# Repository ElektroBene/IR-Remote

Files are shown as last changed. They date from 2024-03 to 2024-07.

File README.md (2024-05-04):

# IR-Remote
## Introduction
This is a project for the course "microelectrical systems and design" in the electrical engineering and computer science studies at the Aschaffenburg University of Applied Sciences. The project will contain schematics and assembly code to build a custom infrared remote with the standard RC5 protocol.

## Schematics
- v1: basic schematic to show inputs and outputs with pic18f452
- v2: proper schematic including reset circuit, quartz oscillator and power supply
- v3: proper layout with remote design
- v4: optimize inductor width, space management and add cooling area for power supply
- v5: reroute with pwm and interrupt pins, add cooling area for battery and gnd area

## Authors
Benedikt Schnörr,
Sebastian Pasinski

### Work Packages
- schematics in v1 and v2: Benedikt
- layout in v2: Sebastian
- schematics in v3: Benedikt, Sebastian
- layout in v3: Benedikt, Sebastian
- layout in v4/5: Benedikt
- code for rc5 protocol: Benedikt

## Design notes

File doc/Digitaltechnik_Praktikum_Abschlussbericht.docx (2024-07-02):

# Digitaltechnik-Praktikum

Sommer-Semester 2024

Projekt: IR-Remote

Team: Sebastian Pasinski, Benedikt Schnörr

Prüfer: Prof. Dr. Francesco Volpe

# Planung

## Aufgabenstellung

Die Aufgabenstellung für das Digitaltechnik-Praktikum ist es, eine Infrarot-Fernbedienung zu bauen. Diese soll einen Receiver ansteuern, welcher das RC5-Protokoll unterstützt. Es sollen die wichtigsten Funktionen eines CD-Players mit der Fernbedienung angesprochen werden können. Dazu gehören:

- Play
- Stop
- Pause
- Forward (vorspulen)
- Backward (zurückspulen)

## Anforderungen

Die Anforderungen für dieses System sind, dass es auf einer eigenen Platine aufgebaut und batteriebetrieben arbeiten soll. Im Verlauf des Projekts wird zunächst ein Schaltplan entworfen, der die elektrischen Bauteile und den Mikrocontroller enthält, sodass daraufhin eine Platine designt und die Bauteile bestellt werden können. Im zweiten Schritt wird dann der Code entwickelt, mit dem die gedrückte Taste auf der Fernbedienung ausgelesen und das passende Signal als RC5-Code gesendet wird.

## Anwendungsfalldiagramm

Die grundlegende Funktionsweise des Systems wird in Abb.1 dargestellt.

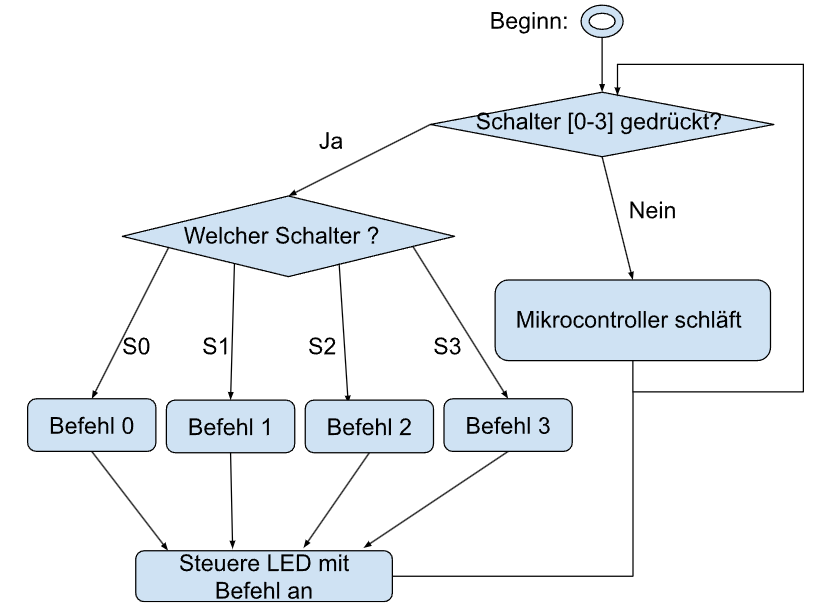
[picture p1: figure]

Abb. 1: Anwendungsfalldiagramm der Funktionsweise im System

## Skizze

In Abb. 2 ist eine grobe Skizze der Fernbedienung zu sehen, um die Funktionen der einzelnen Taster zuzuordnen.

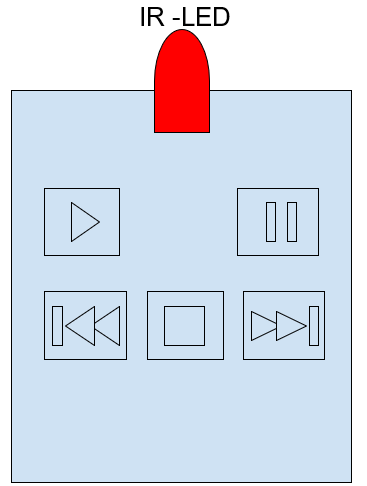
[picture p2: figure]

Abb. 2: Skizze der Fernbedienung

# Schaltplan

## Mikrocontroller

Der in der Schaltung verwendete Mikrocontroller ist ein PIC18F4525, an ihn sind neben Schaltern und Infrarot-LED noch weitere Schaltkreise angeschlossen. In Eagle wird zur Darstellung ein PIC18F4520 verwendet, der aber die gleiche Pin-Belegung und die gleichen Abmessungen wie der PIC18F4525 besitzt und daher als Alternative im Schaltplan benutzt werden kann.

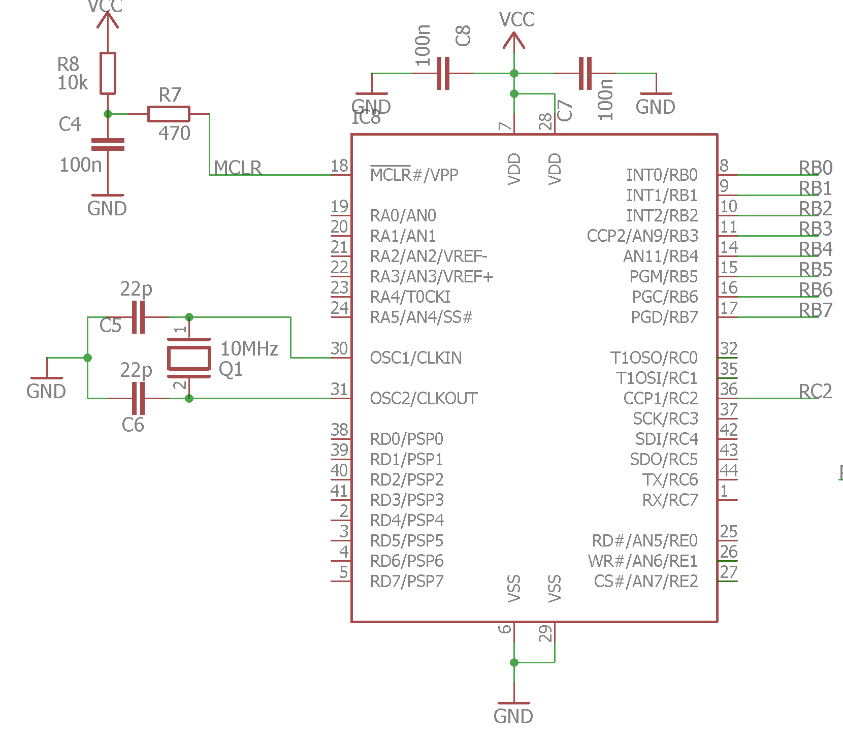
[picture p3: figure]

Abb. 3: Grundschaltung des PIC18F4525 mit Quarz, Reset und I/O

### Taktgebung

Der Quarz dient als externer Oszillator für den Mikrocontroller, der die Taktfrequenz vorgibt. Das Datenblatt des PIC18F4525 empfiehlt für die Oszillator-Konfiguration “High Speed Crystal/Resonators” mit einer Frequenz von 10 MHz die Verwendung von Kondensatoren mit einer Kapazität von 15 pF. In der vorgegebenen Schaltung wurde eine höhere Kapazität verwendet, dies verbessert die Stabilität der Schaltung, kann aber zur Vergrößerung der Startzeit führen [1].

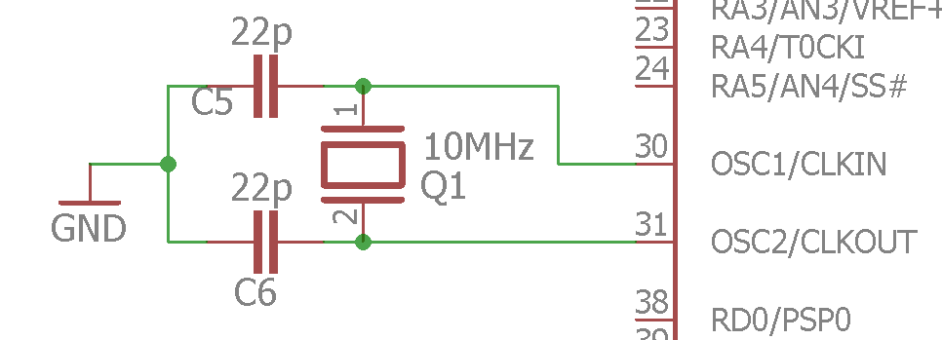
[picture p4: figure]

Abb. 4: Quarzoszillator mit Kapazitäten

## Programmier-/Debugging-Schnittstelle

Die in Abbildung 5 dargestellten Schaltungsblöcke ermöglichen das Programmieren und Debuggen des PIC [1].

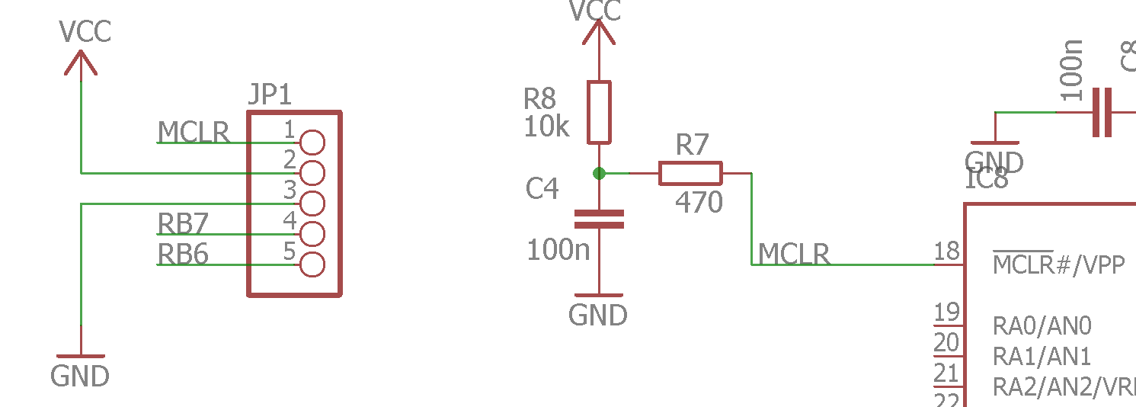
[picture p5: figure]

Abb. 5: Schnittstelle des Mikrocontrollers zum Debuggen/Programmieren

## Spannungsregulierung

Da die Schaltung laut Anforderungen mit einer 9 V-Batterie betrieben wird, muss ein Spannungsregulierer eingesetzt werden, um die Spannung auf die Betriebsspannung des PIC von 5 V zu reduzieren. In der fertigen Schaltung wird dazu der ON Semiconductor NCV1117ST50 genutzt. Im Schaltplan wird allerdings ein AP1117E50G eingesetzt, der die gleiche Pin-Belegung und Funktionsweise besitzt. Die Kapazitäten an Ein- und Ausgang sorgen dafür, dass der Regelkreis im Chip des Spannungsregulierers nicht beginnt zu schwingen. Diese Fähigkeit ist wichtig, um eine stabile Ausgangsspannung bereitzustellen.

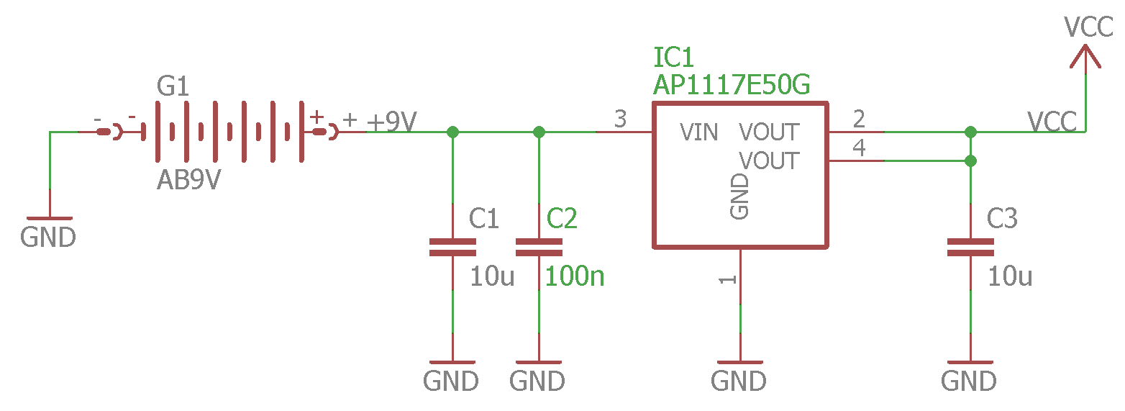
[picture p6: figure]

Abb. 6: Batterie mit Spannungsregulierer und Kapazitäten

## Schalter

Die Schalter, welche an verschiedenen Pins von Port B des Mikrocontrollers angeschlossen sind, sorgen dafür, dass im ausgeschalteten Zustand die Versorgungsspannung von 5 V am jeweiligen Pin anliegt. Im angeschalteten Zustand werden die Pins auf Masse gezogen.

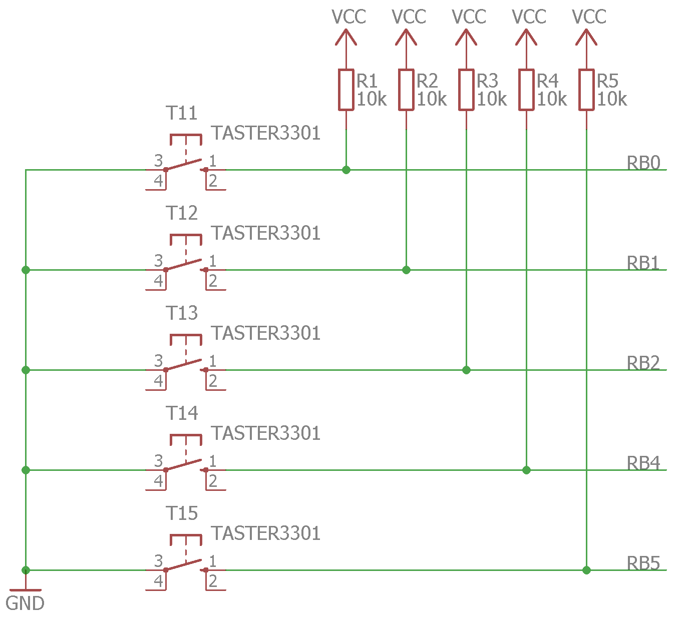
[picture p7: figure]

Abb. 7: Verschaltung der Taster als Active-Low-Elemente

## IR-LED

Für das Aussenden der Lichtsignale wird eine 5 mm Vishay Infrarot-LED verwendet. Der Vorwiderstand berechnet sich mit dem Spannungsabfall an der LED und dem gewünschten Strom im diesem Zweig. Laut Datenblatt liegt die Nennspannung bei 1,35 V, der Nennstrom kann bis zu 100 mA betragen [5]. Mit dem Ohm’schen Gesetz ergibt sich ein Widerstand von 36,5 Ω. Mit dieser Berechnung wird ein Widerstand von 47 Ω gewählt, damit der Strom durch die LED mit Sicherheit nicht zu groß wird.

Die LED wird an Pin RC1 angeschlossen, da an diesem Pin mit wenig Aufwand eine modulierte Rechteckspannung mit dem PWM-Modul des PIC ausgegeben werden kann. Diese wird für das RC5-Protokoll benötigt.

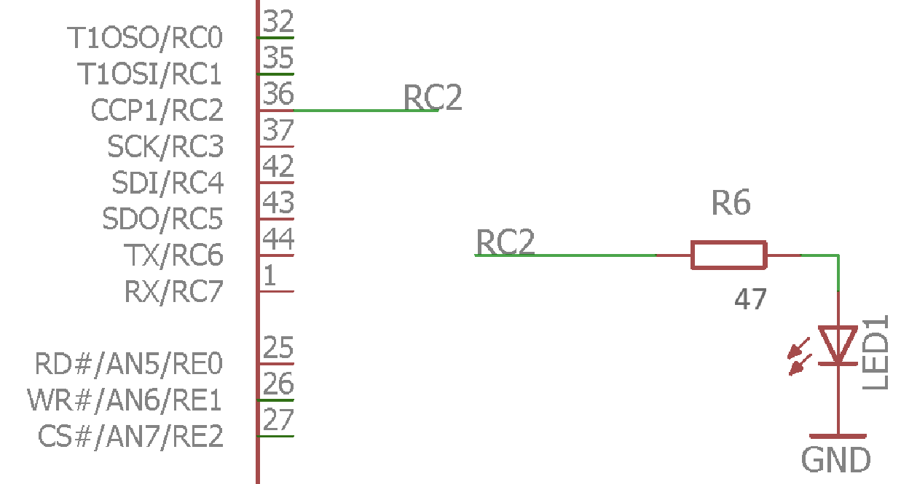
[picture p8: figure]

Abb. 8: Verschaltung der IR-LED mit Vorwiderstand

# Layout

In Abb. 9 ist das finale Layout zu sehen, mit dem auch die reale Platine erstellt wurde.

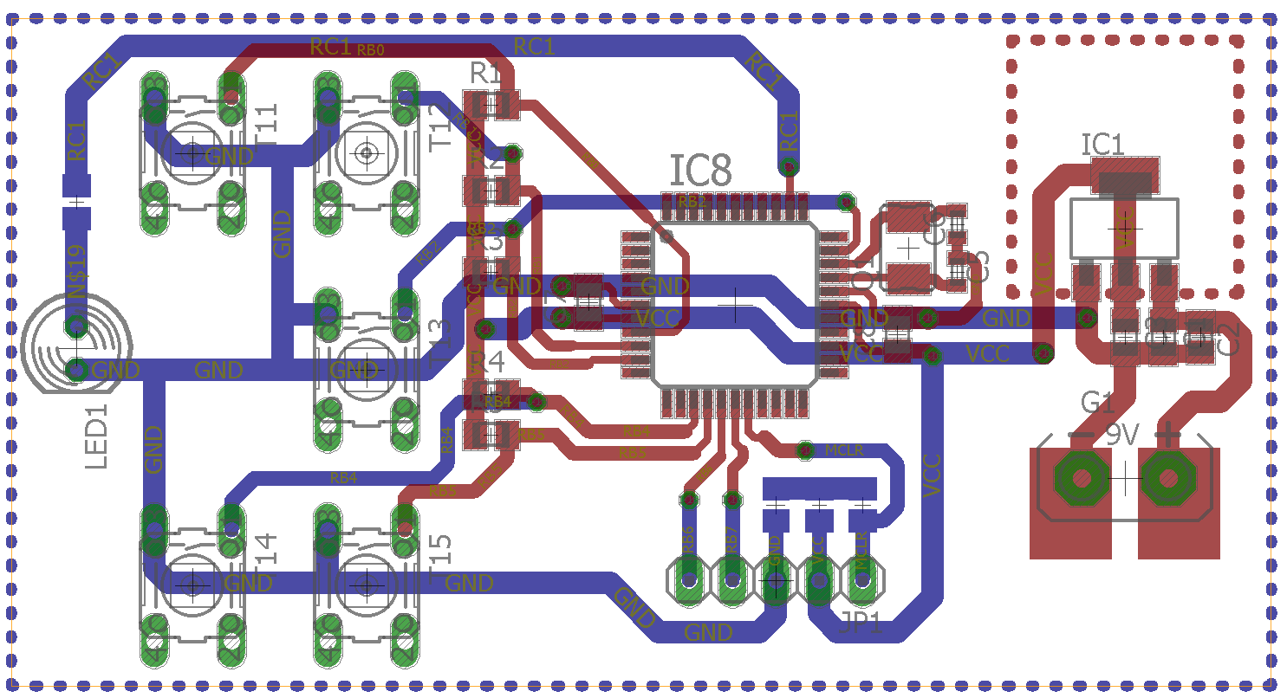
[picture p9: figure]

Abb. 9: PCB-Layout in Eagle mit Platzierung und Routing

## Anordnung der Bauteile

Beim Layout werden zuerst funktionale Gruppen mit Bauteilen, die direkt miteinander verbunden sind, gebildet. Diese werden dann auf der Platine angeordnet. Die funktionale Gruppe um den Quarz sollte möglichst nah an den angeschlossenen Eingängen des Mikrocontrollers liegen, da der Quarz sehr anfällig gegenüber Störsignalen ist.

Die Kondensatoren C7 und C8 liegen ebenfalls möglichst nah an den verbundenen Pins zur Stromversorgung, um Schwankungen in der Versorgungsspannung durch Störungen möglichst schnell auszugleichen.

Zusätzlich ist bei der Spannungsregulierung eine Kühlfläche vorgesehen, um die entstehende Wärme möglichst gut zu verteilen und den Chip dadurch zu kühlen.

Die Taster werden so angeordnet wie das bei handelsüblichen Fernbedienungen der Fall ist und in Abb.2 skizziert wurde. Auch die Anordnung der LED am vorderen und die der Batterie am hinteren Ende der Fernbedienung wird aus bekannten Fernbedienungen übernommen.

## Routing

Beim Routing wird besonders darauf geachtet, genug Abstand zwischen den Leiterbahnen einzuhalten und möglichst breite Leiterbahnen und keine rechten Winkel zu verwenden. Diese Grundsätze helfen, elektromagnetische Störungen zu minimieren.

Die Unterseite der Platine besteht zum größten Teil aus einer Masse-Fläche, so werden Masse-Schleifen vermieden und das Routing der Masse-Leitungen vereinfacht [6].

Die Größe und Form der Durchkontaktierungen, die Breite der Leiterbahnen und die Dimensionen von Tastern und SMD-Bauteilen wurden in Absprache mit dem Labor gewählt.

## Platine

Die fertige Platine ist in den Abbildungen 10 und 11 zu sehen.

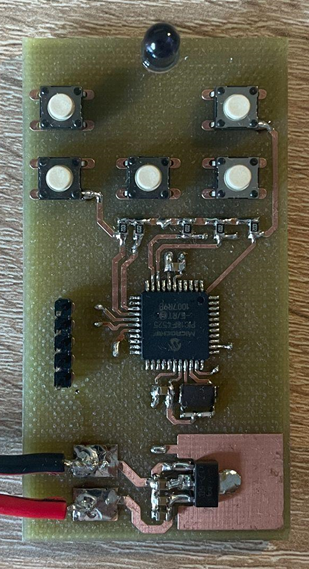
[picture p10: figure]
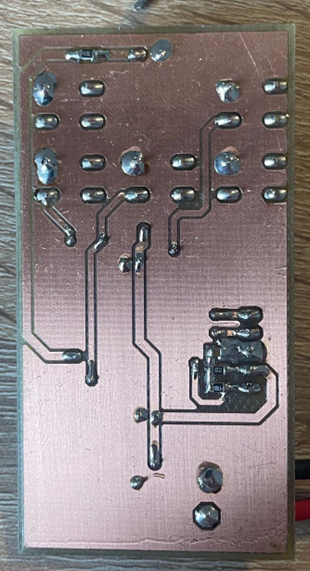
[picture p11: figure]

Abb. 10 (links): Fertige Platine obere Seite, Abb. 11 (rechts): untere Seite

# Software

Nachdem die Hardware fertiggestellt ist, fehlt für eine funktionsfähige Fernbedienung nur noch die Programmierung des Mikrocontrollers. Diese wird zunächst in 2 Teile aufgeteilt. Der erste Teil beschäftigt sich mit dem Auslesen der gedrückten Taster und dem Zuordnen von Taster und Befehl. Im zweiten Teil wird der Befehl dann mit dem RC5-Protokoll gesendet.

## Einsatz von Interrupts

Damit eine dauerhafte Schleife im Hauptprogramm vermieden werden kann, welche die Pegel an den Pins abfragt, kann die Interrupt-Funktion des Mikrocontrollers verwendet werden. So kann der PIC die meiste Zeit in den Sleep-Modus versetzt werden und spart dadurch Energie.

Das Hauptprogramm wird im Sleep-Modus gestoppt. Dann kann jederzeit durch eine Spannungsänderung an einem Interrupt-Pin eine Unterroutine aufgerufen werden, die den gedrückten Taster ausliest und den passenden Befehl sendet.

Der Ablauf dabei ist wie folgt: Bei einem Interrupt vervollständigt der Microcontroller die letzte Anweisung und speichert den Inhalt des Program-Counters und des Status-Registers auf dem Stack. Dann lädt er automatisch die Adresse 0x0008 (spezifisch bei PIC18F4525) in den Program-Counter und springt so an diese Stelle im Programm, um dort eine vom Benutzer geschriebene Routine auszuführen. Vor der letzten Anweisung muss das entsprechende Interrupt Flag, welches gesetzt wurde, um das Auftreten der Unterbrechung zu kennzeichnen, wieder zurückgesetzt werden. Die letzte Anweisung der Routine sorgt für eine sichere Rückkehr des Program-Counters zum aktuellen Befehl in der Hauptroutine, weitere Unterbrechungen werden dann wieder ermöglicht [3].

## Initialisierung der Interrupts im Programm

In der Fernbedienung werden verschiedene Interrupts genutzt. Die Taster an den Pins RB 0, 1 und 2 lösen die flankengesteuerten, externen Interrupts INT0, INT1 und INT2 aus. Die Pins RB 4 und 5 dagegen lösen Port B On Change-Interrupts aus, welche auf Zustandsänderungen der beiden Pins reagieren. Diese Interrupts werden im Folgenden initialisiert.

Dies geschieht durch das Setzen oder Rücksetzen spezieller Bits in den passenden Konfigurations-Registern, um die Einstellungen der Interrupts festzulegen.

Dabei ist es wichtig die Interrupt-Flags zurückzusetzen, damit keine fälschliche Unterbrechung stattfindet, bevor das Hauptprogramm gestartet wird. Außerdem werden die Interrupts durch das Setzen des jeweiligen Interrupt Enable-Bits aktiviert und ihre Priorität festgelegt. Im Fall von INT0/INT1/INT2 wird auch die Flanke angegeben, bei welcher ein Interrupt ausgelöst wird. Am Ende werden die Global Interrupt Enable-Bits gesetzt, um die Interrupts mit hoher und niedriger Priorität im Allgemeinen zu aktivieren.

init_portb:

clrf PORTB ; reset port b and its latch

clrf LATB

bcf ADCON0,ADON

; disable ad converter and reset its configuration bits

movlw 0xFF ; declare all Pins at PORTB as digital

movwf ADCON1 ; pins

movlw 0xFF ; set all port b pins as inputs

movwf TRISB

movlw b'00111011' ; set pins with buttons to '1' to prevent

movwf PORTB

;triggering interrupt because buttons

;create high state as default (active low buttons)

bcf INTCON,INT0IF ; clear interrupt flags for pins rb

bcf INTCON3,INT1IF ; 0/1/2/4/5 to prevent getting multiple

bcf INTCON3,INT2IF ; interrupts with one button press

bcf INTCON,RBIF

bcf INTCON2,RBPU

; activate internal weak pull-ups for all pins on port b

bsf INTCON,INT0IE

bsf INTCON3,INT1IE

bsf INTCON3,INT2IE

bsf INTCON,RBIE

; enable interrupts for interrupt 0/1/2 and on change

; interrupts on port b

bcf INTCON2,INTEDG0

bcf INTCON2,INTEDG1

bcf INTCON2,INTEDG2

; set interrupts 0/1/2 to trigger on falling edge

bsf RCON,IPEN ; enable interrupt priorities

bsf INTCON3,INT1IP

; set interrupt priority for interrupts 1 & 2 , (0 always high)

bsf INTCON3,INT2IP

; and on change interrupt to high priority

bsf INTCON2,RBIP

bsf INTCON,GIEH

; activate all high priority interrupts

bsf INTCON,GIEL

;activate all low priority interrupts

bsf INTCON,GIE

; activate all interrupts

return

## Interrupt-Routine

Um in der Anwendung des Programms nachvollziehen zu können, welcher Schalter gedrückt wurde, wurde innerhalb der High Interrupt Routine ein Algorithmus implementiert, welcher die jeweiligen Interrupt-Flags und die Zustände der Pins abfragt. Wenn der entsprechende Schalter erkannt wurde, wird eine Sendefunktion mit einem bestimmten RC5-Befehl ausgeführt, welche dann den passenden Befehl lädt.

HighInt:

btfsc INTCON,RBIF ; pin 4/5 pressed

call send_rb_on_change

btfsc INTCON,INT0IF ; pin 0 pressed

call send_rb_0

btfsc INTCON3,INT1IF ; pin 1 pressed

call send_rb_1

btfsc INTCON3,INT2IF ; pin 2 pressed

call send_rb_2

retfie FAST

In der Interrupt-Routine wird also zuerst ermittelt, ob sich eine Änderung an den Pins RB4 und RB5 ereignet hat. In der Routine send_rb_on_change wird dann mit den Pin-Zuständen ermittelt, welcher Pin genau für den Interrupt verantwortlich war.

send_rb_on_change:

btfss PORTB,4 ; check if pin 4 was pressed

call send_rb_4

btfss PORTB,5 ; check if pin 5 was pressed

call send_rb_5

bcf INTCON,RBIF ; clear interrupt flag to prevent multiple

; interrupts

return

In den daraufhin aufgerufenen Sende-Routinen wird das Interrupt-Flag zurückgesetzt, um mehrfache Unterbrechungen zu vermeiden und wieder in das Hauptprogramm zu springen. Außerdem wird der Bit-Buffer, welcher die Befehle zum Senden enthält, mit dem passenden Befehl überschrieben. Hier ist beispielhaft eine Sende-Routine dargestellt.

send_rb_0:

bsf skip_release,0 ; set skip_release<0> to prevent

; skipping this command

movlw b'00110101' ; move rc5 code for stop command to

movwf bit_buffer_h ; bit buffer

movlw b'00110110' ; 00 in beginning not significant

movwf bit_buffer_l

bcf INTCON,INT0IF ; clear interrupt flag to prevent

; multiple interrupts

return

Die Schnittstelle wurde am Modell getestet, um das Programmverhalten beim Drücken der Taster zu beobachten.

## Bitübertragung mit dem RC5-Protokoll

Das RC5-Protokoll ist eine von Philips entwickelte Methode zur Kommunikation mit verschiedenen Endgeräten, wie z.B. CD-Spielern und Fernsehern. Eine Fernbedienung für dieses Protokoll sendet mit einer Wellenlänge von 940 bis 950 nm, welche bei der verwendeten Infrarot-LED mit 940 nm gegeben ist. Ein Befehl der Fernbedienung besteht aus insgesamt 14 Bits, die nacheinander gesendet werden. Die Bits sind in Abb. 13 dargestellt und haben die folgende Bedeutung [7]:

- 2 Start-Bits, immer logisch ‚1’
- 1 Toggle-Bit, welches seinen Wert bei jedem neuen Tastendruck ändert
- 5 Adress-Bits, um ein konkretes Gerät anzusprechen, wie bspw. CD-Player, TV, Audio-Vorverstärker
- 6 Befehls-Bits

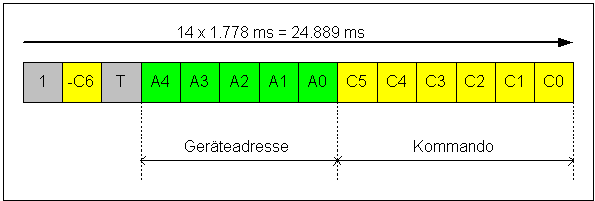
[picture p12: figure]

Abb. 12: Zeitliche Abfolge der Bits im RC5-Befehl

Ein Bit besteht dabei immer aus einer Low-Phase und einer Puls-Phase mit einer Länge von je 888,89 μs. Wie in Abb. 12 zu sehen, verändert die Reihenfolge dieser zwei Phasen den Zustand des Bits zwischen High und Low [7].

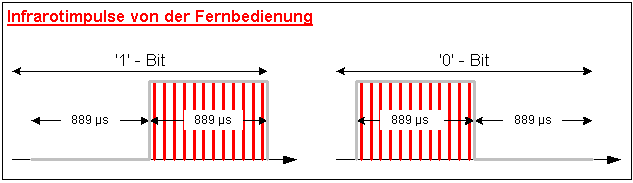
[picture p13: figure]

Abb. 13: Reihenfolge der Puls- und Ruhephasen und deren Bedeutung als Bit

Eine Puls-Phase besteht dabei immer aus 32 einzelnen Pulsen einer Rechteckspannung mit einer Frequenz von 36 kHz. Die Dauer der High-Phasen der einzelnen Pulse ist etwa ⅓ bis ¼ der Periodendauer der Rechteckschwingung. So wird weniger Leistung benötigt, als bei einer High-Phase von 50%.

## Konfiguration des PWM-Moduls

Die Rechtecksignale werden an Pin RC1 mit dem „Capture/Compare/PWM Module (CCP)” im PWM-Modus erzeugt. Alle nachfolgenden Ausführungen beruhen auf Informationen im Kapitel 15.4 des Handbuchs für den PIC18F4525 [1].

Bei der Konfiguration wird zunächst die Periodendauer bzw. Frequenz der benötigten Trägerschwingung definiert. Diese kann über die Gleichungen 1 und 2 berechnet werden.

T_(Period) =[n_(PR2) +1]⋅4⋅T_(OSC) ⋅n_(TMR)

Gleichung 1

n_(PR2) =(f_(OSC))/(4⋅f_(Period) ⋅n_(TMR))-1≈44h

Gleichung 2

Die Frequenz fPeriod ist dabei die Träger-Frequenz von 36 kHz. Die Frequenz des Oszillators fOSC ist durch den 10 MHz-Quarz vorgegeben. Der Prescaler-Value nTMR = 1 wird aus den Beispielen im Handbuch gewählt. Der berechnete Wert nPR2 wird bei der Konfiguration in das PR2-Register eingetragen, um die gewünschte Frequenz der Rechteckspannung zu erreichen. Durch Leitungsverzögerungen und Ungenauigkeiten in der Schaltung muss dieser Wert im realen Programm angepasst werden.

Außerdem muss der Wert für den Duty Cycle berechnet und eingestellt werden. Aus Gleichung 3, die von Microchip vorgegeben wurde [8], ergibt sich ein Wert von 0,250. Da dieser Wert in diesem Zusammenhang nicht als zehnstellige binäre Zahl dienen kann, wird dieser Wert experimentell zu 0x54 bestimmt. Die ersten acht MSBs werden in das CCPR2L-Register und die zwei verbleibenden LSBs in das CCP2CON-Register an Stelle 5 und 4 eingetragen.

Pulse Width=(CCPR2L:CCP2CON<5:4> ⋅1/(f_(OSC))⋅n_(TMR) )

Gleichung 3

init_pwm:

banksel PR2

movlw 0x46 ; configure period time with 0x46 for

movwf PR2 ; 36 kHz frequency

movlw b'00010101' ; configure duty cycle to be between 1/3

movwf CCPR2L ; and 1/4 of the whole signal

movlw b'00001100' ; configure pwm mode and 2 lsbs of

movwf CCP2CON ; duty cycle

bcf PIR1,TMR2IF ; clear interrupt flag to prevent

; multiple interrupts

bcf T2CON,T2CKPS1 ; set timer 2 clock prescaler value

bcf T2CON,T2CKPS0 ; to ‘00’

## Konfiguration von Timer 0

Während die Rechteckspannung von CCP-Modul und Timer 2 erzeugt wird, muss auch die Sendedauer der Rechteckspannung reguliert werden. Wie bereits erwähnt, werden in der Sendephase für jedes Bit 32 Pulse gesendet, dies entspricht einer Dauer von 888,89 μs. Diese Sendedauer wird von Timer 0 beendet, der von einem entsprechend eingestellten Wert bis zum Überlauf hochzählt. Beim Überlauf von 0xFFFF zu 0x0000 wird ein Interrupt erzeugt, über dessen Interrupt Service Routine dann die Sendephase beendet werden kann. Der Startwert des Timers ergibt sich durch die Berechnungen in Gleichung 4 [9].

f_(OSC) =10MHz → f_(Timer) =(f_(OSC))/4=2,5MHz→T_(Timer) =1/(f_(Timer))=0,4μs

n_(Timer) =65536-(T_(Sendedauer))/(T_(Timer))=65536-(888,89μs)/(0,4μs)≈0xF752

Gleichung 4

Im Code wird der Timer dann als 16 Bit-Timer konfiguriert, der mit der Taktfrequenz des PIC vom Startwert 0xF752 hochzählt. Der Prescaler-Wert folgt ebenfalls aus den Berechnungen und kann hier auf “000” gesetzt werden. Außerdem wird für den Overflow von Timer 0 ein Low Priority Interrupt aktiviert, der, wie bereits erwähnt, das Ende der Dauer eines halben gesendeten Bits markiert.

movlw b'00001000' ; configure timer 0 with 16 bit, internal

movwf T0CON ; clock and prescaler value of '000'

movlw 0xF7 ; set start value for timer 0

movwf TMR0H

movlw 0x52

movwf TMR0L

bcf INTCON,TMR0IF ; clear interrupt flag to prevent multiple

; interrupts

bsf INTCON,TMR0IE ; enable timer 0 interrupt

bcf INTCON2,TMR0IP ; set interrupt priority to low

bsf INTCON,GIE ; enable all interrupt

## RC5-Übertragung im Code

Der folgende Code-Ausschnitt zeigt beispielhaft die Übertragung einer logischen ‚0’ in Assembler. Dabei wird aus der Main-Routine die entsprechende Sende-Routine aufgerufen, die dann zuerst 888,89 μs lang die 32 Pulse der Rechteckspannung sendet und dann 888,89 μs lang den Ausgang auf den Low-Zustand legt.

send_0:

call pwm_delay ; send logic '0' by first sending 32 pwm

call tmr_delay ; pulses and then 889 us delay

return

In der pwm_delay-Routine werden Timer 0 und Timer 2 auf ihre Anfangswerte gesetzt und dann gestartet. Beim Ausführen des Codes auf dem realen PIC wurde festgestellt, dass der erste Puls nur aus einer Low-Phase besteht, daher wird der Ausgangspin vor dem Starten des ersten Pulses manuell gesetzt.

pwm_delay:

movlw 0xF7 ; set start value for timer 0 which

movwf TMR0H ; counts to overflow

movlw 0x70

movwf TMR0L

movlw 0x00 ; set start value for timer 2 which

movwf TMR2 ; counts for each pulse

bsf LATC,1 ; set first pulse manually

bsf T0CON,TMR0ON ; start timer 0 for 889 us delay

bsf T2CON,TMR2ON ; and timer 2 for pwm

call delay_loop ; wait for timer 0 low interrupt

return

Die tmr_delay-Routine ist ähnlich aufgebaut. Sie startet allerdings nur Timer 0 und nicht Timer 2, da für die Ruhephase nur Timer 0 gebraucht wird, um die 888,89 μs abzuzählen.

tmr_delay:

;start timer 0 for pausing

movlw 0xF7 ; set start value for timer 0 which counts

movwf TMR0H ; to overflow

movlw 0x70

movwf TMR0L

bsf T0CON,TMR0ON ; start timer 0

call delay_loop ; wait for timer 0 low interrupt

return

Außerdem gibt es noch eine Routine, die durchlaufen wird, bis ein Timer 0 Low Interrupt ausgelöst wird. Diese Schleife wartet darauf, dass das tmr_done-Flag von der Low Interrupt-Routine gesetzt wird.

delay_loop: ;wait for timer 0 interrupt to end half bit

btfss tmr_done,0

bra delay_loop

bcf tmr_done,0

return

In der Low Interrupt-Routine werden dann die Timer gestoppt, die das halbe Bit erzeugen, und das bereits erwähnte tmr_done-Flag gesetzt.

LowInt:

bcf T0CON,TMR0ON ; stop timers 0 and 2 which are used for

bcf T2CON,TMR2ON ; pwm pulses and do not need to be used

; after sending these pulses is finished

bcf INTCON,TMR0IF ; clear interrupt flag of timer 0 which

; triggers the low interrupt, clearing

; prevents multiple interrupts for one

; overflow event

bsf tmr_done,0

retfie FAST

## Main-Routine

In der Main-Routine, die zuerst ausgeführt wird, werden zunächst alle Routinen zur Initialisierung aufgerufen. So werden die Kontrollbits für die Ein- und Ausgangsports und das PWM-Modul, wie in den vorherigen Abschnitten angesprochen, passend gesetzt.

Main:

call init_portc ; configure ports and pwm module

call init_portb

call init_ports

call init_pwm

Dann wird der Mikrocontroller direkt in den Sleep-Modus versetzt, um dort auf den nächsten Tastendruck und den dadurch ausgelösten Interrupt zu warten. Dazu wird das IDLEN-Bit zurückgesetzt, womit der Modus des Mikrocontrollers ausgewählt werden kann.

wait_cmd_loop

bcf OSCCON,IDLEN ; go to sleep until next button is pressed

sleep

nop

nop

nop

Nachdem der PIC dann durch einen Tastendruck in den normalen Run-Modus versetzt und der gewünschte Befehl in der Interrupt-Routine in den Bit-Buffer kopiert wurde, wird das Toggle-Bit des Befehls angepasst. Wie im Abschnitt zur Theorie hinter dem RC5-Code erwähnt, toggelt dieses Bit bei jedem neu gesendeten Befehl. Das Toggeln und Setzen im Bit-Buffer ist im folgenden Code-Abschnitt dargestellt.

btg bit_buffer_toggle,0 ; set toggle bit in bit_buffer

btfsc bit_buffer_toggle,0

bsf bit_buffer_h,3

btfss bit_buffer_toggle,0

bcf bit_buffer_h,3

Dann werden die Sende-Routinen gestartet. Dazu werden die Bits des Bit-Buffers nach und nach in das Carry-Bit übernommen und dann die passende Sende-Routine für eine logische ‚0’ oder ‚1’ gestartet. Damit der Bit-Buffer seinen Wert behält und beim Senden nicht verloren geht, werden die Schiebe-Operation mit einem temporären Bit-Buffer durchgeführt, dessen Wert vor dem Senden aus dem Bit-Buffer kopiert wird.

Die ersten zwei Bits werden beim Senden übersprungen, da ein Befehl beim RC5-Code immer nur 14 Bits enthält. Der Bit-Counter zählt diese 14 Bits ab und beendet die Sende-Schleife, wenn alle Bits gesendet wurden.

send_cmd_loop

movlw d'14' ; send 14 bits

movwf bit_ctr

clrf tmr_done ; reset flag that stops delay loop

; during sending

movf bit_buffer_h,W ; send bit buffer from temporary

; constants to keep value

movwf bit_buffer_h_tmp

movf bit_buffer_l,W

movwf bit_buffer_l_tmp

rlcf bit_buffer_l_tmp ; skip first 2 bits because only 14

rlcf bit_buffer_h_tmp ; bits hold information

rlcf bit_buffer_l_tmp

rlcf bit_buffer_h_tmp

send_bit_loop

rlcf bit_buffer_l_tmp ; transfer the next bit that should

rlcf bit_buffer_h_tmp ; be sent in carry bit

btfss STATUS,C ; test carry bit to see if '0' or

call send_0 ; '1' should be sent

btfsc STATUS,C

call send_1

decfsz bit_ctr ; send next bit if not all bits are

bra send_bit_loop ; sent already

Dieser Sende-Vorgang wird für den zu sendenden Befehl mehrmals wiederholt. Dies beruht auf der Beobachtung, dass der Empfänger bei einzeln gesendeten Befehlen nicht zuverlässig reagiert. Das mehrmalige Senden simuliert einen längeren Tastendruck, da ein richtiger Algorithmus für längere Tastendrücke aus Zeitgründen nicht realisiert werden konnte. Hierfür wird der Command-Counter zuerst mit der Anzahl der für einen Tastendruck gesendeten Befehle initialisiert.

movlw d'3' ; send every command 3 times

movwf cmd_ctr

Dieser Counter wird nach dem Senden des Befehls dekrementiert, um die Sende-Routine so oft durchzuführen, wie bei der Initialisierung gewünscht.

decfsz cmd_ctr ; send command again if it was not sent 3

bra send_cmd_loop ; times already

Zwischen den gesendeten Befehlen wird mit dem folgenden Code-Abschnitt eine Pause eingebaut. So kann der Empfänger besser zwischen den Befehlen unterscheiden. Dieses Prinzip wurde der tatsächlichen Fernbedienung des CD-Spielers entnommen. Der Code besteht aus zwei verschachtelten Schleifen, deren Zähler nacheinander herunterzählen. Die Verzögerung, die durch diesen Code entsteht, liegt bei ca. 9 ms.

movlw 0xFF ; load inner and outer delay counter to

movwf rand_delay_ctr ; create delay between sending the

movlw 0x40 ; command multiple times

movwf rand_delay_ctr_outer

wait_rand_delay_outer ; create delay of around 9 ms

wait_rand_delay

nop

nop

decfsz rand_delay_ctr

bra wait_rand_delay

decfsz rand_delay_ctr_outer

bra wait_rand_delay_outer

Wenn der Befehl mehrmals gesendet wurde, wird der PIC wieder in den Sleep-Modus versetzt, um auf den nächsten Befehl zu warten.

bra wait_cmd_loop ; go to sleep after sending 3 commands

Eine weitere Beobachtung war, dass der Befehl beim Drücken der Taster an den Pins RB4 und RB5 zweimal gesendet wurde. Die On Change-Interrupts dieser Pins sind nämlich sowohl auf die steigende, wie auch auf die fallende Flanke sensitiv. Als Lösung wird das skip_release-Flag eingeführt. Dieses wird bei jedem der zwei ausgelösten Interrupts getoggelt, sodass es für die zwei Flanken unterschiedliche Werte hat. Das Senden des Befehls wird dann ausgesetzt, wenn das Flag den Wert ‚1’ hat, also der Interrupt beim Drücken der Taste und nicht beim Loslassen erzeugt wurde. So wird für einen Tastendruck auch nur einmal die Sende-Routine durchlaufen. Beim Interrupt durch RB0, RB1 und RB2 wird das Bit manuell in der Interrupt-Routine gesetzt, um diesen Befehl auf jeden Fall zu senden. Der folgende Code-Abschnitt zeigt den Einstiegspunkt beim Überspringen des Befehls und die Abfrage des Flags.

skip_cmd

movlw 0x00 ; initialize skip_release flag

movwf skip_release

wait_cmd_loop

bcf OSCCON,IDLEN ; go to sleep until next button is

sleep ; pressed

btfss skip_release,0 ; skip second command when button is

bra skip_cmd ; released at rb4 and rb5 because

; interrupt is triggered on change, not

; only on falling edge

# Vollständiger Code

LIST P=18F4525 ; directive to define processor

#include "P18F4525.INC" ; processor specific variable definitions

;******************************************************************************

;Configuration bits

; Oscillator Selection:

CONFIG OSC = HS ; set oscillator mode to high-speed crystal with

; external 10 MHz quartz

CONFIG WDT = OFF ; disable watchdog timer

CONFIG LVP = OFF ; disable low voltage programming, because MPLAB

; ICD 3 can do high voltage programming

;******************************************************************************

;Variable definitions

bit_buffer_h equ 0x00 ; hold bits 13-8 of command

bit_buffer_l equ 0x01 ; hold bits 7-0 of command

bit_ctr equ 0x02 ; count 14 bits while sending

tmr_done equ 0x03 ; signal that half bit is finished

cmd_ctr equ 0x04 ; count times of sending command

skip_release equ 0x05 ; decide between falling and rising edge at rb 4/5

bit_buffer_toggle equ 0x06 ; toggle 3rd sent bit

bit_buffer_h_tmp equ 0x07 ; hold bits 13-8 of command while sending

bit_buffer_l_tmp equ 0x08 ; hold bits 7-0 of command while sending

rand_delay_ctr equ 0x09 ; count during inner delay loop between commands

rand_delay_ctr_outer equ 0x0A ; count during outer delay loop between commands

;******************************************************************************

;EEPROM data

ORG 0xf00000

DE "Test Data",0,1,2,3,4,5

;******************************************************************************

;Reset vector

ORG 0x0000

goto Main ; go to start of main code

;******************************************************************************

;High priority interrupt vector

ORG 0x0008

bra HighInt ; go to high priority interrupt routine

;******************************************************************************

;High priority interrupt routine

HighInt:

call interrupt_routine ; read pressed button and put the right

; command in bit buffer to send it

bcf INTCON,INT0IF ; clear interrupt flags for pins rb

bcf INTCON3,INT1IF ; 0/1/2/4/5 to prevent getting multiple

bcf INTCON3,INT2IF ; interrupts with one button press

bcf INTCON,RBIF

retfie FAST ; pops the contents of the program counter

; previously pushed before going to the

; service routine, enables all interrupts,

; and returns control to the appropriate

; place in the main program.

;******************************************************************************

;Low priority interrupt vector

ORG 0x0018

bra LowInt ; go to high priority interrupt routine

;******************************************************************************

;Low priority interrupt routine

LowInt:

bcf T0CON,TMR0ON ; stop timers 0 and 2 which are used for pwm pulses

bcf T2CON,TMR2ON ; and do not need to be used after sending these

; pulses is finished

bcf INTCON,TMR0IF ; clear interrupt flag of timer 0 which triggers

; the low interrupt, clearing prevents multiple

; interrupts for one overflow event

bsf tmr_done,0

retfie FAST

;******************************************************************************

interrupt_routine:

; test interrupt flags to identify pressed button

btfsc INTCON,RBIF ; pin 4/5 pressed

call send_rb_on_change

btfsc INTCON,INT0IF ; pin 0 pressed

call send_rb_0

btfsc INTCON3,INT1IF ; pin 1 pressed

call send_rb_1

btfsc INTCON3,INT2IF ; pin 2 pressed

call send_rb_2

return

; handle pressing pin 4 or 5, because both pins trigger on change interrupt

send_rb_on_change:

btg skip_release,0 ; toggle skip_release flag to prevent sending

; commands twice (by pressing and releasing

; button), command is skipped when skip_release<0>

; is '0'

btfss PORTB,4 ; check if pin 4 was pressed

call send_rb_4

btfss PORTB,5 ; check if pin 5 was pressed

call send_rb_5

bcf INTCON,RBIF ; clear interrupt flag to prevent multiple

; interrupts

return

; send stop command with pin RB0

send_rb_0:

bsf skip_release,0 ; set skip_release<0> to prevent skipping this

; command

movlw b'00110101' ; move rc5 code for stop command to bit buffer

movwf bit_buffer_h

movlw b'00110110'

movwf bit_buffer_l

bcf INTCON,INT0IF ; clear interrupt flag to prevent multiple

; interrupts

return

; send forward command with pin RB1

send_rb_1:

bsf skip_release,0 ; set skip_release<0> to prevent skipping this

; command

movlw b'00110101' ; move rc5 code for forward command to bit buffer

movwf bit_buffer_h

movlw b'00110100'

movwf bit_buffer_l

bcf INTCON,INT1IF ; clear interrupt flag to prevent multiple

; interrupts

return

; send play/pause command with pin RB2

send_rb_2:

bsf skip_release,0 ; set skip_release<0> to prevent skipping this

; command

movlw b'00110101' ; move rc5 code for pause command to bit buffer

movwf bit_buffer_h

movlw b'00110000'

movwf bit_buffer_l

bcf INTCON,INT2IF ; clear interrupt flag to prevent multiple

; interrupts

return

; send mute command with pin RB4

send_rb_4:

movlw b'00110101' ; move rc5 code for play command to bit buffer

movwf bit_buffer_h

movlw b'00001100'

movwf bit_buffer_l

return

; send backward command

send_rb_5:

movlw b'00110101' ; move rc5 code for backward command to bit buffer

movwf bit_buffer_h

movlw b'00110010'

movwf bit_buffer_l

return

;******************************************************************************

;Initialization routines

; configure port c

init_portc:

clrf PORTC ; reset port c and its latch

clrf LATC

movlw b'11111101' ; set pin RC1 to be output, all other RC pins to be

movwf TRISC ; inputs

return

; configure port b as input with interrupts

init_portb:

clrf PORTB ; reset port b and its latch

clrf LATB

bcf ADCON0,ADON ; disable ad converter and reset its configuration

movlw 0xFF ; bits

movwf ADCON1

movlw 0xFF ; set all port b pins as inputs

movwf TRISB

movlw b'00111011' ; set pins with buttons to '1' to prevent

movwf PORTB ; triggering interrupt because buttons create

; high state as default (active low buttons)

bcf INTCON,INT0IF ; clear interrupt flags for pins rb

bcf INTCON3,INT1IF ; 0/1/2/4/5 to prevent getting multiple

bcf INTCON3,INT2IF ; interrupts with one button press

bcf INTCON,RBIF

bcf INTCON2,RBPU ; activate internal weak pull-ups for all pins

; on port b

bsf INTCON,INT0IE ; enable interrupts for interrupt 0/1/2 and

bsf INTCON3,INT1IE ; on change interrupts on port b

bsf INTCON3,INT2IE

bsf INTCON,RBIE

bcf INTCON2,INTEDG0 ; set interrupts 0/1/2 to trigger on falling

bcf INTCON2,INTEDG1 ; edge

bcf INTCON2,INTEDG2

bsf INTCON,GIEH ; activate all high priority interrupts

bsf INTCON,GIEL ; activate all low priority interrupts

bsf INTCON,GIE ; activate all interrupts

bsf RCON,IPEN ; enable interrupt priorities

bsf INTCON3,INT1IP ; set interrupt priority for interrupts 1/2

bsf INTCON3,INT2IP ; and on change interrupt to high priority

bsf INTCON2,RBIP

return

; configure ports a and d as inputs, routines are taken from pic18f4525 manual

init_ports

clrf PORTA ; initialize port a by clearing output data latches

clrf LATA

movlw 0x07 ; configure A/D for digital inputs

movwf ADCON1

movlw 0x07 ; configure comparators for digital input

movwf CMCON

movlw 0xFF ; initialize data direction for all pins as output

movwf TRISA

clrf PORTD ; initialize port d by clearing output data latches

clrf LATD

movlw 0FFh ; initialize data direction for all pins as output

movwf TRISD

return

; configure pwm module

init_pwm:

banksel PR2

movlw 0x46 ; configure period time with 0x46 for 36 kHz frequency

movwf PR2

movlw b'00010101' ; configure duty cycle to be between 1/3 and 1/4 of

movwf CCPR2L ; the whole signal

movlw b'00001100' ; configure pwm mode and 2 lsbs of duty cycle

movwf CCP2CON

bcf PIR1,TMR2IF ; clear interrupt flag to prevent multiple

; interrupts

bcf T2CON,T2CKPS1 ; set timer 2 clock prescaler value to '00'

bcf T2CON,T2CKPS0

movlw b'00001000' ; configure timer 0 with 16 bit, internal clock

movwf T0CON ; and prescaler value of '000'

movlw 0xF7 ; set start value for timer 0

movwf TMR0H

movlw 0x52

movwf TMR0L

bcf INTCON,TMR0IF ; clear interrupt flag to prevent multiple

; interrupts

bsf INTCON,TMR0IE ; enable timer 0 interrupt

bcf INTCON2,TMR0IP ; set interrupt priority to high

bsf INTCON,GIE ; enable all interrupts

return

;******************************************************************************

;Sending routines

; start half bit with low state by waiting for 889 us

tmr_delay:

;start timer 0 for pausing

movlw 0xF7 ; set start value for timer 0 which counts to overflow

movwf TMR0H

movlw 0x70

movwf TMR0L

bsf T0CON,TMR0ON ; start timer 0

call delay_loop ; wait for timer 0 low interrupt

return

; start half bit with rectangle signal by running pwm for 889 us

pwm_delay:

movlw 0xF7 ; set start value for timer 0 which counts to overflow

movwf TMR0H

movlw 0x70

movwf TMR0L

movlw 0x00 ; set start value for timer 2 which counts for each pulse

movwf TMR2

bsf LATC,1 ; set first pulse manually

bsf T0CON,TMR0ON ; start timer 0 for 889 us delay and timer 2 for pwm

bsf T2CON,TMR2ON

call delay_loop ; wait for timer 0 low interrupt

return

;wait for timer 0 interrupt to end half bit

delay_loop:

btfss tmr_done,0

bra delay_loop

bcf tmr_done,0

return

; send logic '1' by first sending 889 us delay and then 32 pwm pulses

send_1:

call tmr_delay

call pwm_delay

return

; send logic '0' by first sending 32 pwm pulses and then 889 us delay

send_0:

call pwm_delay

call tmr_delay

return

;******************************************************************************

;Start of main program

Main:

call init_portc ; configure ports and pwm module

call init_portb

call init_ports

call init_pwm

clrf bit_buffer_toggle

skip_cmd

; send when rb4 or rb5 pressed, skip when released

movlw 0x00

movwf skip_release

wait_cmd_loop

bcf OSCCON,IDLEN ; go to sleep until next button is pressed

sleep

nop

nop

nop

movlw d'3' ; send every command 3 times

movwf cmd_ctr

btfss skip_release,0 ; skip second command when button is released

bra skip_cmd ; at rb4 and rb5 because interrupt is triggered

; on change, not only on falling edge

btg bit_buffer_toggle,0 ; set toggle bit in bit_buffer

btfsc bit_buffer_toggle,0

bsf bit_buffer_h,3

btfss bit_buffer_toggle,0

bcf bit_buffer_h,3

send_cmd_loop

movlw d'14' ; send 14 bits

movwf bit_ctr

clrf tmr_done ; reset flag that stops delay loop during sending

movf bit_buffer_h,W ; send bit buffer from temporary constants to keep value

movwf bit_buffer_h_tmp

movf bit_buffer_l,W

movwf bit_buffer_l_tmp

rlcf bit_buffer_l_tmp ; skip first 2 bits because only 14 bits hold information

rlcf bit_buffer_h_tmp

rlcf bit_buffer_l_tmp

rlcf bit_buffer_h_tmp

send_bit_loop

rlcf bit_buffer_l_tmp ; transfer the next bit that should be sent in carry bit

rlcf bit_buffer_h_tmp

btfss STATUS,C ; test carry bit to see if '0' or '1' should be sent

call send_0

btfsc STATUS,C

call send_1

decfsz bit_ctr ; send next bit if not all bits are sent already

bra send_bit_loop

movlw 0xFF ; load inner and outer delay counter to create delay

movwf rand_delay_ctr ; between sending the command multiple times

movlw 0x40

movwf rand_delay_ctr_outer

wait_rand_delay_outer ; create delay of around 9 ms

wait_rand_delay

nop

nop

decfsz rand_delay_ctr

bra wait_rand_delay

decfsz rand_delay_ctr_outer

bra wait_rand_delay_outer

decfsz cmd_ctr ; send command again if it was not sent 3 times already

bra send_cmd_loop

bra wait_cmd_loop ; go to sleep after sending 3 commands

;******************************************************************************

;End of program

goto $

END

# Quellen

Auf alle Quellen wurde am 01.07.24 zuletzt zugegriffen.

- [1] https://ww1.microchip.com/downloads/en/devicedoc/39626e.pdf
- [2] https://www.datasheets.com/part-details/ncv1117st50-onsemi-34665214
- [3] Microcontroller Theory and Applications by Rafiquzzaman
- [4] https://www.ged-pcb-mcm.de/2018/05/13/gutes-pcb-layout-am-beispiel-des-quarzoszillators/
- [5] https://docs.rs-online.com/175a/0900766b80de9fc1.pdf
- [6] https://www.allaboutcircuits.com/technical-articles/pcb-layout-tips-and-tricks-use-a-ground-plane-whenever-possible/
- [7] https://www.opendcc.de/info/rc5/rc5.html
- [8] https://developerhelp.microchip.com/xwiki/bin/view/products/mcu-mpu/8bit-pic/peripherals/ccp/pwm/10-bit/
- [9] https://www.electronicwings.com/pic/pic18f4550-timer

# Abbildungsquellen

- Abb. 12 und 13: https://www.opendcc.de/info/rc5/rc5.html, letzter Zugriff am 01.07.24

Praktikum Digitaltechnik, Benedikt Schnörr, Sebastian Pasinski01.07.24

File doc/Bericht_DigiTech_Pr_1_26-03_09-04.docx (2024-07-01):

# Praktikum Digitaltechnik

IR - Remote

Benedikt Schnörr, Sebastian Pasinski

# Gliederung

Aufgabenstellung 3

Systemarchitektur 3

Schaltplanskizze 3

Aktivitätsdiagramm 4

Schaltplan 5

Mikrocontroller 6

Taktgebung 6

Programmier-/Debugging-Schnittstelle 6

Spannungsregulierung 7

Schalter 7

IR-LED 8

Platinendesign 8

Quellen 10

# Aufgabenstellung

Die Aufgabenstellung für das Digitaltechnik-Praktikum ist es, eine Infrarot-Fernbedienung zu bauen. Diese soll einen Receiver ansteuern, welcher das RC5-Protokoll unterstützt. Es sollen die wichtigsten Funktionen eines CD-Players mit der Fernbedienung angesprochen werden können. Dazu gehören:

- Play
- Stop
- Pause
- Previous, vorheriger Titel
- Next, nächster Titel

Die Anforderungen für dieses System sind, dass es auf einer eigenen Platine aufgebaut und batteriebetrieben arbeiten soll.

Bei unserem Vorgehen werden wir zunächst einen Schaltplan entwerfen, der die elektrischen Bauteile und den Mikrocontroller enthält, sodass daraufhin eine Platine designt und die Bauteile bestellt werden können. Im zweiten Schritt werden wir dann den Code entwickeln, mit dem die gedrückte Taste auf der Fernbedienung ausgelesen wird und das passende Signal als RC5-Code gesendet wird.

# Systemarchitektur

## Schaltplanskizze

Wir haben zunächst ein Blockschaltbild erstellt, das die wichtigsten Komponenten unserer Schaltung darstellt. Dazu gehören die Schalter mit ihren einzelnen Funktionen, der Mikrocontroller, der die IR-LED ansteuert, und der Receiver, der die gesendeten Befehle empfängt.

Mikrocontroller

Mikrocontroller

Schalter[0-4]

Infrarot-Led

RC-5

Receiver

Abb. 1: Blockschaltbild der Fernbedienung

## Aktivitätsdiagramm

Der Ablauf der Benutzung der fertigen Fernbedienung wird in einer Tabelle dargestellt.

Tabelle 1: Ablauf bei Interaktion des Benutzers

Aktoren | Aktivität
Benutzer | drückt einen Schalter in der Schaltung
Schalter [0-4] | sendet beim Drücken elektrische Signale an einen Mikrocontroller-Eingang
Microcontroller | empfängt Spannung am Eingang und sendet elektrische Signale an den Ausgang mit IR-LED
IR Led | Wandelt elektrische Spannung in Lichtsignale um
Receiver | empfängt die Lichtsignale und führt z.B “Play”-Befehl aus
Benutzer | Kann entsprechenden Befehl am Receiver erkennen

Das Aktivitätsdiagramm stellt den Ablauf noch einmal bildlich dar. Interessant dabei ist, dass sich der Mikrocontroller immer im Sleep-Modus befindet und von einem Schalter aufgeweckt wird, um Energie zu sparen, wenn keine Taste gedrückt wird.

Schalter [0-3] gedrückt?

Ja

Nein

Mikrocontroller schläft

Welcher Schalter ?

S0 S1 S2 S3

Befehl 1

Steuere LED mit Befehl an

Beginn:

Befehl 2

Befehl 3

Befehl 0

Abb. 2: Aktivitätsdiagramm für den Ablauf der Benutzereingabe

# Schaltplan

Um die Funktionsweise des Systems auch in Hardware umzusetzen, wird eine Schaltung entwickelt und daraus eine Platine gestaltet.

Abb. 3: Schaltplan in Eagle

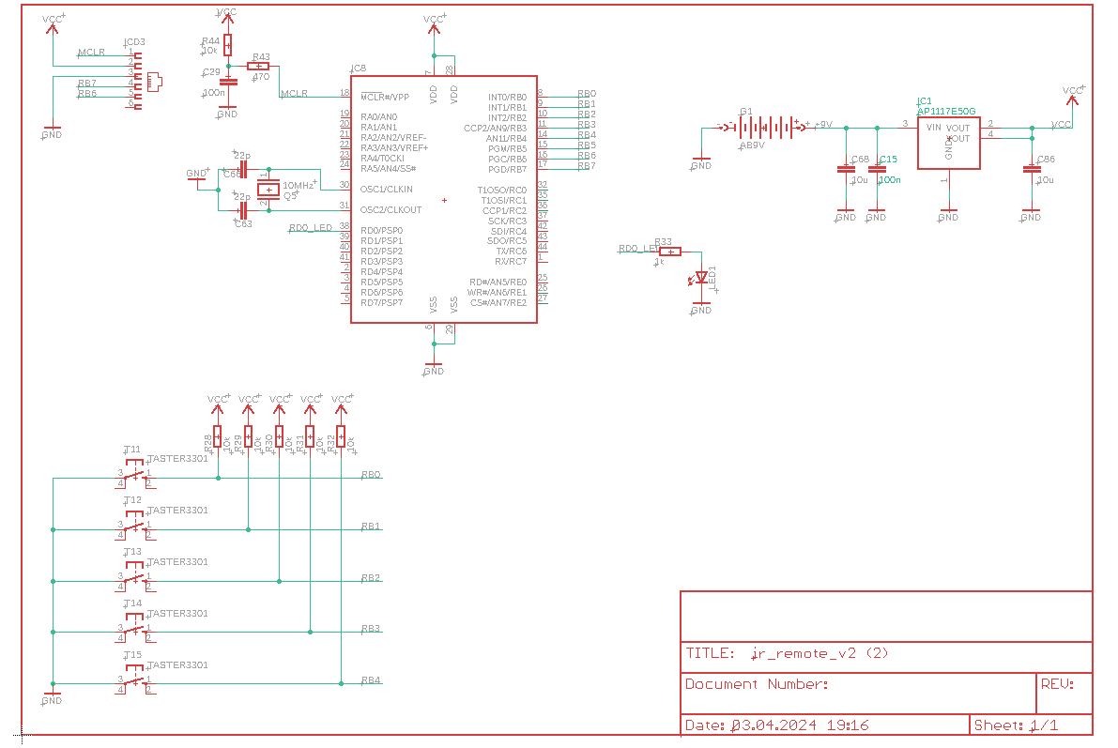
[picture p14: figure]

## Mikrocontroller

Der in der Schaltung verwendete Mikrocontroller ist ein PIC18F4525, an ihn sind neben Schaltern und Infrarot-LED noch weitere Schaltkreise angeschlossen. In Eagle wird zur Darstellung ein PIC18F4520 verwendet, der aber die gleiche Pin-Belegung und die gleichen Abmessungen wie der PIC18F4525 besitzt und daher als Alternative im Schaltplan benutzt werden kann.

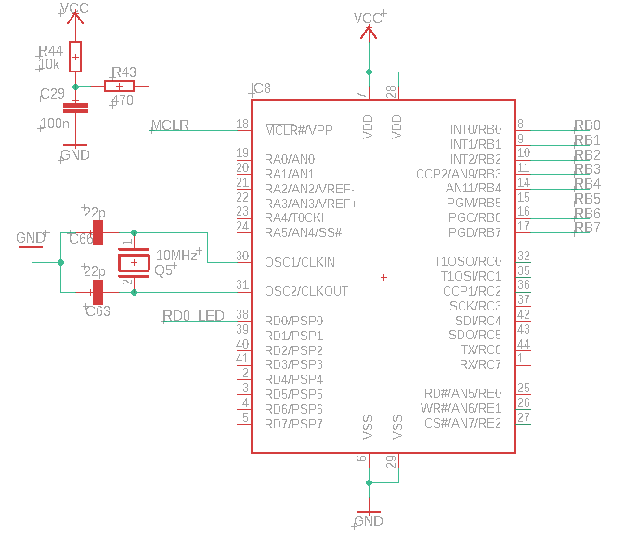
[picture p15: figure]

Abb. 4: Beschalteter PIC18F2545

### Taktgebung

Der Quarz dient dazu, dem Mikrocontroller eine Taktfrequenz bereitzustellen, nach der sich dieser richten kann. Das Datenblatt des PIC18F4525 empfiehlt für die Oszillator-Konfiguration “High Speed Crystal/Resonators” mit einer Frequenz von 10 MHz Kondensatoren eine Kapazität von 15 pF. In der vorgegebenen Schaltung wurde eine höhere Kapazität verwendet, dies verbessert die Stabilität des Schwingkreises, kann aber zur Vergrößerung der Startzeit führen [1].

### Programmier-/Debugging-Schnittstelle

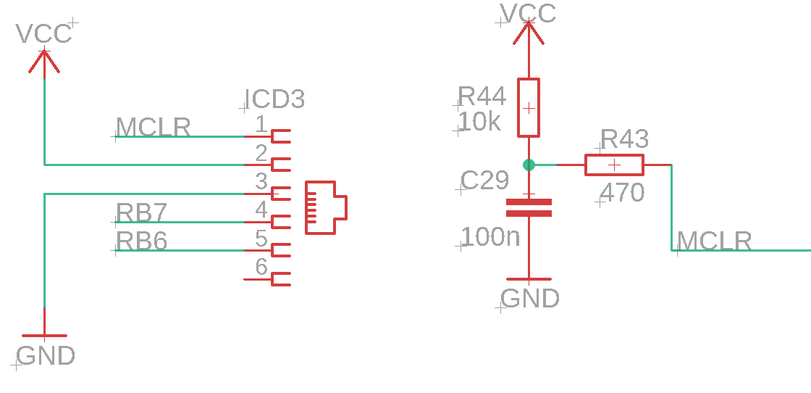
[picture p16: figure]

Abb. 6: Schnittstellen des Mikrocontrollers zum Debuggen/Programmieren

Mit diesem Schaltungsblock wird eine Schnittstelle zwischen der Software zum Programmieren und den Pins RB6 und RB7 des Mikrocontrollers hergestellt. Das Debugging des PIC kann dadurch gesteuert werden, während dieser in der Schaltung eingebaut ist [1].

### Spannungsregulierung

Der AP1117E50G wird eingesetzt, um die Spannung von einer 9 V-Versorgung auf 5 V als Betriebsspannung des PIC zu senken. Die 10 μF Kondensatoren gleichen dabei mögliche Schwingungen in der erzeugten 5 V-Spannung aus. Der 100 nF Kondensator soll mit seiner größeren Kapazität die Eingangsspannung halten, wenn die Versorgungsspannung zu stark abfällt. Der Spannungsregulierer kann nämlich nur bei einer Eingangsspannung von 1,3V über der Ausgangsspannung korrekt arbeiten [2].

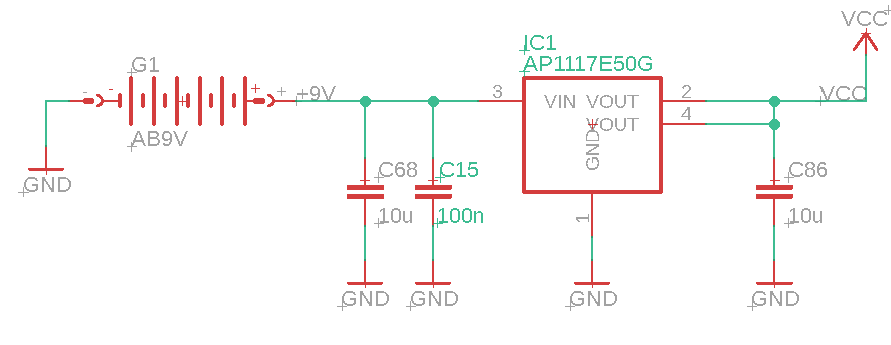
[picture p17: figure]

Abb. 7: Spannungsversorgung

## Schalter

Die Schalter, welche an verschiedenen Pins an Port B des Mikrocontrollers angeschlossen sind, sorgen dafür, dass im ausgeschalteten Zustand die Versorgungsspannung von 5 V am jeweiligen Pin anliegt. Im angeschalteten Zustand werden die Pins auf Masse gezogen.

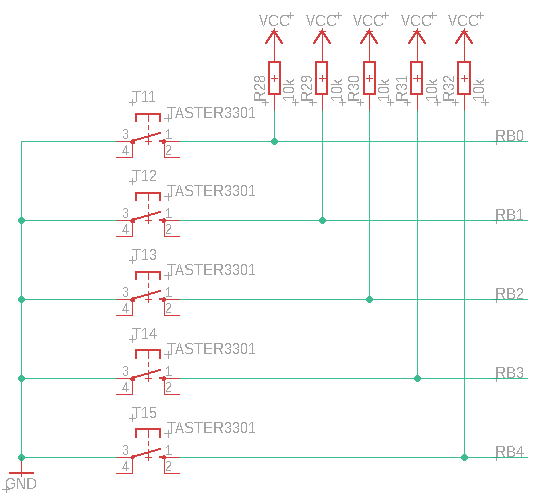
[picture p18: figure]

Abb. 8: Verschaltung der Taster

## IR-LED

Für das Aussenden der Lichtsignale wird eine 5mm Vischay IR-LED verwendet. Der Vorwiderstand berechnet sich mit dem Spannungsabfall von 1 V an der LED und dem Betriebsstrom von 50 mA zu 80 Ω. Als erhältlicher Widerstand können dann z.B. 82 Ω oder 100 Ω gewählt werden [3].

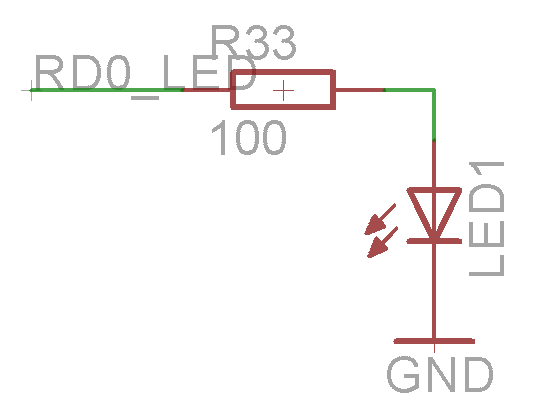
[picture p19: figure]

Abb. 9: Verschaltung der IR-LED

# Platinendesign

Das Platinen-Design wurde genau wie die Erstellung des Schaltplans in Eagle gemacht. Die Vorgaben des Labors bezüglich der Designregeln waren an die Standardeinstellungen des Editors zu befolgen.

Anforderungen an den Platinenaufbau sollten allerdings sein, dass die Schalter möglichst aufgereiht beieinander sein sollten und der Quarz-Schwingkreis möglichst nah am Mikrocontroller sein sollte. Zudem sollte die IR-Led möglichst weit am Rande einer Plattenkante befinden.

Die erste Platzierung der Bauelemente auf einer Leiterplatte ist in Abb. 10 zu sehen:

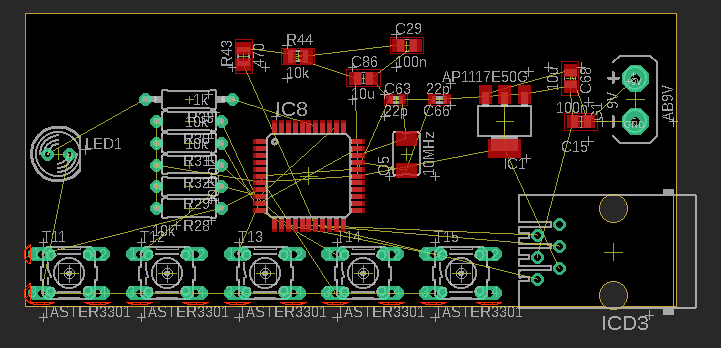
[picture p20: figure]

Abb. 10: Erste Platzierung der Bauteile in Eagle

Ein endgültiges Layout sollte allerdings erst nach Rücksprache mit dem Labor und dem Dozenten angefertigt werden.

# Quellen

[1] Datenblatt PIC: https://ww1.microchip.com/downloads/en/devicedoc/39626e.pdf

[2] Datenblatt AP1117: https://www.diodes.com/assets/Datasheets/AP1117.pdf

[3] Datenblatt LED: https://docs.rs-online.com/175a/0900766b80de9fc1.pdf

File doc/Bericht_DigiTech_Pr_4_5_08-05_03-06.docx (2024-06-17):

# Praktikum Digitaltechnik

IR - Remote

Benedikt Schnörr, Sebastian Pasinski

# Gliederung

Gliederung 2

Bit-Übertragung in der Theorie 3

Bit-Übertragung im Code 4

Interrupt Service Routine 7

Finales PCB-Layout 9

Bildquellen 10

Quellen 10

# Bit-Übertragung in der Theorie

Die im letzten Bericht erwähnten Pulse mit einer Pulsdauer von 888,89 μs, die eine Rechteckspannung mit einer Frequenz von 36 kHz beinhalten, werden nun für die Bit-Übertragung genutzt. Ein Bit besteht dabei immer aus einer Low-Phase und einer Puls-Phase. Wie in Abb. 1 zu sehen, verändert die Reihenfolge dieser zwei Phasen den Zustand des Bits zwischen High und Low. [1]


Abb. 1: Reihenfolge der Puls- und Ruhephasen und deren Bedeutung als Bit

Ein Befehl der Fernbedienung besteht aus insgesamt 14 Bits, die nacheinander gesendet werden. Die Bits sind in Abb. 2 dargestellt und haben die folgende Bedeutung: [2]

- 2 Start-Bits
- 1 Toggle-Bit, wodurch zwischen langem Tastendruck und erneutem Drücken unterschieden werden kann
- 5 Adress-Bits, um ein konkretes Gerät anzusprechen wie bspw. CD-Player, TV, Audio-Vorverstärker
- 6 Befehls-Bits


Abb. 2: Zeitliche Abfolge der Bits im RC5-Befehl

Der Code, um die Bits mit Ruhe- und Puls-Phase zu senden, ist im Folgenden dargestellt. Die Initialisierung von Ports und Timern ist zur Vereinfachung nicht berücksichtigt.

# Bit-Übertragung im Code

Der send_bit-Loop iteriert durch alle zu sendenden Bits und ruft die passende Sender-Funktion auf, abhängig davon, ob das betrachtete Bild eine logische 0 oder 1 ist.

###### send_bit:

###### rlcf bit_buffer_l ;get next bit from bit buffers

###### rlcf bit_buffer_h ;which contain command bits

###### btfss STATUS,C

###### call send_0

###### call send_1

###### decfsz bit_ctr

###### bra send_bit

Die entsprechenden send-Funktionen rufen dann die Ruhe- und Puls-Phase in der richtigen Reihenfolge auf.

###### send_0:

###### call tmr_delay

###### call pwm_delay

###### return

###### send_1:

###### call pwm_delay

###### call tmr_delay

###### return

Beim RC5-Code kann die PWM-Funktion des PIC18F4525 genutzt werden, um auf einfachem Weg ein Rechtecksignal zu erzeugen. Dazu wird das CCP-Modul genutzt, welches das Signal an Pin RC1 ausgibt. In der Konfiguration wird dazu die Frequenz des Signals im PR2-Register, sowie die Länge des Pulses (Duty Cycle) in den CCPR2L- und CCP2CON-Registern festgelegt. Die entsprechenden Berechnungen wurden bereits im letzten Bericht erläutert. Der folgende Code-Abschnitt zeigt die eingestellten Register.

###### ; configure pwm module

###### movlw 0x44 ; configure period time with 0x44

###### movwf PR2

###### movlw b'00000010' ; configure duty cycle with 0x11

###### movwf CCPR2L

###### movlw b'00111100' ; configure pwm mode and

###### movwf CCP2CON ; 2 lsbs of duty cycle

###### movlw b'00000000' ; configure postscale and prescale

###### movwf T2CON ; value and turn timer 2 off

###### movlw 0x00 ; reset timer 2 counter

###### movwf TMR2

Während die Rechteckspannung vom CCP2CON-Modul und Timer 2 erzeugt wird, muss auch die Sendedauer des Pulssignals reguliert werden. Wie bereits erwähnt, werden in der Sendephase jedes Bits 32 Pulse gesendet, dies entspricht einer Dauer von 888,89μs. Diese Sendedauer wird von Timer 0 beendet, der von einem entsprechend eingestellten Wert hochzählt. Beim Überlauf von 0xFFFF zu 0x0000 wird ein Interrupt erzeugt, über dessen Interrupt Service Routine dann die Sendephase beendet werden kann. Der Startwert des Timers ergibt sich durch die folgenden Berechnungen. [3]

f_(OSC) =10MHz → f_(Timer) =(f_(OSC))/4=2,5MHz→T_(Timer) =1/(f_(Timer))=0,4μs

n_(Timer) =(T_(Sendedauer))/(T_(Timer))=(888,89μs)/(0x4μs)≈2222

Da der Timer diese Differenz zählen muss, bis er überläuft wird nTimer von der maximale Zahl beim Überlauf der 16 Bit des Timer 0 abgezogen.

n_(Timer) =65536-2222=63314=0xF752

Die pwm_delay-Routine konfiguriert Timer 2 für die Rechteckspannung und startet Timer 0 und Timer 2.

###### pwm_delay:

###### movlw 0xF7 ;load timer 0 for half bit

###### movwf TMR0H

###### movlw 0x52

###### movwf TMR0L

###### movlw 0x00 ;load timer 2 for pwm

###### movwf TMR2

###### bsf LATC,1 ;set first pulse manually

###### bsf T0CON,TMR0ON ;start timers

###### bsf T2CON,TMR2ON

###### call delay_loop

###### return

In der folgenden Routine wird die Ruhe-Phase mit Timer 0 gestartet.

###### tmr_delay:

###### movlw 0xF7 ;load timer 0 for half bit

###### movwf TMR0H

###### movlw 0x52

###### movwf TMR0L

###### bsf T0CON,TMR0ON ;start timer 0 for pausing

###### call delay_loop

###### return

Die folgende Delay-Routine wird ausgeführt, bis beim Überlauf von Timer 0 das nullte Bit von tmr_done gesetzt wird. In diesem Moment wird die Routine und somit auch die Ruhe- oder Puls-Phase beendet.

###### delay_loop: ;wait for interrupt to end half bit

###### btfss tmr_done,0

###### bra delay_loop

###### bcf tmr_done,0

###### return

Die High-Interrupt-Routine wird beim Überlauf von Timer 0 ausgelöst und setzt wie bereits erwähnt das tmr_done-Flag. Die Interrupt-Priorität ist in der Testphase auf einen High-Interrupt eingestellt, kann aber später auch auf einen Low-Interrupt umgestellt werden, damit der High-Interrupt für den Tastendruck verwendet werden kann.

###### HighInt:

###### bcf T0CON,TMR0ON ;stop timers

###### bcf T2CON,TMR2ON

###### bcf INTCON,TMR0IF ;reset interrupt flag

###### bsf tmr_done,0

###### retfie FAST

Dieser Code kann also alle 14 Bits für einen Befehl senden. Der Befehl wird von einem anderen Teil des Programms festgelegt, in dem der gedrückte Taster ausgelesen wird. Der bereits beschriebene Programmteil wird dann nach dem Tastendruck ausgeführt.

# Interrupt Service Routine

Um die Funktionsweise der Schalter im Sleep-Mode zu gewährleisten und Software-Polling zu vermeiden,werden die Interrupts des PIC18F4525 verwendet. Die Pins 0-2 und 4-7 am Port B sind dazu in der Lage. Zunächst soll der Pin an RB0 ein Interrupt Request auslösen, wenn ein Schalter an diesem Eingang gedrückt wurde. Die ISR wurde unabhängig von der Initialisierung der PWM auf dem “picdem 2 plus demo board 2002” getestet.

Das Programm beginnt mit der High Priority Interrupt Routine, da INT0 immer von hoher Priorität ist. In der Routine soll nur das Flag zurückgesetzt werden und das Programm an die Stelle in der Hauptschleife springen, an der unterbrochen wurde. Wenn eine High Priority Interrupt ausgelöst wird, geht das Programm an die Stelle 0x0008 im Speicher und wird zur Routine geschickt.

###### ORG 0x0008

###### bra HighInt ; go to routine

###### ORG 0x0018

###### bra LowInt

###### HighInt:

###### bcf INTCON, INT0IF ;clear flag to avoid double interrupt

###### nop

###### nop

###### nop

###### nop

###### nop

###### retfie ; return to address saved on stackpointer

Im Hauptprogramm soll zunächst der Pin RB0 als digitaler Eingang festgelegt und dessen Interrupt-Einstellungen gesetzt werden. Diese sind als erstes das Flag zu clearen, dann Pullup-Widerstände zu setzen, den Interrupt zu befähigen und ihn bei einer fallenden Flanke zu setzen.

###### Main:

###### clrf PORTB

###### bcf ADCON0,ADON ; AD Converter disabled

###### movlw 0xFF

###### movwf TRISB

###### movlw 0xFF

###### movwf ADCON1 ; set PortB0 as digital Input

###### bcf INTCON, INT0IF ; clear Interrupt flag

###### bcf INTCON2, RBPU ; set Pull Ups on Portb

###### bsf INTCON, INT0IE ; Enable interrupt

###### bcf INTCON2, INTEDG0; Interrupt on falling edge

###### bsf INTCON, GIE ; Enable interrupts

In der Hauptschleife soll der Mikrocontroller dann auf ein Auslösen des Interrupts warten, bzw. setzen des Flags.

###### MLOOP

###### nop

###### nop

###### nop

###### nop

###### GOTO MLOOP

###### End

Im Programm wurde dann ein Breakpoint in der High Interrupt Service Routine gesetzt, um ein Auslösen zu identifizieren.

# Finales PCB-Layout

Es wurde ein endgültiges Layout in Rücksprache mit dem Labor angelegt. Im Vergleich zur letzten Version wurde kleine Fehler an den Verbindungen ausgebessert.

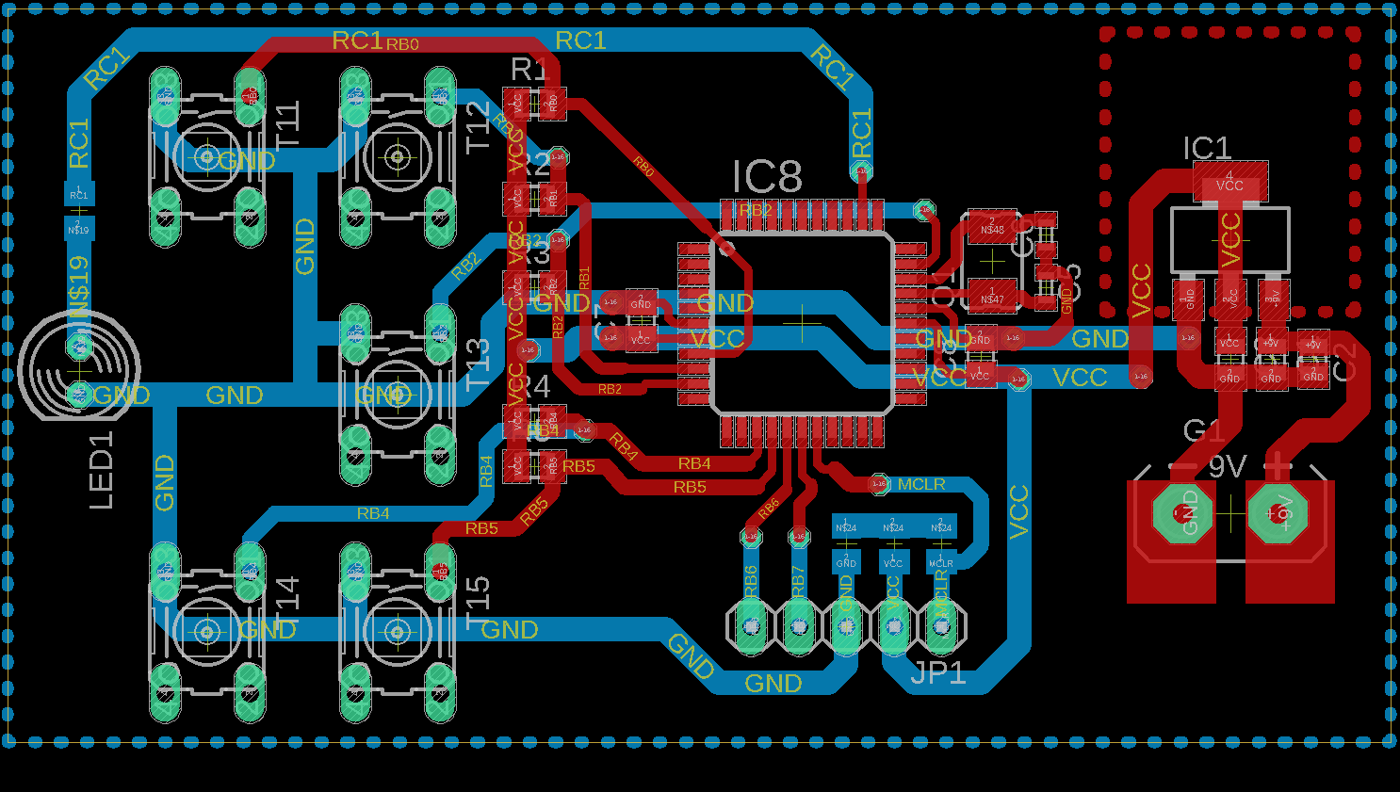
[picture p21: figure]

Abb. 3: PCB-Layout - Farbig

# Bildquellen

Abb. 1 und 2: https://www.opendcc.de/info/rc5/rc5.html, zuletzt aufgerufen am 02.06.24

# Quellen

[1] https://www.opendcc.de/info/rc5/rc5.html, zuletzt aufgerufen am 02.06.24

[2] http://www.stefan-buchgeher.info/elektronik/rc5/rc5.html, zuletzt aufgerufen am 02.06.24

[3] https://www.electronicwings.com/pic/pic18f4550-timer, aufgerufen am 23.05.24

# Anhang 1

PCB - Layout in Eagle Dark Mode.

Bericht Praktikum Digitaltechnik 03.06.2024

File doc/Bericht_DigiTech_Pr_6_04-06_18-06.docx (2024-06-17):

# Praktikum Digitaltechnik

IR - Remote

Benedikt Schnörr, Sebastian Pasinski

# Gliederung

Gliederung 2

Interrupts für Schalter 3

Schnittstelle zwischen Interrupts und RC5-Code 5

Sleep-Befehl 5

Hardware 5

Quellen 6

# Interrupts für Schalter

Es befinden sich an den Pins RB0, RB1, RB2, RB4 und RB5 Schalter. Um das Drücken der Schalter an der Fernbedienung zu erkennen, musste das Programm mit den Interrupts um weitere Unterbrechungen erweitert werden. Es galt, zusätzlich zum Interrupt 0 die Interrupts 1,2 und die Pins RB4 und RB5 als Interrupts festzulegen.

clrf PORTB

bcf ADCON0,ADON ; AD Converter disabled

movlw 0xFF

movwf TRISB

movlw 0xFF

movwf ADCON1

; Clear Interrupt flags

bcf INTCON, INT0IF

bcf INTCON3, INT1IF

bcf INTCON3, INT2IF

bcf INTCON, RBIF

; enable pullups

bcf INTCON2, RBPU

; Enable Interrupts

bsf INTCON, INT0IE

bsf INTCON3, INT1IE

bsf INTCON3, INT2IE

bsf INTCON, RBIE

; triggers interrupts when falling edge occurs on RB0-2

bcf INTCON2, INTEDG0

bcf INTCON2, INTEDG1

bcf INTCON2, INTEDG2

; Interrupt priority of int1 / 2 needs to be configured

bsf INTCON, GIEH ; Enables high and low Priorities

bsf INTCON, GIEL

bsf RCON, IPEN ; Enables Priorities

; Setting Priority high for INT1, INT2 and RB On Change

bsf INTCON3, INT2IP

bsf INTCON3, INT1IP

bsf INTCON2, RBIP

Um in der Anwendung des Programms nachvollziehen zu können, welcher Schalter gedrückt wurde, wurde ein Algorithmus innerhalb der High Interrupt Routine implementiert, welcher die jeweiligen Interrupt-Flags abfragt oder entsprechend die Zustände an den Pins. Wenn der entsprechende Schalter erkannt wurde, wird eine Sendefunktion mit einem bestimmten RC-5 Befehl ausgeführt.

HighInt:

btfsc INTCON, RBIF ; was pin 4/5 pressed?

bra RBonChange

;Routine to find out on what Pin the high signal was

In der Routine wurde dabei zuerst ermittelt, ob sich eine Änderung an den Pins RB4 und RB5 ereignet hat, um diese anhand der Pin Zustände in der Routine RBonChange abzufragen.

btfsc INTCON, INT0IF ; was Pin 0 pressed?

bra SendRB0 ; Yes Pin 0 was pressed, send command

btfsc INTCON3, INT1IF ; was Pin 1 pressed?

bra SendRB1

btfsc INTCON3, INT2IF ; was Pin 2 pressed

bra SendRB2

retfie

RBonChange:

btfsc PORTB, 4 ;High Signal on RB4?

bra SendRB4; in routine sende befehl und return

btfsc PORTB, 5 ;Test Port RB5

bra SendRB5;

bcf INTCON, RBIF ; else none of the relevant pins

retfie;

In den jeweils aufgerufenen Senderoutinen wird das Interruptflag zurückgesetzt, um mehrfache Unterbrechungen zu vermeiden und wieder in das Hauptprogramm zu springen. Im Folgenden ist eine beispielhafte Routine dargestellt.

SendRB0:

; Sending Routine for Command 1

nop

bcf INTCON, INT0IF ; clearing Flag to avoid Double interrupt

retfie

Die Schnittstelle wurde am Modell getestet, um das Programmverhalten beim Drücken der Taster zu beobachten.

# Schnittstelle zwischen Interrupts und RC5-Code

Die Schnittstelle zwischen den beiden weitestgehend unabhängig entwickelten Programmteilen zu den Interrupts und der RC5-Übertragung besteht aus zwei Bit-Buffern. Diese werden in den Sende-Routinen bei einem High Interrupt auf den passenden Befehl gesetzt. [2] Die 14 Bits im Bit-Buffer, die den Befehl enthalten, werden daraufhin als RC5-Code mit dem bereits im letzten Bericht erläuterten Programm gesendet. Beispielhaft ist hier die Sende-Funktion für die Stop-Taste dargestellt.

send_rb_0: ; send stop command

movlw b'00110101'

movwf bit_buffer_h

btfsc bit_buffer_toggle ; set toggle bit in bit buffer

bsf bit_buffer_h,3

movlw b'00110110'

movwf bit_buffer_l

bcf INTCON,INT0IF

return

In diesem Code-Abschnitt wird auch das Toggle-Bit behandelt. Dabei handelt es sich um ein Bit im Code, das bei jedem neuen Tastendruck getoggelt wird. Dadurch kann der Empfänger einen langen Tastendruck, bei dem der Befehl durchgängig gesendet wird und das Toggle-Bit den Wert beibehält, von einem erneuten Tastendruck unterscheiden.

# Sleep-Befehl

Damit im Batteriebetrieb Strom gespart wird, soll der PIC bei Inaktivität in den Sleep-Modus gesetzt werden. Um einen Sleep- Befehl ausführen zu können, wird im OSCCON-Register das IDLE-Bit zurückgesetzt. Dann kann der Mikrocontroller in den Sleep-Modus versetzt werden. [1]

bcf OSCCON, IDLEN

sleep

# Hardware

Anhand der finalen Layouts aus dem vorherigen Bericht wurde seitens des Labors eine Platine erstellt und mit Bauteilen bestückt. Diese ist in Abb. 1 zu sehen.

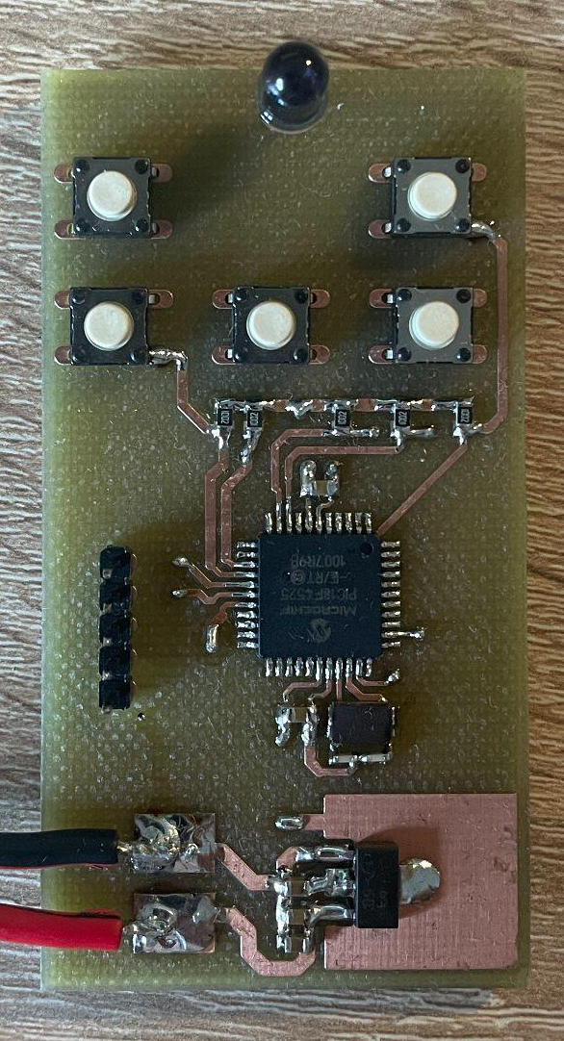
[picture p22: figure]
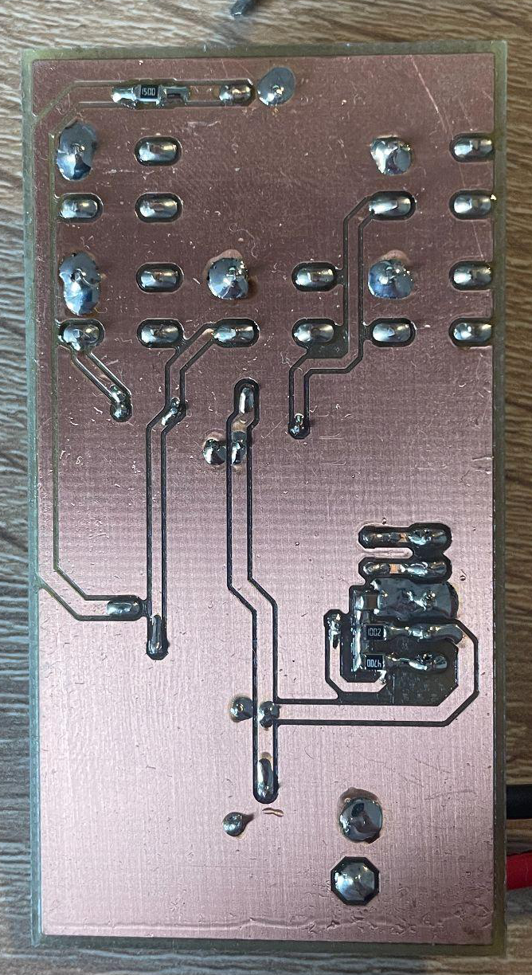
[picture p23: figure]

Abb. 1: Vom Labor bestückte Platine

# Quellen

[1] https://ww1.microchip.com/downloads/en/devicedoc/39626e.pdf S.37

[2] https://www.opendcc.de/info/rc5/rc5.html

Bericht Praktikum Digitaltechnik17.06.2024

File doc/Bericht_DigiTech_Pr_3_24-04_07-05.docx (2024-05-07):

# Praktikum Digitaltechnik

IR - Remote

Benedikt Schnörr, Sebastian Pasinski

# Gliederung

Schaltplan 3

Layout 4

Gehäuse 4

Programm 5

Konfiguration Interrupt-Register 5

Konfiguration PWM-Modul 6

# Schaltplan

Im Schaltplan des Projekts wurden einige Änderungen vorgenommen. Es wurden zunächst die Anschlüsse des Mikrocontrollers geändert. Die Schalter liegen nun an den folgenden Pins des Pic18F4525 und nutzen deren Interrupt-Funktionen:

- S1 - RB0 → Interrupt bei Flanke
- S2 - RB1 → Interrupt bei Flanke
- S3 - RB2 → Interrupt bei Flanke
- S4 - RB4 → Interrupt bei Zustandsänderung
- S5 - RB5 → Interrupt bei Zustandsänderung

Auch der Pin, an den zuvor die IR-LED angeschlossen war, wurde auf den PWM-fähigen Anschluss RC2 geändert, der bei der Übertragung mit dem RC5-Protocoll eine Rechteckspannung bereitstellen soll.

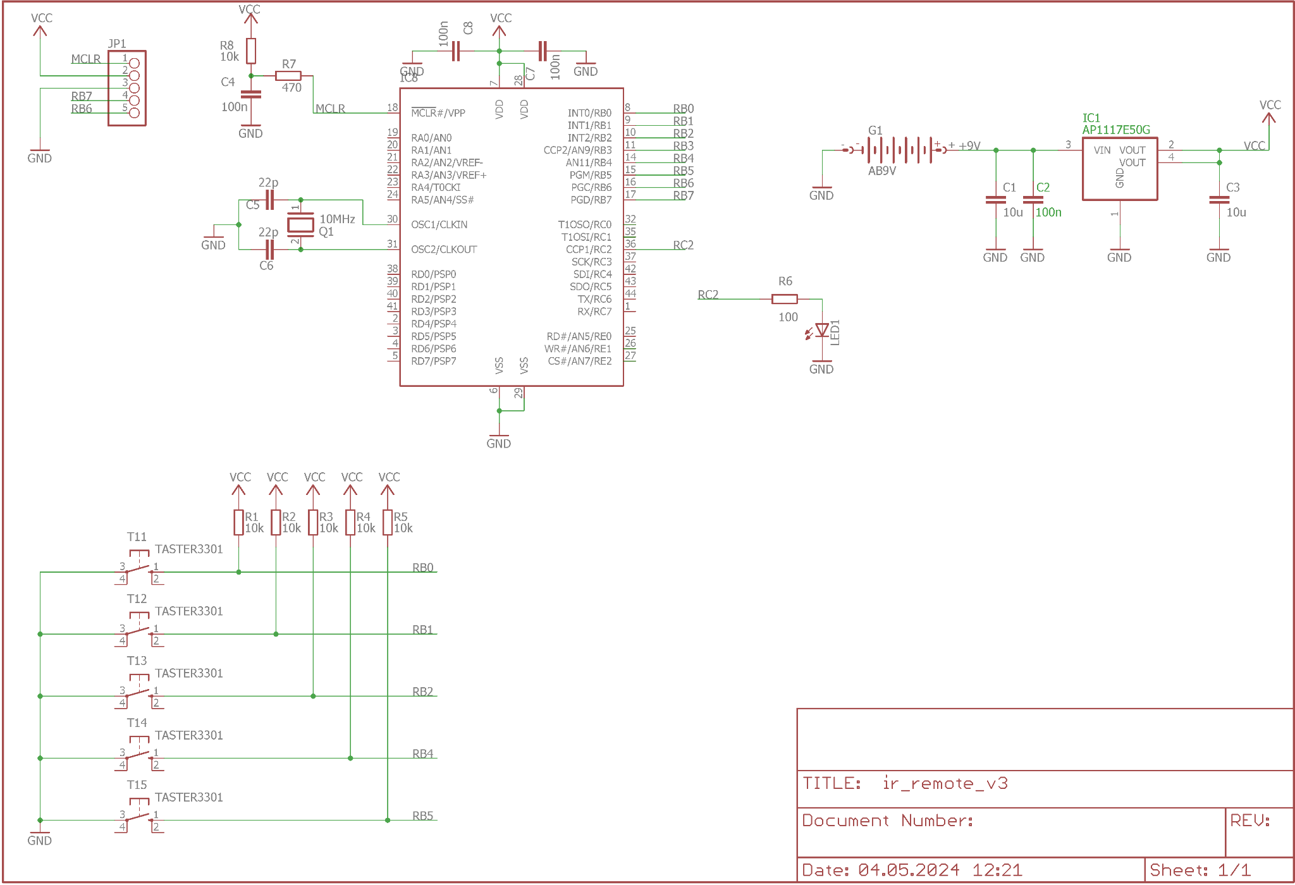
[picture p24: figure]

Abb. 1: Schaltplan nach Veränderung der Pin-Belegung von Tastern und LED

# Layout

Das Layout wurde nach Rücksprache mit dem Labor weiter bearbeitet. Dazu gehören die Anordnung der Kapazitäten um den Spannungsregulierer, die Anordnung der Bauteile um den Anschluss des Debuggers JP1, sowie die Anordnung der Kapazitäten an den Pins des Mikrocontrollers für die Spannungsversorgung. Die Grundlage waren dabei möglichst kurze Leitungswege mit möglichst großer Leitungsbreite. Zudem wurden an der Batterie größere Lötflächen hinzugefügt und auf der Unterseite der Leiterplatte eine Ground-Fläche erstellt.


Abb. 2: Layout der IR-Fernbedienung mit veränderter Anordnung der Bauteile um IC1, JP1 und PIC18

# Gehäuse

Im Zuge der Studienarbeit des Mechatronik-Studenten Marcel Halef soll in Zukunft ein Gehäuse für die Fernbedienung entworfen und gefertigt werden. Nach einem ersten Austausch gilt es nun, die genauen Maße der Platine zu bestimmen, die Anordnung der Schalter und deren genaue Funktion zu definieren, um eine klare Kommunikation zwischen den Parteien zu etablieren.

# Programm

Das Programm, mit dem der Mikrocontroller betrieben wird, soll in MPLab mit Assembler umgesetzt werden und folgende Aufgaben erfüllen:

1. Register für Interrupts und PWM konfigurieren
2. Zuordnung von Interrupt-Pins und dem zu sendenden Befehl schaffen
3. Interrupt-Routinen definieren, die den passenden Befehl auswählen
4. RC5-Übertragung des gewählten Befehls mit PWM-Pin umsetzen

## Konfiguration Interrupt-Register

Die Konfiguration der Interrupt-Register sieht wie folgt aus:

LIST P=18F4525 ;directive to define processor

#include "P18F4525.INC" ;processor specific variable definitions

;*****************************************************************************

CONFIG OSC = XT

CONFIG WDT = OFF

CONFIG LVP = OFF

;******************************************************************************

Main:

SETF TRISB

CLRF TRISC

BSF INTCON, INT0IE

BSF INTCON, RBIE

BCF INTCON, INT0IF

BCF INTCON, RBIF

BSF INTCON3, INT2IE

BSF INTCON3, INT1IE

BCF INTCON3, INT2IF

BCF INTCON3, INT1IF

BSF INTCON2, ITEDG0 ; sensitive on rising edge

BSF INTCON2, INTEDG1

BSF INTCON2, INTEDG2

BSF INTCON, GIE

;PWM Pin einstellen

; ISR Folgt…

ORG 0x00008

endlos goto endlos

;******************************************************************************

;End of program

## Konfiguration PWM-Modul

Für die PWM-Übertragung an Pin RC2 wird das “Enhanced Capture/Compare/PWM Module (ECCP)” im “Standard PWM Mode” genutzt. Alle nachfolgenden Ausführungen beruhen auf Informationen im Kapitel 15.4 des Handbuchs für den PIC18F4525.

Bei der Konfiguration muss zunächst die Periodendauer bzw. Frequenz der benötigten Trägerschwingung definiert werden. Diese kann über die folgende Formel berechnet werden:

T_(Period) =[n_(PR2) +1]⋅4⋅T_(OSC) ⋅n_(TMR)

n_(PR2) =(f_(OSC))/(4⋅f_(Period) ⋅n_(TMR))-1≈44h

Die Frequenz fPeriod ist dabei die Träger-Frequenz von 36 kHz beim RC5-Protokoll. Die Frequenz des Oszillators fOSC ist die angenommene Taktfrequenz des Mikrocontrollers von 10 MHz. Der Prescale Value nTMR = 1 wird aus den Beispielen im Handbuch gewählt. Der berechnete Wert nPR2 wird bei der Konfiguration in das PR2-Register eingetragen, um die gewünschte Frequenz der Rechteckspannung zu erreichen.

Auch die Dauer der High-Phase der Rechteckspannung muss in der Konfiguration beachtet werden. Bei einem Duty Cycle von 25% ergibt sich für die passende Einstellung ein Wert von n_(CCP) =11h . Dieser Wert wird als 10-stellige binäre Zahl konfiguriert. Die ersten acht MSBs werden in das CCPR2L-Register und die zwei verbleibenden LSBs in das CCP2CON-Register an Stelle 5 und 4 eingetragen.

Bericht Praktikum Digitaltechnik 06.05.2024

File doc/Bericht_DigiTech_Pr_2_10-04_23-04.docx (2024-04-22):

# Praktikum Digitaltechnik

IR - Remote

Benedikt Schnörr, Sebastian Pasinski

# Gliederung

Gliederung 2

Anforderungen an das Layout 3

Layout 4

# Anforderungen an das Layout

Nach dem Entwurf des Schaltplans werden nun die Spezifikationen für das Layout der Platine formuliert.

Als erstes sollen die Knöpfe und IR-LED sinnvoll angeordnet werden, wie das bei dem Design von handelsüblichen Fernbedienungen der Fall ist. Die Taster werden nach ihren Funktionen auf der vorderen Hälfte der Platine angeordnet, um das Design der Fernbedienung benutzerfreundlich zu gestalten. Die LED wird mittig am vorderen Ende platziert, da dieses Ende normalerweise auf das gesteuerte Gerät gerichtet wird.

Außerdem soll der Anschluss für die 9V-Batterie am hinteren Ende liegen und wie der Anschluss für den In-Circuit-Debugger möglichst am Rand angeordnet sein.

Die Bauteile werden im Allgemeinen nach Funktion gruppiert, damit zusammengehörige Bauteile mit möglichst kurzen Leitungen verbunden werden können und das Layout übersichtlich bleibt. Diese Gruppen werden dann auf der Platine angeordnet. Die wichtigsten Gruppen sind dabei die Stromversorgung mit Batterie und Spannungsregulierer, der Mikrocontroller mit Quarz und die Bauteile für Benutzereingaben, also die Taster mit ihren Widerständen und auch die IR-LED.

Der Quarz-Oszillator und seine Baugruppe sowie die Kondensatoren C4 und C7 werden möglichst nah am Mikrocontroller platziert. Diese Anordnung soll die Reflexion zwischen PIC und Quarz verhindern und die Eingänge des Mikrocontrollers schützen.

Außerdem wird für den Spannungsregler IC3 am oberen Ende des VCC-Pins eine Kühlfläche vorgesehen, die die Wärme, die durch den Leistungsverbrauch entsteht, abführt.

Beim Verbinden der Bauteile wird die Leiterdicke möglichst groß gewählt, um den Widerstand der Leitungen zu verringern. Besonders die Leitungen für Masse und Versorgungsspannung sind dabei wichtig. Andererseits muss auch beachtet werden, dass die Leitungen an den Pads des Mikrocontrollers höchstens die Dicke der Anschlüsse haben, damit sie nicht andere Anschlüsse überlappen. Die Leitungen sollten außerdem immer im 45°-Winkel verlaufen. Dies verhindert elektromagnetische Störungen, Reflexionen und Probleme bei der Impedanzanpassung, die an 90°-Winkeln auftreten können.

# Layout

Unter Berücksichtigung dieser Grundlagen wurden dann erste Layout-Ansätze erstellt.


Abb. 1: Grundlegende Anordnung und Routing der Bauelemente

Abb. 1 zeigt die bereits erwähnte Anordnung nach den bereits definierten Anforderungen und ein grundlegendes Routing. Probleme sind dabei eine fehlende Kühlfläche am Spannungsregulierer IC1 sowie Leiterdicke und Abstand zwischen den Leiterbahnen.

Die Optimierungen rund um den Regulierer IC1 sind in Abb. 2 zu sehen.


Abb. 2: Power-Supply mit Kühlfläche am Spannungsregulierer

Außerdem wurden die Kondensatoren C4 und C7 auf die Unterseite der Platine in die Nähe der VCC- und GND-Pins des Mikrocontrollers verschoben.


Abb. 3: PIC mit Kondensatoren an VCC- und GND-Pins

Der nächste Schritt ist nun, weitere Verbesserungsvorschläge einzubauen und das Layout zu vervollständigen, um mit der Programmierung des Mikrocontrollers zu starten und dann die ersten Tests der Funktionalität durchzuführen.

Bericht Praktikum Digitaltechnik 22.04.2024

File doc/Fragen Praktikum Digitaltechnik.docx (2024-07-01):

# Fragen Praktikum Digitaltechnik

- Warum haben wir 10 MHz Quarz? Kein spezieller Grund
- Warum muss man die Pull-Ups an Port B aktivieren? → nochmal recherchieren, für active-low benötigt?
- Warum adcon? → Multiplexer mit anderen Funktionen, für digitale Signale adcon1 setzen

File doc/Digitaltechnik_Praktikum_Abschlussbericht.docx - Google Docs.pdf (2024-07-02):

# Digitaltechnik-Praktikum

## Sommer-Semester 2024

## Projekt: IR-Remote

Team: Sebastian Pasinski, Benedikt Schnörr

Prüfer: Prof. Dr. Francesco Volpe

Praktikum Digitaltechnik, Benedikt Schnörr, Sebastian Pasinski01.07.24

## Inhalt

Planung | 3
Aufgabenstellung | 3
Anforderungen | 3
Anwendungsfalldiagramm | 3
Skizze | 4
Schaltplan | 5
Mikrocontroller | 5
Taktgebung | 5
Programmier-/Debugging-Schnittstelle | 6
Spannungsregulierung | 6
Schalter | 7
IR-LED | 7
Layout | 8
Anordnung der Bauteile | 8
Routing | 8
Platine | 9
Software | 10
Einsatz von Interrupts | 10
Initialisierung der Interrupts im Programm | 10
Interrupt-Routine | 12
Bitübertragung mit dem RC5-Protokoll | 14
Konfiguration des PWM-Moduls | 15
Konfiguration von Timer 0 | 16
RC5-Übertragung im Code | 16
Main-Routine | 18
Vollständiger Code | 22
Quellen | 32
Abbildungsquellen | 32

# Planung

## Aufgabenstellung

Die Aufgabenstellung für das Digitaltechnik-Praktikum ist es, eine Infrarot-Fernbedienung zu bauen. Diese soll einen Receiver ansteuern, welcher das RC5-Protokoll unterstützt. Es sollen die wichtigsten Funktionen eines CD-Players mit der Fernbedienung angesprochen werden können. Dazu gehören:
- Play
- Stop
- Pause
- Forward (vorspulen)
- Backward (zurückspulen)

## Anforderungen

Die Anforderungen für dieses System sind, dass es auf einer eigenen Platine aufgebaut und batteriebetrieben arbeiten soll. Im Verlauf des Projekts wird zunächst ein Schaltplan entworfen, der die elektrischen Bauteile und den Mikrocontroller enthält, sodass daraufhin eine Platine designt und die Bauteile bestellt werden können. Im zweiten Schritt wird dann der Code entwickelt, mit dem die gedrückte Taste auf der Fernbedienung ausgelesen und das passende Signal als RC5-Code gesendet wird.

## Anwendungsfalldiagramm

Die grundlegende Funktionsweise des Systems wird in Abb.1 dargestellt.


Abb. 1: Anwendungsfalldiagramm der Funktionsweise im System

## Skizze

In Abb. 2 ist eine grobe Skizze der Fernbedienung zu sehen, um die Funktionen der einzelnen Taster zuzuordnen.


Abb. 2: Skizze der Fernbedienung

# Schaltplan

## Mikrocontroller

Der in der Schaltung verwendete Mikrocontroller ist ein PIC18F4525, an ihn sind neben Schaltern und Infrarot-LED noch weitere Schaltkreise angeschlossen. In Eagle wird zur Darstellung ein PIC18F4520 verwendet, der aber die gleiche Pin-Belegung und die gleichen Abmessungen wie der PIC18F4525 besitzt und daher als Alternative im Schaltplan benutzt werden kann.


Abb. 3: Grundschaltung des PIC18F4525 mit Quarz, Reset und I/O

### Taktgebung

Der Quarz dient als externer Oszillator für den Mikrocontroller, der die Taktfrequenz vorgibt. Das Datenblatt des PIC18F4525 empfiehlt für die Oszillator-Konfiguration “High Speed Crystal/Resonators” mit einer Frequenz von 10 MHz die Verwendung von Kondensatoren mit einer Kapazität von 15 pF. In der vorgegebenen Schaltung wurde eine höhere Kapazität verwendet, dies verbessert die Stabilität der Schaltung, kann aber zur Vergrößerung der Startzeit führen [1].


Abb. 4: Quarzoszillator mit Kapazitäten

## Programmier-/Debugging-Schnittstelle

Die in Abbildung 5 dargestellten Schaltungsblöcke ermöglichen das Programmieren und Debuggen des PIC [1].


Abb. 5: Schnittstelle des Mikrocontrollers zum Debuggen/Programmieren

## Spannungsregulierung

Da die Schaltung laut Anforderungen mit einer 9 V-Batterie betrieben wird, muss ein Spannungsregulierer eingesetzt werden, um die Spannung auf die Betriebsspannung des PIC von 5 V zu reduzieren. In der fertigen Schaltung wird dazu der ON Semiconductor NCV1117ST50 genutzt. Im Schaltplan wird allerdings ein AP1117E50G eingesetzt, der die gleiche Pin-Belegung und Funktionsweise besitzt. Die Kapazitäten an Ein- und Ausgang sorgen dafür, dass der Regelkreis im Chip des Spannungsregulierers nicht beginnt zu schwingen. Diese Fähigkeit ist wichtig, um eine stabile Ausgangsspannung bereitzustellen.


Abb. 6: Batterie mit Spannungsregulierer und Kapazitäten

## Schalter

Die Schalter, welche an verschiedenen Pins von Port B des Mikrocontrollers angeschlossen sind, sorgen dafür, dass im ausgeschalteten Zustand die Versorgungsspannung von 5 V am jeweiligen Pin anliegt. Im angeschalteten Zustand werden die Pins auf Masse gezogen.


Abb. 7: Verschaltung der Taster als Active-Low-Elemente

## IR-LED

Für das Aussenden der Lichtsignale wird eine 5 mm Vishay Infrarot-LED verwendet. Der Vorwiderstand berechnet sich mit dem Spannungsabfall an der LED und dem gewünschten Strom im diesem Zweig. Laut Datenblatt liegt die Nennspannung bei 1,35 V, der Nennstrom kann bis zu 100 mA betragen [5]. Mit dem Ohm’schen Gesetz ergibt sich ein Widerstand von 36,5 Ω. Mit dieser Berechnung wird ein Widerstand von 47 Ω gewählt, damit der Strom durch die LED mit Sicherheit nicht zu groß wird.
Die LED wird an Pin RC1 angeschlossen, da an diesem Pin mit wenig Aufwand eine modulierte Rechteckspannung mit dem PWM-Modul des PIC ausgegeben werden kann. Diese wird für das RC5-Protokoll benötigt.


Abb. 8: Verschaltung der IR-LED mit Vorwiderstand

# Layout

In Abb. 9 ist das finale Layout zu sehen, mit dem auch die reale Platine erstellt wurde.


Abb. 9: PCB-Layout in Eagle mit Platzierung und Routing

## Anordnung der Bauteile

Beim Layout werden zuerst funktionale Gruppen mit Bauteilen, die direkt miteinander verbunden sind, gebildet. Diese werden dann auf der Platine angeordnet. Die funktionale Gruppe um den Quarz sollte möglichst nah an den angeschlossenen Eingängen des Mikrocontrollers liegen, da der Quarz sehr anfällig gegenüber Störsignalen ist.
Die Kondensatoren C7 und C8 liegen ebenfalls möglichst nah an den verbundenen Pins zur Stromversorgung, um Schwankungen in der Versorgungsspannung durch Störungen möglichst schnell auszugleichen.
Zusätzlich ist bei der Spannungsregulierung eine Kühlfläche vorgesehen, um die entstehende Wärme möglichst gut zu verteilen und den Chip dadurch zu kühlen.
Die Taster werden so angeordnet wie das bei handelsüblichen Fernbedienungen der Fall ist und in Abb.2 skizziert wurde. Auch die Anordnung der LED am vorderen und die der Batterie am hinteren Ende der Fernbedienung wird aus bekannten Fernbedienungen übernommen.

## Routing

Beim Routing wird besonders darauf geachtet, genug Abstand zwischen den Leiterbahnen einzuhalten und möglichst breite Leiterbahnen und keine rechten Winkel zu verwenden. Diese Grundsätze helfen, elektromagnetische Störungen zu minimieren.
Die Unterseite der Platine besteht zum größten Teil aus einer Masse-Fläche, so werden Masse-Schleifen vermieden und das Routing der Masse-Leitungen vereinfacht [6].
Die Größe und Form der Durchkontaktierungen, die Breite der Leiterbahnen und die Dimensionen von Tastern und SMD-Bauteilen wurden in Absprache mit dem Labor gewählt.

## Platine

Die fertige Platine ist in den Abbildungen 10 und 11 zu sehen.


Abb. 10 (links): Fertige Platine obere Seite, Abb. 11 (rechts): untere Seite

# Software

Nachdem die Hardware fertiggestellt ist, fehlt für eine funktionsfähige Fernbedienung nur noch die Programmierung des Mikrocontrollers. Diese wird zunächst in 2 Teile aufgeteilt. Der erste Teil beschäftigt sich mit dem Auslesen der gedrückten Taster und dem Zuordnen von Taster und Befehl. Im zweiten Teil wird der Befehl dann mit dem RC5-Protokoll gesendet.

## Einsatz von Interrupts

Damit eine dauerhafte Schleife im Hauptprogramm vermieden werden kann, welche die Pegel an den Pins abfragt, kann die Interrupt-Funktion des Mikrocontrollers verwendet werden. So kann der PIC die meiste Zeit in den Sleep-Modus versetzt werden und spart dadurch Energie.
Das Hauptprogramm wird im Sleep-Modus gestoppt. Dann kann jederzeit durch eine Spannungsänderung an einem Interrupt-Pin eine Unterroutine aufgerufen werden, die den gedrückten Taster ausliest und den passenden Befehl sendet.
Der Ablauf dabei ist wie folgt: Bei einem Interrupt vervollständigt der Microcontroller die letzte Anweisung und speichert den Inhalt des Program-Counters und des Status-Registers auf dem Stack. Dann lädt er automatisch die Adresse 0x0008 (spezifisch bei PIC18F4525) in den Program-Counter und springt so an diese Stelle im Programm, um dort eine vom Benutzer geschriebene Routine auszuführen. Vor der letzten Anweisung muss das entsprechende Interrupt Flag, welches gesetzt wurde, um das Auftreten der Unterbrechung zu kennzeichnen, wieder zurückgesetzt werden. Die letzte Anweisung der Routine sorgt für eine sichere Rückkehr des Program-Counters zum aktuellen Befehl in der Hauptroutine, weitere Unterbrechungen werden dann wieder ermöglicht [3].

## Initialisierung der Interrupts im Programm

In der Fernbedienung werden verschiedene Interrupts genutzt. Die Taster an den Pins RB 0, 1 und 2 lösen die flankengesteuerten, externen Interrupts INT0, INT1 und INT2 aus. Die Pins RB 4 und 5 dagegen lösen Port B On Change-Interrupts aus, welche auf Zustandsänderungen der beiden Pins reagieren. Diese Interrupts werden im Folgenden initialisiert.
Dies geschieht durch das Setzen oder Rücksetzen spezieller Bits in den passenden Konfigurations-Registern, um die Einstellungen der Interrupts festzulegen.
Dabei ist es wichtig die Interrupt-Flags zurückzusetzen, damit keine fälschliche Unterbrechung stattfindet, bevor das Hauptprogramm gestartet wird. Außerdem werden die Interrupts durch das Setzen des jeweiligen Interrupt Enable-Bits aktiviert und ihre Priorität festgelegt. Im Fall von INT0/INT1/INT2 wird auch die Flanke angegeben, bei welcher ein Interrupt ausgelöst wird. Am Ende werden die Global Interrupt Enable-Bits gesetzt, um die Interrupts mit hoher und niedriger Priorität im Allgemeinen zu aktivieren.

init_portb:
clrf PORTB | ; reset port b and its latch
clrf LATB

bcf ADCON0,ADON
; disable ad converter and reset its configuration bits
movlw 0xFF | ; declare all Pins at PORTB as digital
movwf ADCON1 | ; pins
movlw 0xFF | ; set all port b pins as inputs
movwf TRISB

movlw b'00111011' ; set pins with buttons to '1' to prevent movwf PORTB
;triggering interrupt because buttons
;create high state as default (active low buttons)
bcf INTCON,INT0IF | ; clear interrupt flags for pins rb
bcf INTCON3,INT1IF | ; 0/1/2/4/5 to prevent getting multiple
bcf INTCON3,INT2IF | ; interrupts with one button press
bcf INTCON,RBIF

bcf INTCON2,RBPU
; activate internal weak pull-ups for all pins on port b

bsf INTCON,INT0IE
bsf INTCON3,INT1IE
bsf INTCON3,INT2IE
bsf INTCON,RBIE
; enable interrupts for interrupt 0/1/2 and on change ; interrupts on port b

bcf INTCON2,INTEDG0
bcf INTCON2,INTEDG1
bcf INTCON2,INTEDG2

; set interrupts 0/1/2 to trigger on falling edge

bsf RCON,IPEN | ; enable interrupt priorities

bsf INTCON3,INT1IP
; set interrupt priority for interrupts 1 & 2 , (0 always high)

bsf INTCON3,INT2IP
; and on change interrupt to high priority

bsf INTCON2,RBIP

bsf INTCON,GIEH
; activate all high priority interrupts

bsf INTCON,GIEL
;activate all low priority interrupts bsf INTCON,GIE
; activate all interrupts

return

## Interrupt-Routine

Um in der Anwendung des Programms nachvollziehen zu können, welcher Schalter gedrückt wurde, wurde innerhalb der High Interrupt Routine ein Algorithmus implementiert, welcher die jeweiligen Interrupt-Flags und die Zustände der Pins abfragt. Wenn der entsprechende Schalter erkannt wurde, wird eine Sendefunktion mit einem bestimmten RC5-Befehl ausgeführt, welche dann den passenden Befehl lädt.

HighInt:
btfsc INTCON,RBIF ; pin 4/5 pressed
call send_rb_on_change
btfsc INTCON,INT0IF ; pin 0 pressed call send_rb_0
btfsc INTCON3,INT1IF ; pin 1 pressed call send_rb_1
btfsc INTCON3,INT2IF ; pin 2 pressed
call send_rb_2
retfie FAST

In der Interrupt-Routine wird also zuerst ermittelt, ob sich eine Änderung an den Pins RB4 und RB5 ereignet hat. In der Routine send_rb_on_change wird dann mit den Pin-Zuständen ermittelt, welcher Pin genau für den Interrupt verantwortlich war.

send_rb_on_change:

btfss PORTB,4 ; check if pin 4 was pressed call send_rb_4
btfss PORTB,5 ; check if pin 5 was pressed
call send_rb_5
bcf INTCON,RBIF ; clear interrupt flag to prevent multiple ; interrupts
return

In den daraufhin aufgerufenen Sende-Routinen wird das Interrupt-Flag zurückgesetzt, um mehrfache Unterbrechungen zu vermeiden und wieder in das Hauptprogramm zu springen. Außerdem wird der Bit-Buffer, welcher die Befehle zum Senden enthält, mit dem passenden Befehl überschrieben. Hier ist beispielhaft eine Sende-Routine dargestellt.

send_rb_0:
bsf skip_release,0 | ; set skip_release<0> to prevent
| ; skipping this command
movlw b'00110101' | ; move rc5 code for stop command to
movwf bit_buffer_h | ; bit buffer
movlw b'00110110' | ; 00 in beginning not significant
movwf bit_buffer_l
bcf INTCON,INT0IF | ; clear interrupt flag to prevent
| ; multiple interrupts
return

Die Schnittstelle wurde am Modell getestet, um das Programmverhalten beim Drücken der Taster zu beobachten.

## Bitübertragung mit dem RC5-Protokoll

Das RC5-Protokoll ist eine von Philips entwickelte Methode zur Kommunikation mit verschiedenen Endgeräten, wie z.B. CD-Spielern und Fernsehern. Eine Fernbedienung für dieses Protokoll sendet mit einer Wellenlänge von 940 bis 950 nm, welche bei der verwendeten Infrarot-LED mit 940 nm gegeben ist. Ein Befehl der Fernbedienung besteht aus insgesamt 14 Bits, die nacheinander gesendet werden. Die Bits sind in Abb. 13 dargestellt und haben die folgende Bedeutung [7]:
- 2 Start-Bits, immer logisch ‚1’
- 1 Toggle-Bit, welches seinen Wert bei jedem neuen Tastendruck ändert
- 5 Adress-Bits, um ein konkretes Gerät anzusprechen, wie bspw. CD-Player, TV, Audio-Vorverstärker
- 6 Befehls-Bits


Abb. 12: Zeitliche Abfolge der Bits im RC5-Befehl

Ein Bit besteht dabei immer aus einer Low-Phase und einer Puls-Phase mit einer Länge von je 888,89 μs. Wie in Abb. 12 zu sehen, verändert die Reihenfolge dieser zwei Phasen den Zustand des Bits zwischen High und Low [7].


Abb. 13: Reihenfolge der Puls- und Ruhephasen und deren Bedeutung als Bit

Eine Puls-Phase besteht dabei immer aus 32 einzelnen Pulsen einer Rechteckspannung mit einer Frequenz von 36 kHz. Die Dauer der High-Phasen der einzelnen Pulse ist etwa ⅓ bis ¼ der Periodendauer der Rechteckschwingung. So wird weniger Leistung benötigt, als bei einer High-Phase von 50%.

## Konfiguration des PWM-Moduls

Die Rechtecksignale werden an Pin RC1 mit dem „Capture/Compare/PWM Module (CCP)” im PWM-Modus erzeugt. Alle nachfolgenden Ausführungen beruhen auf Informationen im Kapitel 15.4 des Handbuchs für den PIC18F4525 [1].
Bei der Konfiguration wird zunächst die Periodendauer bzw. Frequenz der benötigten Trägerschwingung definiert. Diese kann über die Gleichungen 1 und 2 berechnet werden.

T

Period = [n

PR2 + 1]⋅4⋅T
OSC
- n
TMR
Gleichung 1

n

PR2 =

f
OSC
4⋅f

Period·n
TMR

− 1≈44ℎ
Gleichung 2
Die Frequenz fPeriod

ist dabei die Träger-Frequenz von 36 kHz. Die Frequenz des Oszillators fOSC ist durch den 10 MHz-Quarz vorgegeben. Der Prescaler-Value nTMR = 1 wird aus den Beispielen im Handbuch gewählt. Der berechnete Wert nPR2 wird bei der Konfiguration in das PR2-Register eingetragen, um die gewünschte Frequenz der Rechteckspannung zu erreichen. Durch Leitungsverzögerungen und Ungenauigkeiten in der Schaltung muss dieser Wert im realen Programm angepasst werden.
Außerdem muss der Wert für den Duty Cycle berechnet und eingestellt werden. Aus Gleichung 3, die von Microchip vorgegeben wurde [8], ergibt sich ein Wert von 0,250. Da dieser Wert in diesem Zusammenhang nicht als zehnstellige binäre Zahl dienen kann, wird dieser Wert experimentell zu 0x54 bestimmt. Die ersten acht MSBs werden in das CCPR2L-Register und die zwei verbleibenden LSBs in das CCP2CON-Register an Stelle 5 und 4 eingetragen.
Pulse Widtℎ = (CCPR2L: CCP2CON < 5: 4 > ⋅

1
f
OSC
- n
TMR

)

Gleichung 3

init_pwm:
banksel PR2
movlw 0x46 | ; configure period time with 0x46 for
movwf PR2 | ; 36 kHz frequency
movlw b'00010101' | ; configure duty cycle to be between 1/3
movwf CCPR2L | ; and 1/4 of the whole signal
movlw b'00001100' | ; configure pwm mode and 2 lsbs of
movwf CCP2CON | ; duty cycle
bcf PIR1,TMR2IF | ; clear interrupt flag to prevent
| ; multiple interrupts
bcf T2CON,T2CKPS1 | ; set timer 2 clock prescaler value
bcf T2CON,T2CKPS0 | ; to ‘00’

## Konfiguration von Timer 0

Während die Rechteckspannung von CCP-Modul und Timer 2 erzeugt wird, muss auch die Sendedauer der Rechteckspannung reguliert werden. Wie bereits erwähnt, werden in der Sendephase für jedes Bit 32 Pulse gesendet, dies entspricht einer Dauer von 888,89 μs. Diese Sendedauer wird von Timer 0 beendet, der von einem entsprechend eingestellten Wert bis zum Überlauf hochzählt. Beim Überlauf von 0xFFFF zu 0x0000 wird ein Interrupt erzeugt, über dessen Interrupt Service Routine dann die Sendephase beendet werden kann. Der Startwert des Timers ergibt sich durch die Berechnungen in Gleichung 4 [9].

f

OSC = 10MHz → f

Timer =

f
OSC
4 = 2, 5MHz→T

Timer =

1
f
Timer

= 0, 4μs

n

Timer = 65536 −

T
Sendedauer
T
Timer

= 65536 −

888,89μs
0,4μs ≈0xF752

Gleichung 4

Im Code wird der Timer dann als 16 Bit-Timer konfiguriert, der mit der Taktfrequenz des PIC vom Startwert 0xF752 hochzählt. Der Prescaler-Wert folgt ebenfalls aus den Berechnungen und kann hier auf “000” gesetzt werden. Außerdem wird für den Overflow von Timer 0 ein Low Priority Interrupt aktiviert, der, wie bereits erwähnt, das Ende der Dauer eines halben gesendeten Bits markiert.

movlw b'00001000' | ; configure timer 0 with 16 bit, internal
movwf T0CON | ; clock and prescaler value of '000'
movlw 0xF7 | ; set start value for timer 0
movwf TMR0H
movlw 0x52
movwf TMR0L
bcf INTCON,TMR0IF ; clear interrupt flag to prevent multiple ; interrupts
bsf INTCON,TMR0IE | ; enable timer 0 interrupt
bcf INTCON2,TMR0IP | ; set interrupt priority to low
bsf INTCON,GIE | ; enable all interrupt

## RC5-Übertragung im Code

Der folgende Code-Ausschnitt zeigt beispielhaft die Übertragung einer logischen ‚0’ in Assembler. Dabei wird aus der Main-Routine die entsprechende Sende-Routine aufgerufen, die dann zuerst 888,89 μs lang die 32 Pulse der Rechteckspannung sendet und dann 888,89 μs lang den Ausgang auf den Low-Zustand legt.

send_0:
call pwm_delay | ; send logic '0' by first sending 32 pwm
call tmr_delay | ; pulses and then 889 us delay
return

In der pwm_delay-Routine werden Timer 0 und Timer 2 auf ihre Anfangswerte gesetzt und dann gestartet. Beim Ausführen des Codes auf dem realen PIC wurde festgestellt, dass der erste Puls nur aus einer Low-Phase besteht, daher wird der Ausgangspin vor dem Starten des ersten Pulses manuell gesetzt.

pwm_delay:
movlw 0xF7 | ; set start value for timer 0 which
movwf TMR0H | ; counts to overflow
movlw 0x70
movwf TMR0L
movlw 0x00 | ; set start value for timer 2 which
movwf TMR2 | ; counts for each pulse
bsf LATC,1 | ; set first pulse manually
bsf T0CON,TMR0ON | ; start timer 0 for 889 us delay
bsf T2CON,TMR2ON | ; and timer 2 for pwm
call delay_loop | ; wait for timer 0 low interrupt

return

Die tmr_delay-Routine ist ähnlich aufgebaut. Sie startet allerdings nur Timer 0 und nicht Timer 2, da für die Ruhephase nur Timer 0 gebraucht wird, um die 888,89 μs abzuzählen.

tmr_delay:
;start timer 0 for pausing
movlw 0xF7 | ; set start value for timer 0 which counts
movwf TMR0H | ; to overflow
movlw 0x70
movwf TMR0L
bsf T0CON,TMR0ON | ; start timer 0
call delay_loop | ; wait for timer 0 low interrupt
return

Außerdem gibt es noch eine Routine, die durchlaufen wird, bis ein Timer 0 Low Interrupt ausgelöst wird. Diese Schleife wartet darauf, dass das tmr_done-Flag von der Low Interrupt-Routine gesetzt wird.

delay_loop: | ;wait for timer 0 interrupt to end half bit
btfss tmr_done,0
bra delay_loop
bcf tmr_done,0
return

In der Low Interrupt-Routine werden dann die Timer gestoppt, die das halbe Bit erzeugen, und das bereits erwähnte tmr_done-Flag gesetzt.

LowInt:
bcf T0CON,TMR0ON | ; stop timers 0 and 2 which are used for
bcf T2CON,TMR2ON | ; pwm pulses and do not need to be used
; after sending these pulses is finished

bcf INTCON,TMR0IF ; clear interrupt flag of timer 0 which ; triggers the low interrupt, clearing ; prevents multiple interrupts for one ; overflow event
bsf tmr_done,0
retfie FAST

## Main-Routine

In der Main-Routine, die zuerst ausgeführt wird, werden zunächst alle Routinen zur Initialisierung aufgerufen. So werden die Kontrollbits für die Ein- und Ausgangsports und das PWM-Modul, wie in den vorherigen Abschnitten angesprochen, passend gesetzt.

Main:
call init_portc | ; configure ports and pwm module
call init_portb
call init_ports
call init_pwm

Dann wird der Mikrocontroller direkt in den Sleep-Modus versetzt, um dort auf den nächsten Tastendruck und den dadurch ausgelösten Interrupt zu warten. Dazu wird das IDLEN-Bit zurückgesetzt, womit der Modus des Mikrocontrollers ausgewählt werden kann.

wait_cmd_loop
bcf OSCCON,IDLEN ; go to sleep until next button is pressed sleep
nop
nop
nop

Nachdem der PIC dann durch einen Tastendruck in den normalen Run-Modus versetzt und der gewünschte Befehl in der Interrupt-Routine in den Bit-Buffer kopiert wurde, wird das Toggle-Bit des Befehls angepasst. Wie im Abschnitt zur Theorie hinter dem RC5-Code erwähnt, toggelt dieses Bit bei jedem neu gesendeten Befehl. Das Toggeln und Setzen im Bit-Buffer ist im folgenden Code-Abschnitt dargestellt.

btg bit_buffer_toggle,0 ; set toggle bit in bit_buffer btfsc bit_buffer_toggle,0
bsf bit_buffer_h,3
btfss bit_buffer_toggle,0
bcf bit_buffer_h,3

Dann werden die Sende-Routinen gestartet. Dazu werden die Bits des Bit-Buffers nach und nach in das Carry-Bit übernommen und dann die passende Sende-Routine für eine logische ‚0’ oder ‚1’ gestartet. Damit der Bit-Buffer seinen Wert behält und beim Senden nicht verloren geht, werden die Schiebe-Operation mit einem temporären Bit-Buffer durchgeführt, dessen Wert vor dem Senden aus dem Bit-Buffer kopiert wird.
Die ersten zwei Bits werden beim Senden übersprungen, da ein Befehl beim RC5-Code immer nur 14 Bits enthält. Der Bit-Counter zählt diese 14 Bits ab und beendet die Sende-Schleife, wenn alle Bits gesendet wurden.

send_cmd_loop
movlw d'14' | ; send 14 bits
movwf bit_ctr
clrf tmr_done | ; reset flag that stops delay loop
| ; during sending
movf bit_buffer_h,W | ; send bit buffer from temporary
| ; constants to keep value
movwf bit_buffer_h_tmp
movf bit_buffer_l,W
movwf bit_buffer_l_tmp
rlcf bit_buffer_l_tmp | ; skip first 2 bits because only 14
rlcf bit_buffer_h_tmp | ; bits hold information
rlcf bit_buffer_l_tmp
rlcf bit_buffer_h_tmp

send_bit_loop
rlcf bit_buffer_l_tmp | ; transfer the next bit that should
rlcf bit_buffer_h_tmp | ; be sent in carry bit
btfss STATUS,C | ; test carry bit to see if '0' or
call send_0 | ; '1' should be sent
btfsc STATUS,C
call send_1
decfsz bit_ctr | ; send next bit if not all bits are
bra send_bit_loop | ; sent already

Dieser Sende-Vorgang wird für den zu sendenden Befehl mehrmals wiederholt. Dies beruht auf der Beobachtung, dass der Empfänger bei einzeln gesendeten Befehlen nicht zuverlässig reagiert. Das mehrmalige Senden simuliert einen längeren Tastendruck, da ein richtiger Algorithmus für längere Tastendrücke aus Zeitgründen nicht realisiert werden konnte. Hierfür wird der Command-Counter zuerst mit der Anzahl der für einen Tastendruck gesendeten Befehle initialisiert.

movlw d'3' | ; send every command 3 times
movwf cmd_ctr

Dieser Counter wird nach dem Senden des Befehls dekrementiert, um die Sende-Routine so oft durchzuführen, wie bei der Initialisierung gewünscht.

decfsz cmd_ctr | ; send command again if it was not sent 3
bra send_cmd_loop | ; times already

Zwischen den gesendeten Befehlen wird mit dem folgenden Code-Abschnitt eine Pause eingebaut. So kann der Empfänger besser zwischen den Befehlen unterscheiden. Dieses Prinzip wurde der tatsächlichen Fernbedienung des CD-Spielers entnommen. Der Code besteht aus zwei verschachtelten Schleifen, deren Zähler nacheinander herunterzählen. Die Verzögerung, die durch diesen Code entsteht, liegt bei ca. 9 ms.

movlw 0xFF | ; load inner and outer delay counter to
movwf rand_delay_ctr ; create delay between sending the
movlw 0x40 | ; command multiple times
movwf rand_delay_ctr_outer
wait_rand_delay_outer | ; create delay of around 9 ms
wait_rand_delay
nop
nop
decfsz rand_delay_ctr
bra wait_rand_delay
decfsz rand_delay_ctr_outer
bra wait_rand_delay_outer

Wenn der Befehl mehrmals gesendet wurde, wird der PIC wieder in den Sleep-Modus versetzt, um auf den nächsten Befehl zu warten.

bra wait_cmd_loop ; go to sleep after sending 3 commands

Eine weitere Beobachtung war, dass der Befehl beim Drücken der Taster an den Pins RB4 und RB5 zweimal gesendet wurde. Die On Change-Interrupts dieser Pins sind nämlich sowohl auf die steigende, wie auch auf die fallende Flanke sensitiv. Als Lösung wird das skip_release-Flag eingeführt. Dieses wird bei jedem der zwei ausgelösten Interrupts getoggelt, sodass es für die zwei Flanken unterschiedliche Werte hat. Das Senden des Befehls wird dann ausgesetzt, wenn das Flag den Wert ‚1’ hat, also der Interrupt beim Drücken der Taste und nicht beim Loslassen erzeugt wurde. So wird für einen Tastendruck auch nur einmal die Sende-Routine durchlaufen. Beim Interrupt durch RB0, RB1 und RB2 wird das Bit manuell in der Interrupt-Routine gesetzt, um diesen Befehl auf jeden Fall zu senden. Der folgende Code-Abschnitt zeigt den Einstiegspunkt beim Überspringen des Befehls und die Abfrage des Flags.

skip_cmd
movlw 0x00 | ; initialize skip_release flag
movwf skip_release

wait_cmd_loop
bcf OSCCON,IDLEN | ; go to sleep until next button is
sleep | ; pressed

btfss skip_release,0 ; skip second command when button is
bra skip_cmd | ; released at rb4 and rb5 because
| ; interrupt is triggered on change, not
| ; only on falling edge
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

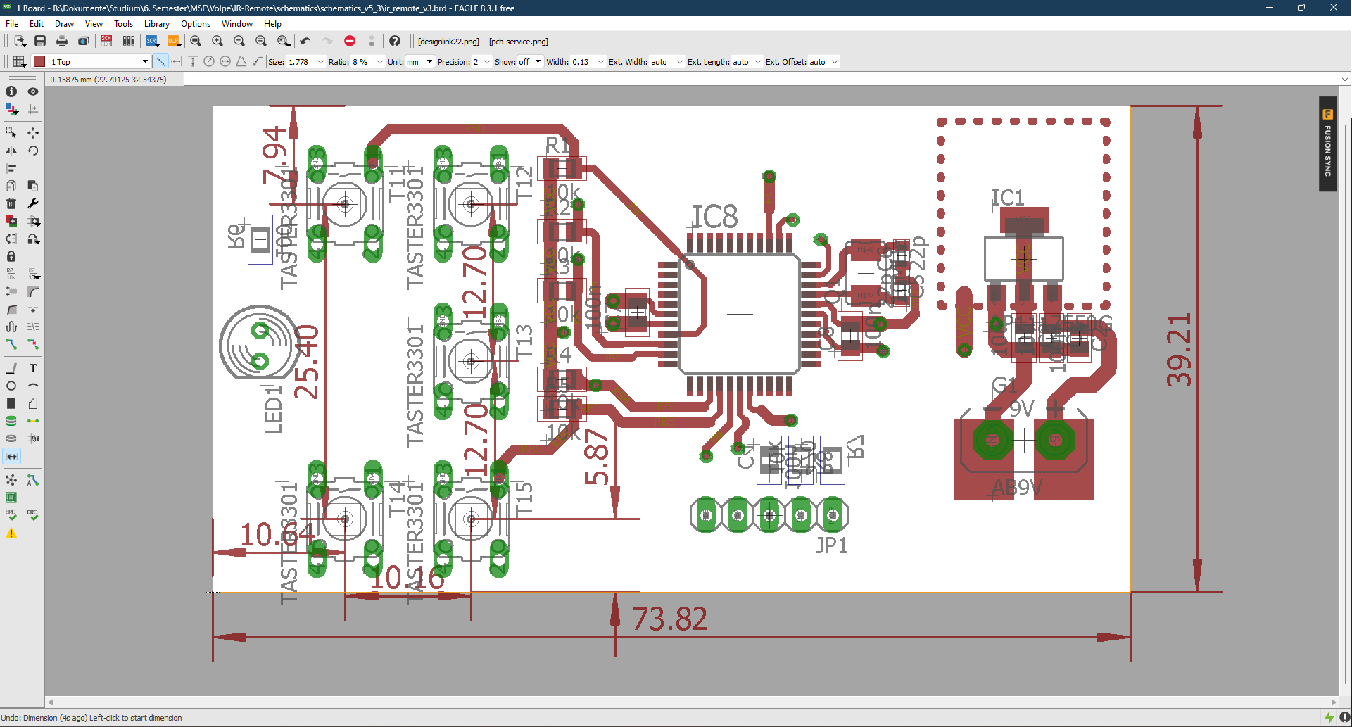
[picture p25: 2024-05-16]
schematics/schematics_v5_3/layout_dimensions.png

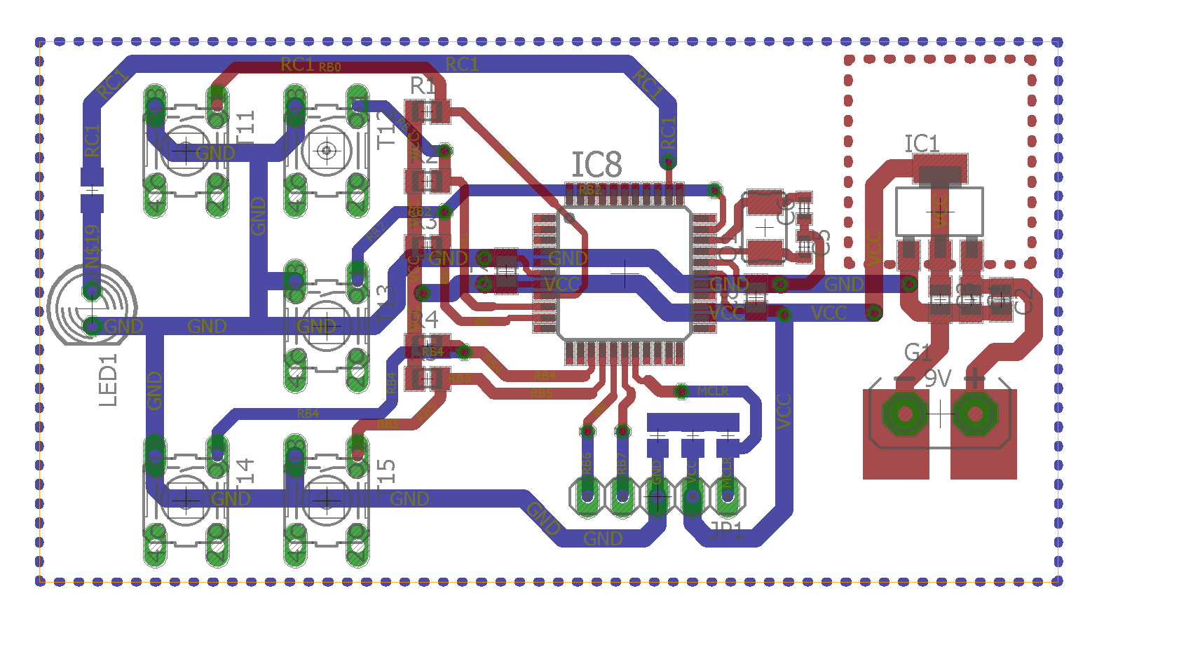
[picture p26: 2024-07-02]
schematics/schematics_v7_final_final/layout.png

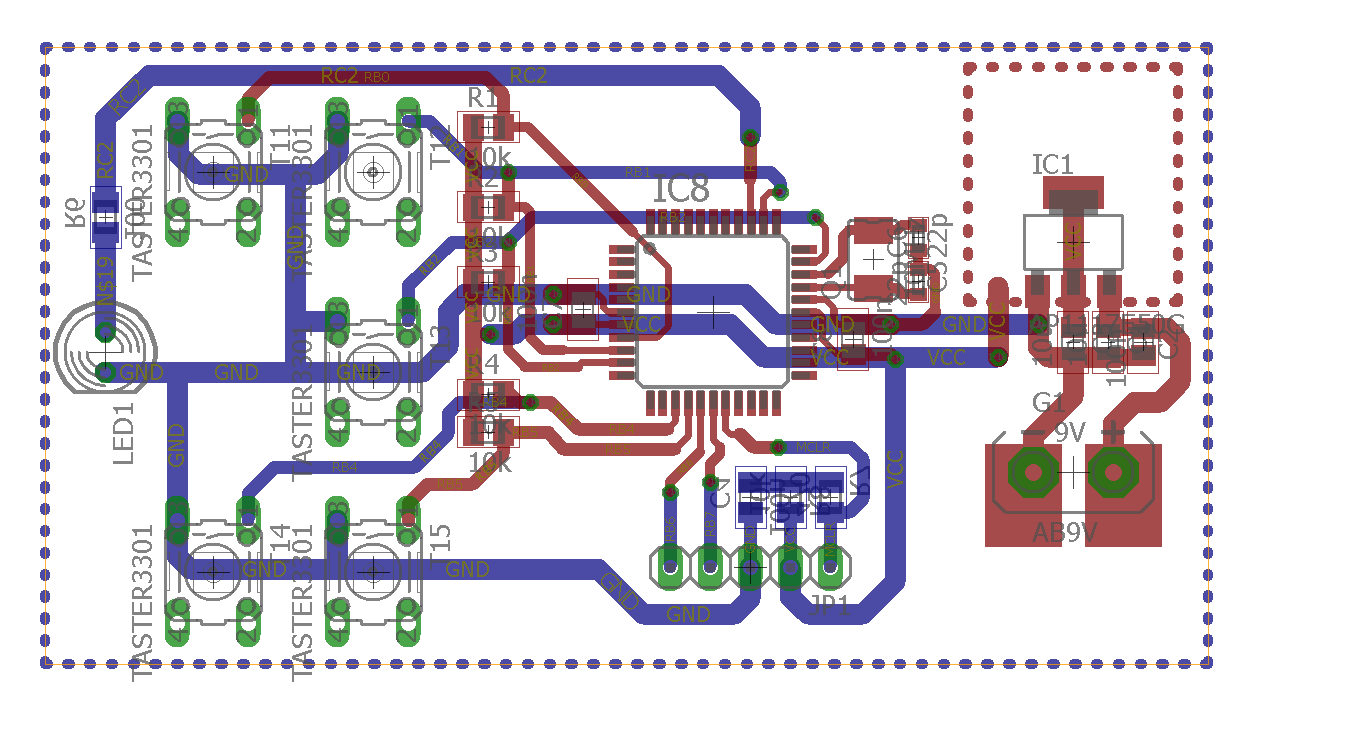
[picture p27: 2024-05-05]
schematics/schematics_v6_final/layout.png

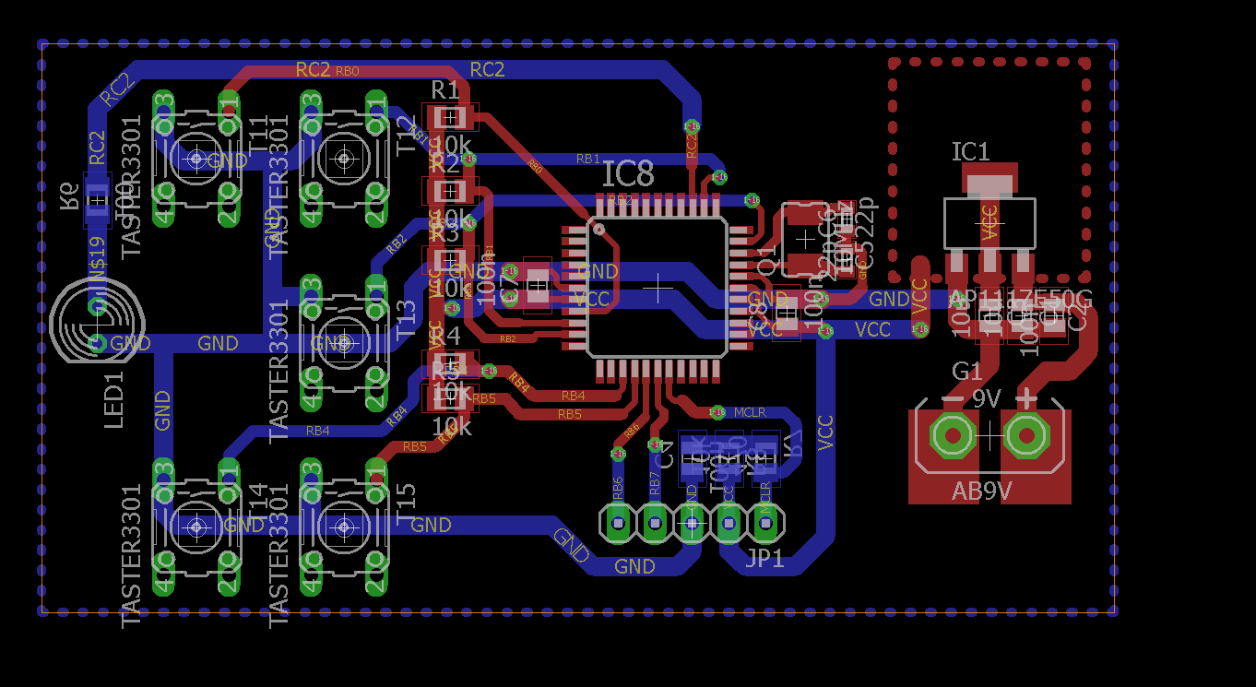
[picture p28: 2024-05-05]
schematics/schematics_v6_final/layout_dark.png

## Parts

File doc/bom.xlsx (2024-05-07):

Qty | Value | Device | Package | Parts | Description | POPULARITY
1 |  | LED5MM | LED5MM | LED1 | LED
1 |  | PIC18F4520 | TQFP44 | IC8
1 |  | PINHD-1X5 | 1X05 | JP1 | PIN HEADER | 69
1 |  | R-EU_M0805 | M0805 | R6 | RESISTOR, European symbol
4 |  | C-EUC0805 | C0805 | C2, C4, C7, C8 | CAPACITOR, European symbol
1 |  | XTAL_HC5032 | QUARZ_HC5032/2 | Q1 | 9HT10-32.768KDZF-T
6 |  | R-EU_M0805 | M0805 | R1, R2, R3, R4, R5, R8 | RESISTOR, European symbol
2 |  | C-EUC0805 | C0805 | C1, C3 | CAPACITOR, European symbol
2 |  | C-EUC0603_WE | C0603_WE | C5, C6 | CAPACITOR, European symbol
1 |  | R-EU_M0805 | M0805 | R7 | RESISTOR, European symbol
1 |  | AB9V | AB9V | G1 | 9-V BATTERY CLIP
1 |  | REG1117-2OUT | SOT223 | IC1 | 800mA and 1A Low Dropout (LDO) Positive Regulator
5 |  | TASTER3301 | TASTER3301 | T11, T12, T13, T14, T15

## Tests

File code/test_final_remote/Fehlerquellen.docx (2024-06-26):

# Fehlerquellen

- Port C resetten → Pin RC0 als Eingang beschaltet!
- Port B als Eingang
- Andere Ports als Eingänge + Interrupts konfigurieren
- PWM-Modul konfigurieren
- Schlafen
- Interrupt weckt auf
  - Wenn Interrupt Flag von Pin gesetzt → btfss? Toggle-Bit nicht vorhanden?
- Nächstes Bit wird aus bit_buffer rotiert
- 0 oder 1 senden, dann in delay loop warten
- Low Interrupt beendet Delay über tmr_done Flag
- Nächstes Bit senden, bis alle Bits gesendet

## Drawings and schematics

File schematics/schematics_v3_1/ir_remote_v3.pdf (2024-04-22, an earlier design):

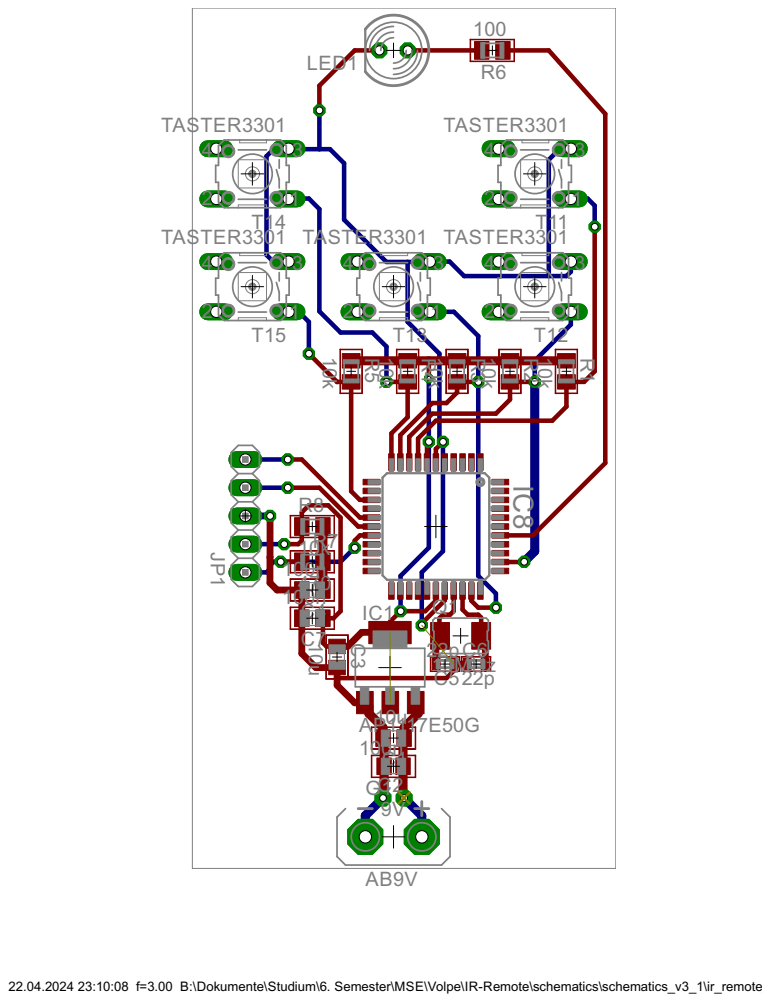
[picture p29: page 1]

22.04.2024 23:10:08 f=3.00 B:\Dokumente\Studium\6. Semester\MSE\Volpe\IR-Remote\schematics\schematics_v3_1\ir_remote_v3.brd

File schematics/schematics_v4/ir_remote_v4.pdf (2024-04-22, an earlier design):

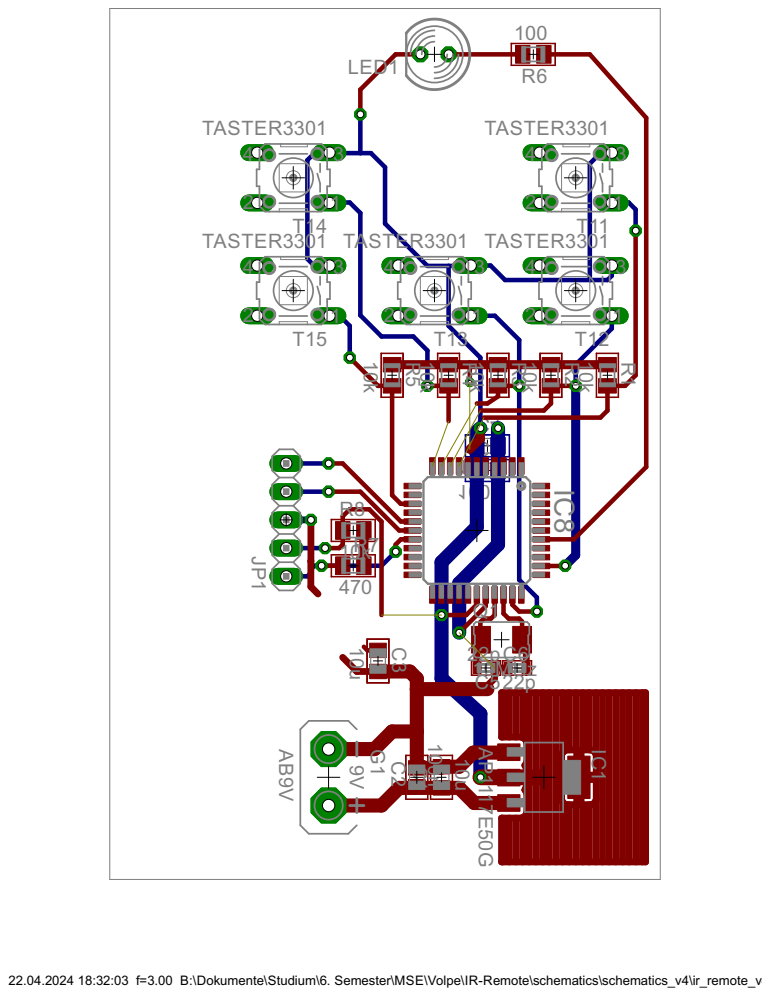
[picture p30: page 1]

22.04.2024 18:32:03 f=3.00 B:\Dokumente\Studium\6. Semester\MSE\Volpe\IR-Remote\schematics\schematics_v4\ir_remote_v4.brd

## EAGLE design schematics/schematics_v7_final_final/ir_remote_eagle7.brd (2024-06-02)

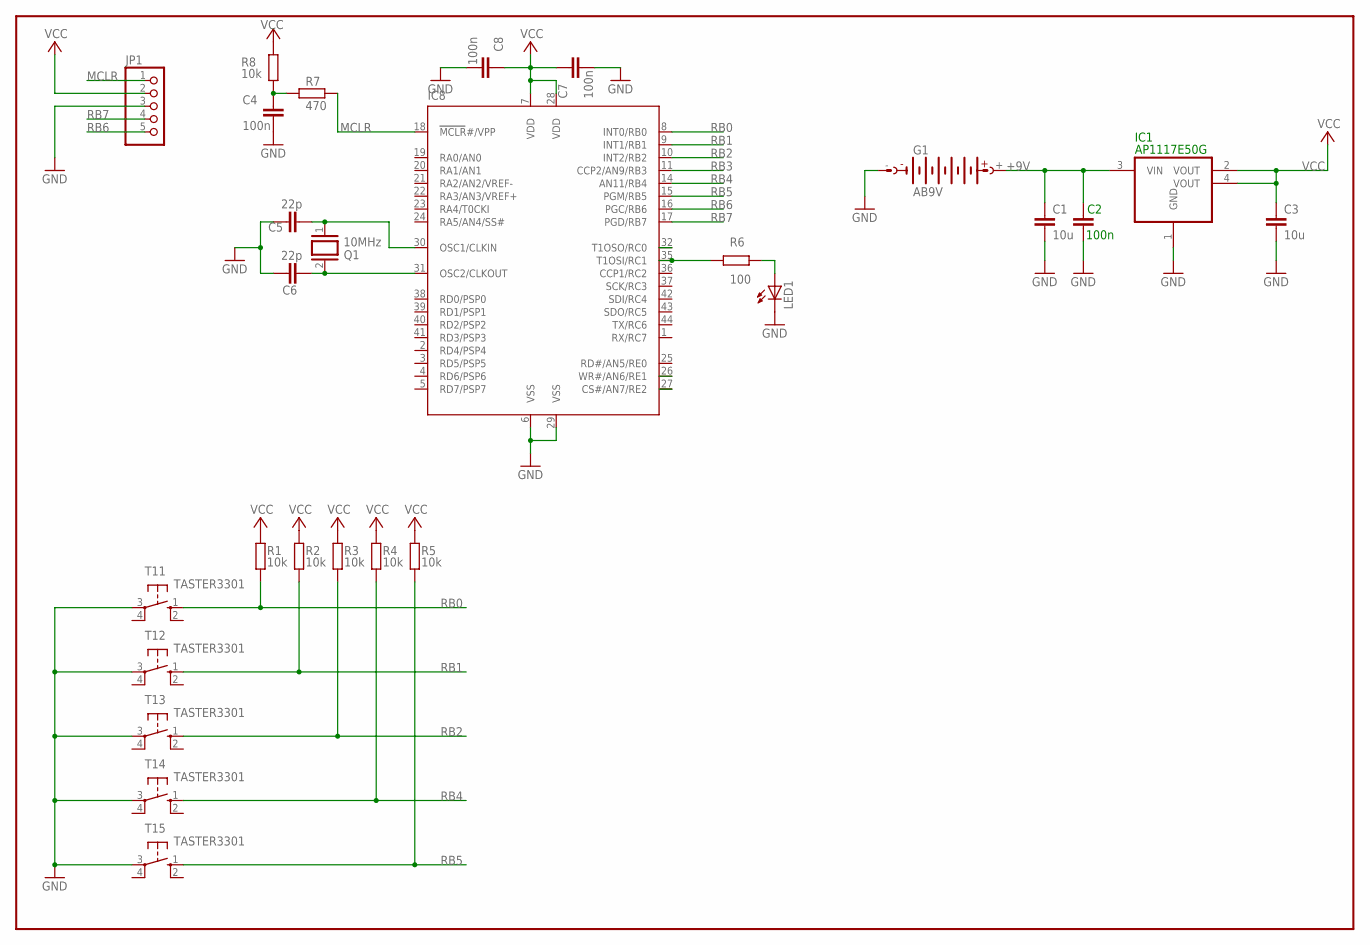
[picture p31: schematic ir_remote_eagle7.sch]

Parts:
C1, C3: 10u; C0805
C2, C4, C7, C8: 100n; C0805
C5, C6: 22p; C0603_WE
G1: AB9V
IC1: AP1117E50G; SOT223
IC8: PIC18F4520; TQFP44
JP1: PINHD-1X5; 1X05
LED1: LED5MM
Q1: 10MHz; QUARZ_HC5032/2
R1, R2, R3, R4, R5, R8: 10k; M0805
R6: 100; M0805
R7: 470; M0805
T11, T12, T13, T14, T15: TASTER3301

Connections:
+9V: C1.1, C2.1, G1.+, IC1.3 (VIN)
D0_LCD: IC8.27 (CS#/AN7/RE2)
D1_LCD: IC8.26 (WR#/AN6/RE1)
GND: C1.2, C2.2, C3.2, C4.2, C5.1, C6.1, C7.2, C8.2, G1.-, IC1.1 (GND), IC8.6 (VSS), IC8.29 (VSS), JP1.3, LED1.K (C), T11.3, T12.3, T13.3, T14.3, T15.3
MCLR: IC8.18 (MCLR#/VPP), JP1.1, R7.1
unnamed: LED1.A, R6.2
unnamed: C4.1, R7.2, R8.2
unnamed: C5.2, IC8.30 (OSC1/CLKIN), Q1.1
unnamed: C6.2, IC8.31 (OSC2/CLKOUT), Q1.2
RB0: IC8.8 (INT0/RB0), R1.2, T11.1 (S)
RB1: IC8.9 (INT1/RB1), R2.2, T12.1 (S)
RB2: IC8.10 (INT2/RB2), IC8.32 (T1OSO/RC0), R3.2, T13.1 (S)
RB3: IC8.11 (CCP2/AN9/RB3)
RB4: IC8.14 (AN11/RB4), R4.2, T14.1 (S)
RB5: IC8.15 (PGM/RB5), R5.2, T15.1 (S)
RB6: IC8.16 (PGC/RB6), JP1.5
RB7: IC8.17 (PGD/RB7), JP1.4
RC1: IC8.35 (T1OSI/RC1), R6.1
VCC: C3.1, C7.1, C8.1, IC1.2 (VOUT), IC1.4 (VOUT), IC8.7 (VDD), IC8.28 (VDD), JP1.2, R1.1, R2.1, R3.1, R4.1, R5.1, R8.1

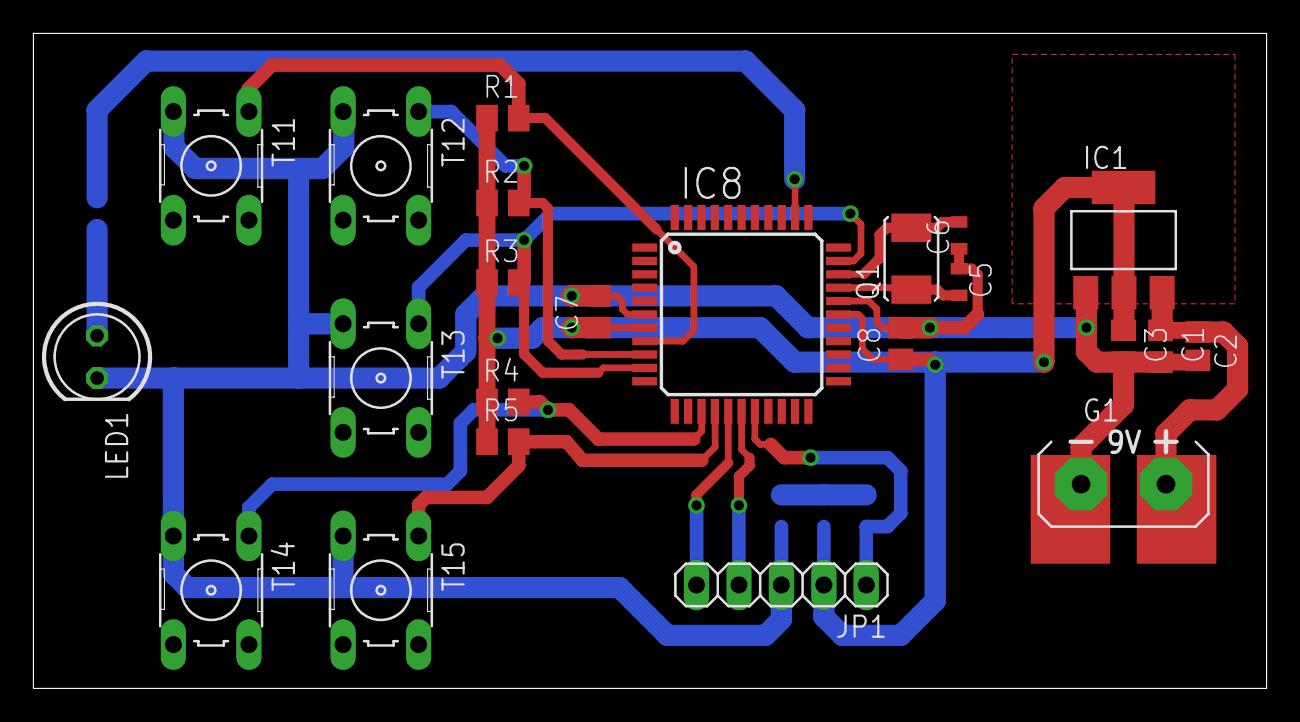
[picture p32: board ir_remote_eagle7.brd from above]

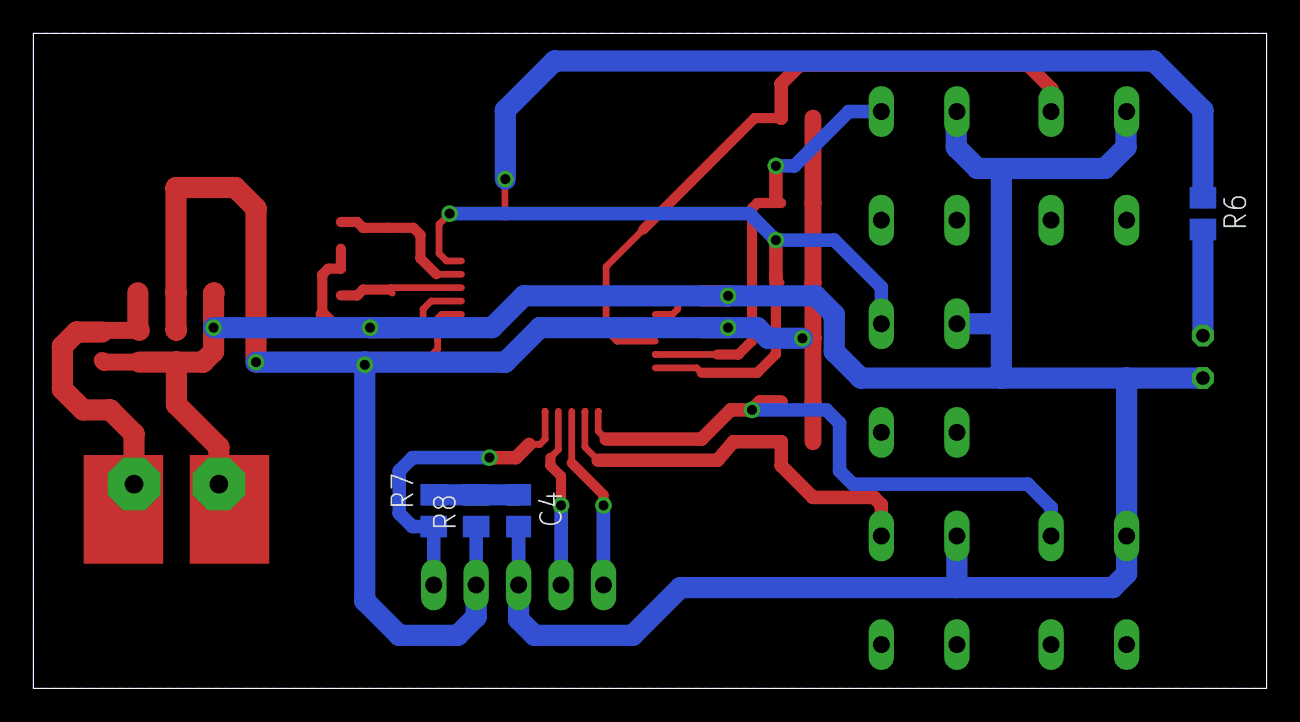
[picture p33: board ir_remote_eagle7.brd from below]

Board: 2 copper layers, 73.8 x 39.2 mm, 27 parts (4 on the bottom side), 16 nets.

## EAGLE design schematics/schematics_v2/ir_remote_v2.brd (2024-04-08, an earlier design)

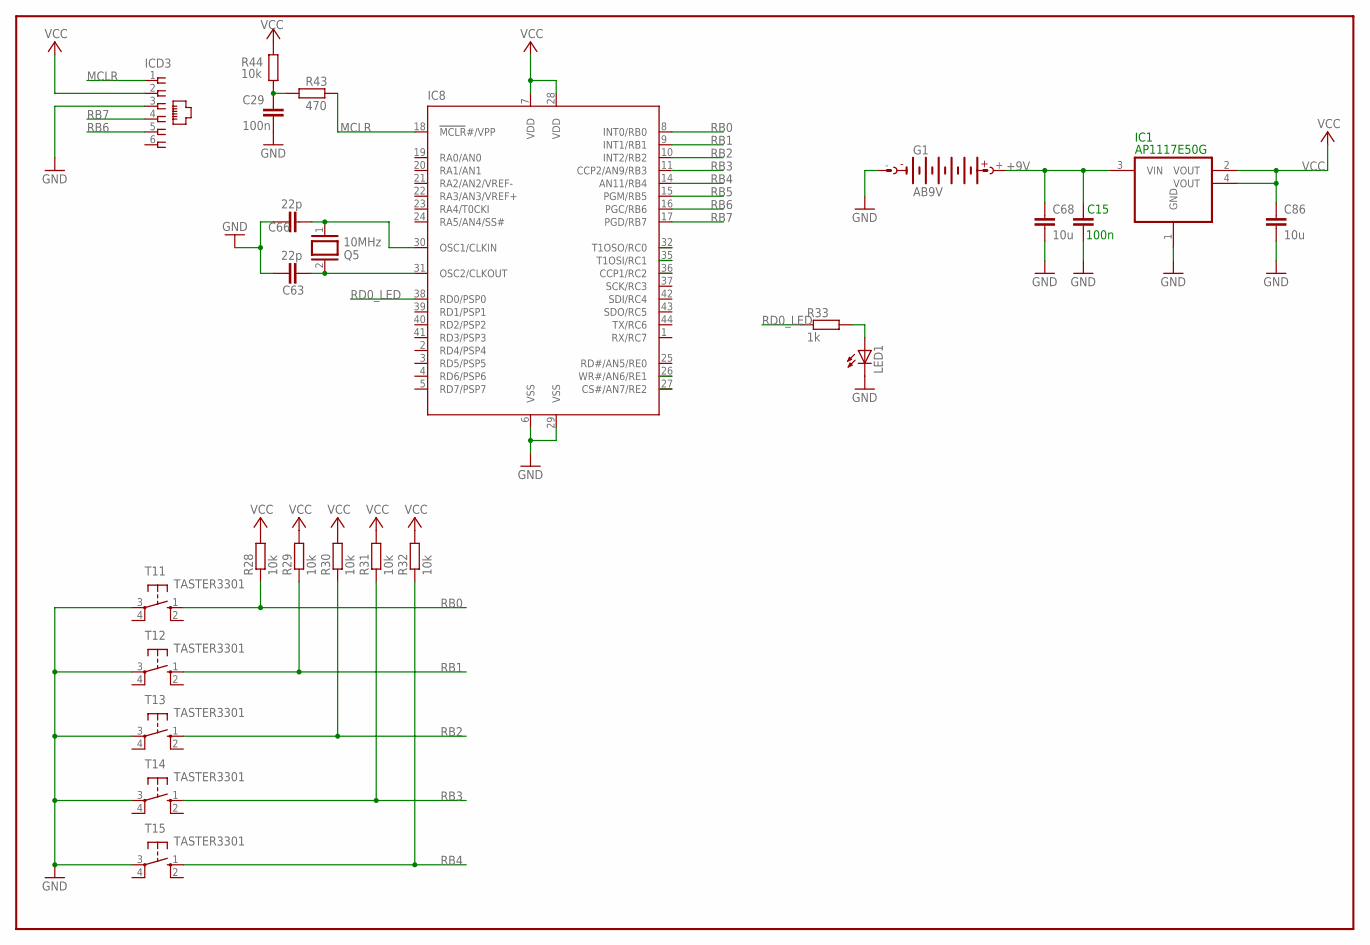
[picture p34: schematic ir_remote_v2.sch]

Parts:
C15, C29: 100n; C0805
C63, C66: 22p; C0603_WE
C68, C86: 10u; C0805
G1: AB9V
IC1: AP1117E50G; SOT223
IC8: PIC18F4520; TQFP44
ICD3: 520250-3
LED1: LED5MM
Q5: 10MHz; QUARZ_HC5032/2
R28, R29, R30, R31, R32: 10k; 0207/7
R33: 1k; 0207/10
R43: 470; M0805
R44: 10k; M0805
T11, T12, T13, T14, T15: TASTER3301

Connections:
+9V: C15.1, C68.1, G1.+, IC1.3 (VIN)
D0_LCD: IC8.27 (CS#/AN7/RE2)
D1_LCD: IC8.26 (WR#/AN6/RE1)
GND: C15.2, C29.2, C63.1, C66.1, C68.2, C86.2, G1.-, IC1.1 (GND), IC8.6 (VSS), IC8.29 (VSS), ICD3.3, LED1.K (C), T11.3, T12.3, T13.3, T14.3, T15.3
MCLR: IC8.18 (MCLR#/VPP), ICD3.1, R43.1
unnamed: LED1.A, R33.2
unnamed: C29.1, R43.2, R44.2
unnamed: C66.2, IC8.30 (OSC1/CLKIN), Q5.1
unnamed: C63.2, IC8.31 (OSC2/CLKOUT), Q5.2
RB0: IC8.8 (INT0/RB0), R28.1, T11.1 (S)
RB1: IC8.9 (INT1/RB1), IC8.35 (T1OSI/RC1), R29.1, T12.1 (S)
RB2: IC8.10 (INT2/RB2), IC8.32 (T1OSO/RC0), R30.1, T13.1 (S)
RB3: IC8.11 (CCP2/AN9/RB3), R31.1, T14.1 (S)
RB4: IC8.14 (AN11/RB4), R32.1, T15.1 (S)
RB5: IC8.15 (PGM/RB5)
RB6: IC8.16 (PGC/RB6), ICD3.5
RB7: IC8.17 (PGD/RB7), ICD3.4
RD0_LED: IC8.38 (RD0/PSP0), R33.1
RDS_INT: IC8.36 (CCP1/RC2)
VCC: C86.1, IC1.2 (VOUT), IC1.4 (VOUT), IC8.7 (VDD), IC8.28 (VDD), ICD3.2, R28.2, R29.2, R30.2, R31.2, R32.2, R44.1

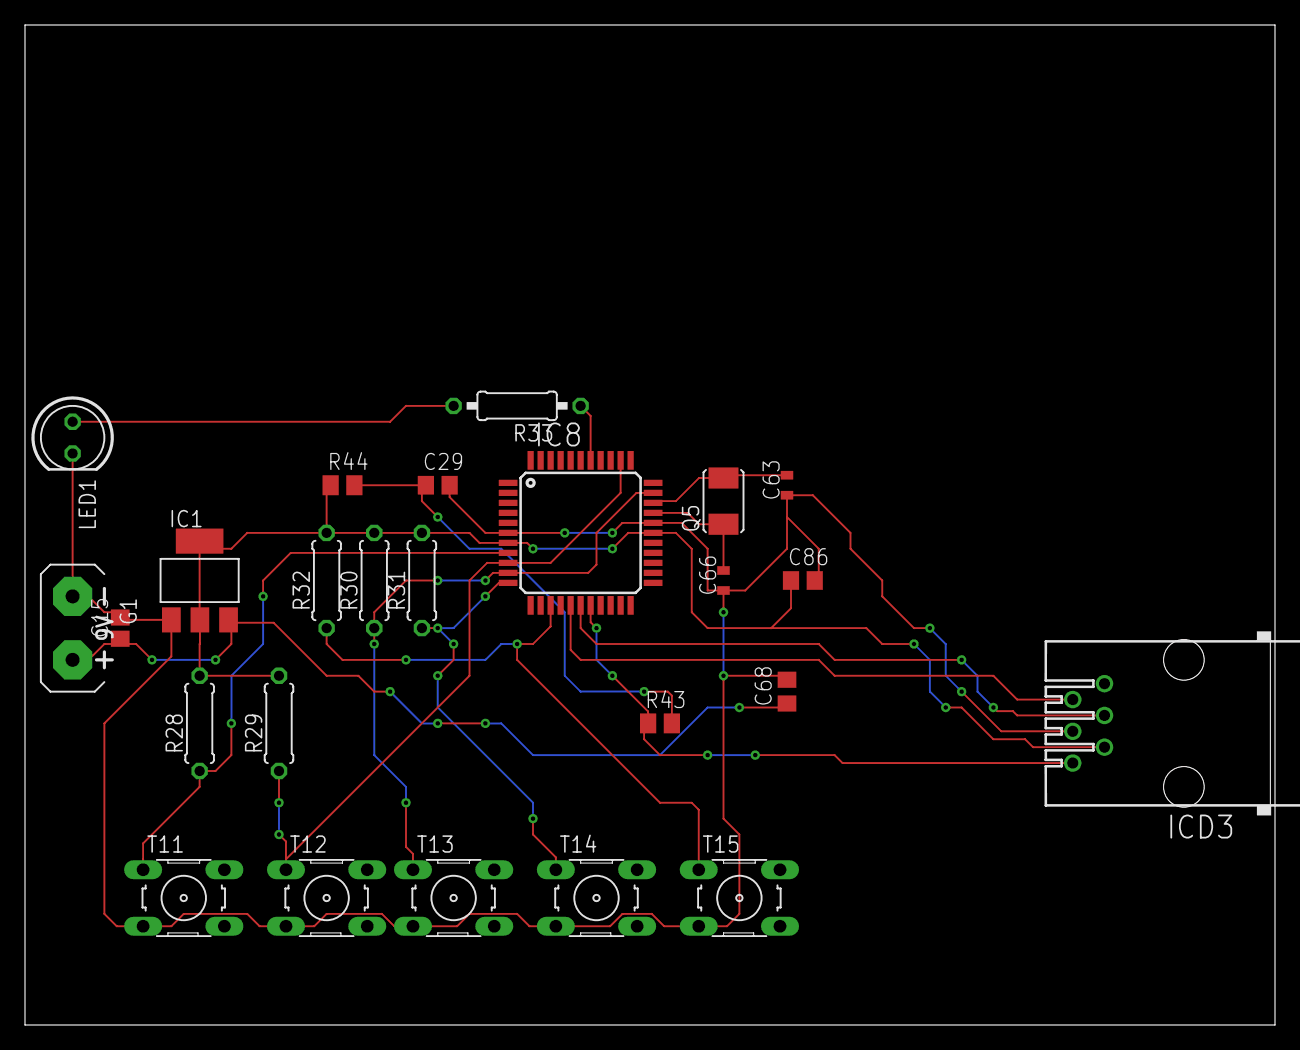
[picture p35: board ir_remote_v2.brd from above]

Board: 2 copper layers, 100.0 x 80.0 mm, 25 parts (0 on the bottom side), 16 nets.

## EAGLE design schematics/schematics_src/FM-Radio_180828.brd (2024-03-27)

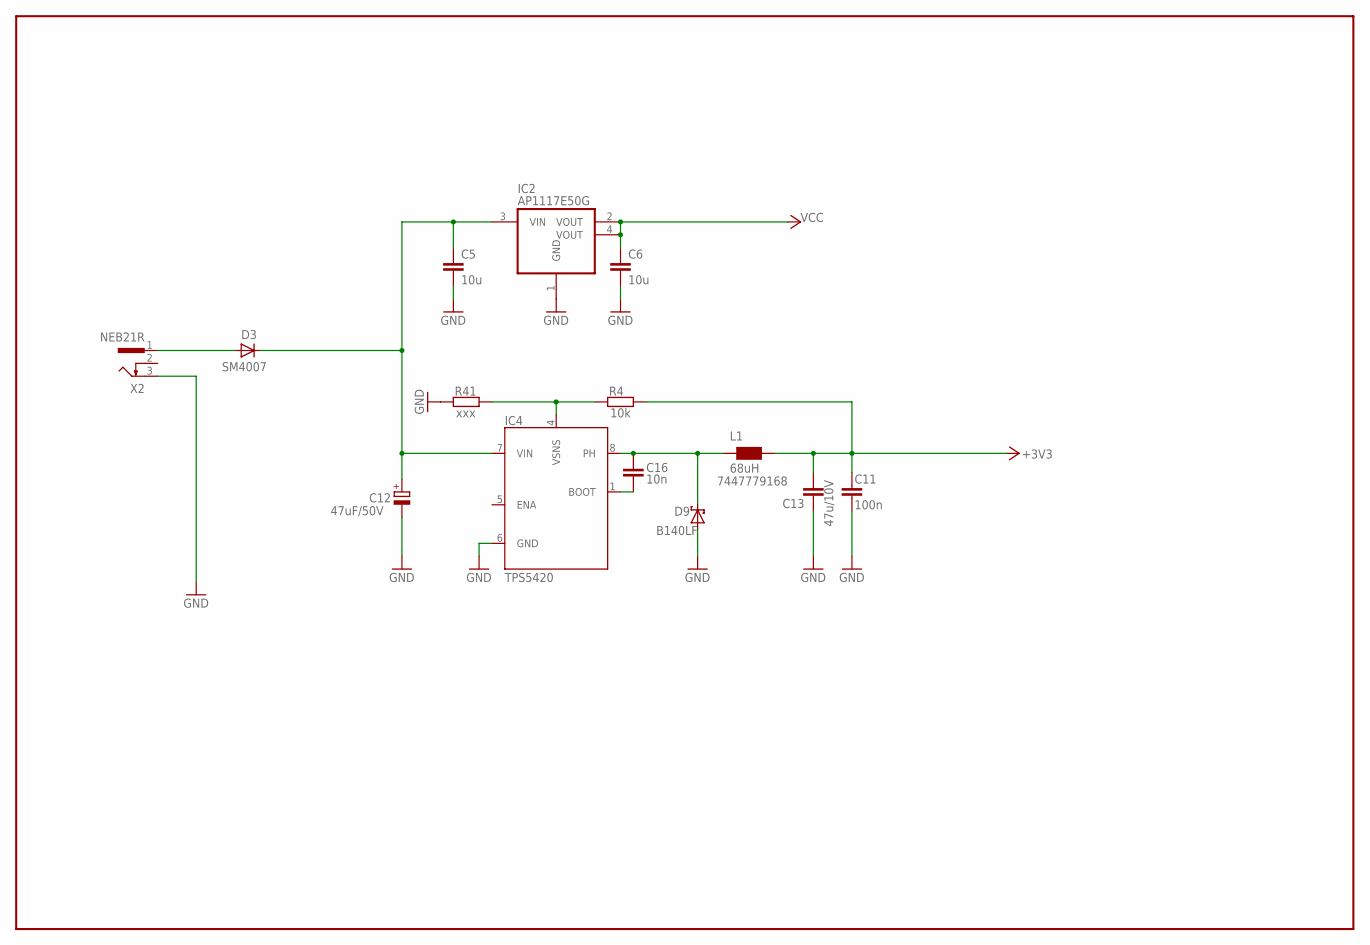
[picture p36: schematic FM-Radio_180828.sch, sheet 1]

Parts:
C5, C6: 10u; C0805
C11: 100n; C0805
C12: 47uF/50V; PANASONIC_D
C13: 47u/10V; C1210
C16: 10n; C0805
D3: SM4007; MELF
D9: B140LF; CD1607
IC2: AP1117E50G; SOT223
IC4: TPS5420; SO8
L1: 68uH; WE-PD_S/M
R4: 10k; R0805
R41: xxx; R0805
X2: NEB21R; FARNELL 1217037

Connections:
+3V3: C11.1, C13.1, L1.1 (2), R4.2; also elsewhere on the board
+9V: C5.1, C12.+, D3.C, IC2.3 (VIN), IC4.7 (VIN); also elsewhere on the board
GND: C5.2, C6.2, C11.2, C12.-, C13.2, D9.A, IC2.1 (GND), IC4.6 (GND), R41.1, X2.3; also elsewhere on the board
unnamed: D3.A, X2.1
unnamed: IC4.4 (VSNS), R4.1, R41.2
unnamed: C16.1, IC4.1 (BOOT)
unnamed: C16.2, D9.C, IC4.8 (PH), L1.2 (1)
VCC: C6.1, IC2.2 (VOUT), IC2.4 (VOUT); also elsewhere on the board

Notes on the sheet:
7447779168

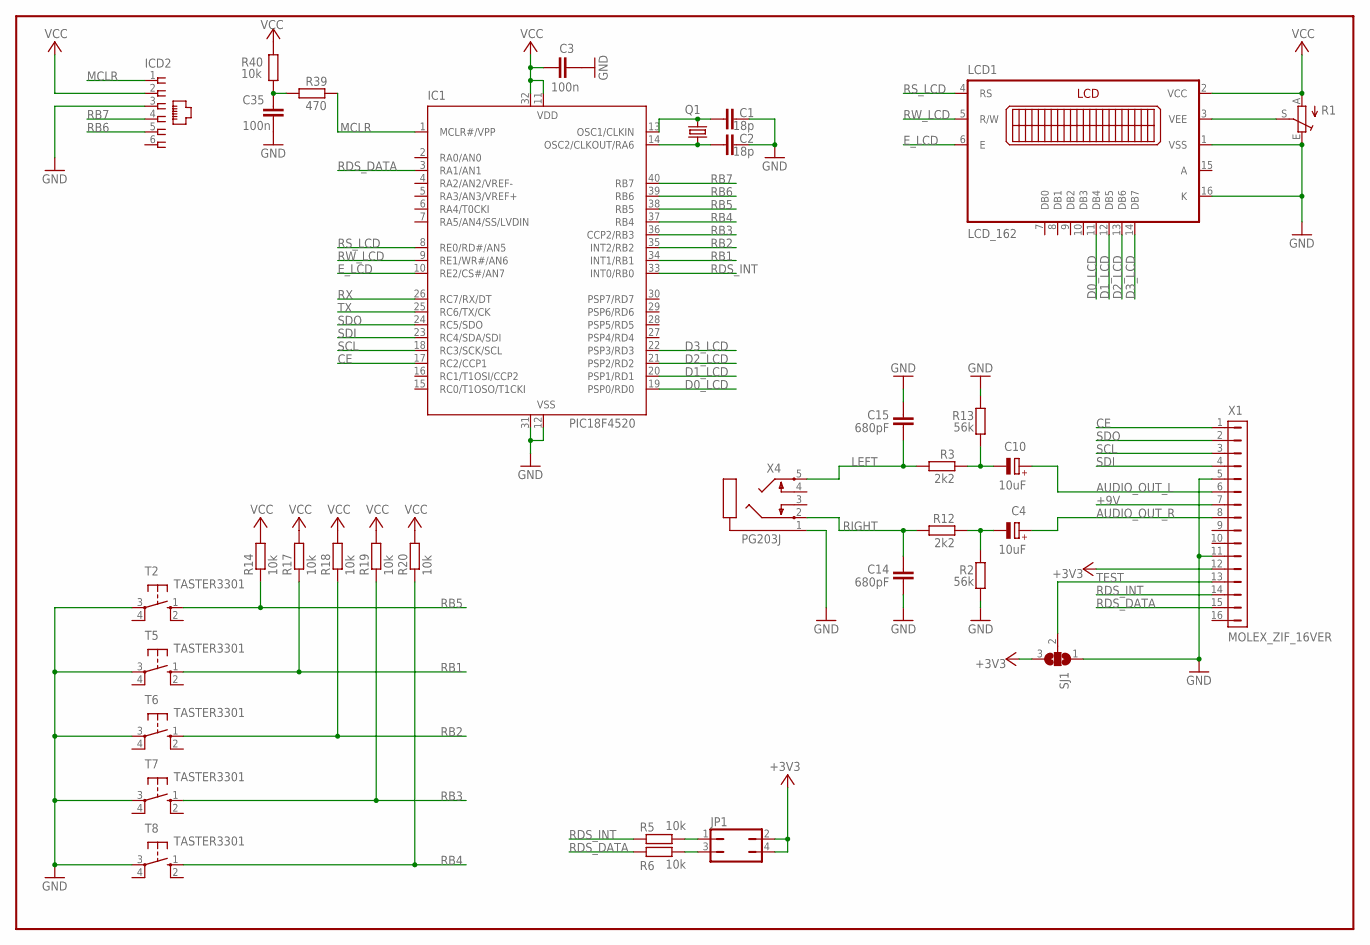
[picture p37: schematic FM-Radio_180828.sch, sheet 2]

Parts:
C1, C2: 18p; C0805
C3, C35: 100n; C0805
C4, C10: 10uF; TT2D4
C14, C15: 680pF; C025-025X050
IC1: PIC18F4520; DIL40
ICD2: 520250-3
JP1: JP2Q
LCD1: LCD_162
Q1: CRYTALHC49U-V; HC49U-V
R1: TRIM_EU-LI10; LI10
R2, R13: 56k; 0207/7
R3, R12: 2k2; 0207/7
R5, R6, R40: 10k; M0805
R14, R17, R18, R19, R20: 10k; 0207/7
R39: 470; M0805
SJ1: SJ2W; SJ_2
T2, T5, T6, T7, T8: TASTER3301
X1: MOLEX_ZIF_16VER; ZIF_16POL
X4: PG203J

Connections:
+3V3: JP1.2, JP1.4, SJ1.3, X1.12; also elsewhere on the board
+9V: X1.7; also elsewhere on the board
AUDIO_OUT_L: C10.+, X1.6
AUDIO_OUT_R: C4.+, X1.8
CE: IC1.17 (RC2/CCP1), X1.1
D0_LCD: IC1.19 (PSP0/RD0), LCD1.11 (DB4)
D1_LCD: IC1.20 (PSP1/RD1), LCD1.12 (DB5)
D2_LCD: IC1.21 (PSP2/RD2), LCD1.13 (DB6)
D3_LCD: IC1.22 (PSP3/RD3), LCD1.14 (DB7)
E_LCD: IC1.10 (RE2/CS#/AN7), LCD1.6 (E)
GND: C1.2, C2.2, C3.2, C14.1, C15.2, C35.2, IC1.12 (VSS), IC1.31 (VSS), ICD2.3, LCD1.1 (VSS), LCD1.16 (K), R1.E, R2.2, R13.1, SJ1.1, T2.3, T5.3, T6.3, T7.3, T8.3, X1.5, X1.11, X4.1; also elsewhere on the board
LEFT: C15.1, R3.1, X4.5
MCLR: IC1.1 (MCLR#/VPP), ICD2.1, R39.1
unnamed: C10.-, R3.2, R13.2
unnamed: JP1.1, R5.2
unnamed: JP1.3, R6.2
unnamed: C2.1, IC1.14 (OSC2/CLKOUT/RA6), Q1.1
unnamed: C1.1, IC1.13 (OSC1/CLKIN), Q1.2
unnamed: LCD1.3 (VEE), R1.S
unnamed: C4.-, R2.1, R12.2
unnamed: C35.1, R39.2, R40.2
RB1: IC1.34 (INT1/RB1), R17.1, T5.1 (S)
RB2: IC1.35 (INT2/RB2), R18.1, T6.1 (S)
RB3: IC1.36 (CCP2/RB3), R19.1, T7.1 (S)
RB4: IC1.37 (RB4), R20.1, T8.1 (S)
RB5: IC1.38 (RB5), R14.1, T2.1 (S)
RB6: IC1.39 (RB6), ICD2.5
RB7: IC1.40 (RB7), ICD2.4
RDS_DATA: IC1.3 (RA1/AN1), R6.1, X1.15
RDS_INT: IC1.33 (INT0/RB0), R5.1, X1.14
RIGHT: C14.2, R12.1, X4.2
RS_LCD: IC1.8 (RE0/RD#/AN5), LCD1.4 (RS)
RW_LCD: IC1.9 (RE1/WR#/AN6), LCD1.5 (R/W)
RX: IC1.26 (RC7/RX/DT)
SCL: IC1.18 (RC3/SCK/SCL), X1.3
SDI: IC1.23 (RC4/SDA/SDI), X1.4
SDO: IC1.24 (RC5/SDO), X1.2
TEST: SJ1.2, X1.13
TX: IC1.25 (RC6/TX/CK)
VCC: C3.1, IC1.11 (VDD), IC1.32 (VDD), ICD2.2, LCD1.2 (VCC), R1.A, R14.2, R17.2, R18.2, R19.2, R20.2, R40.1; also elsewhere on the board

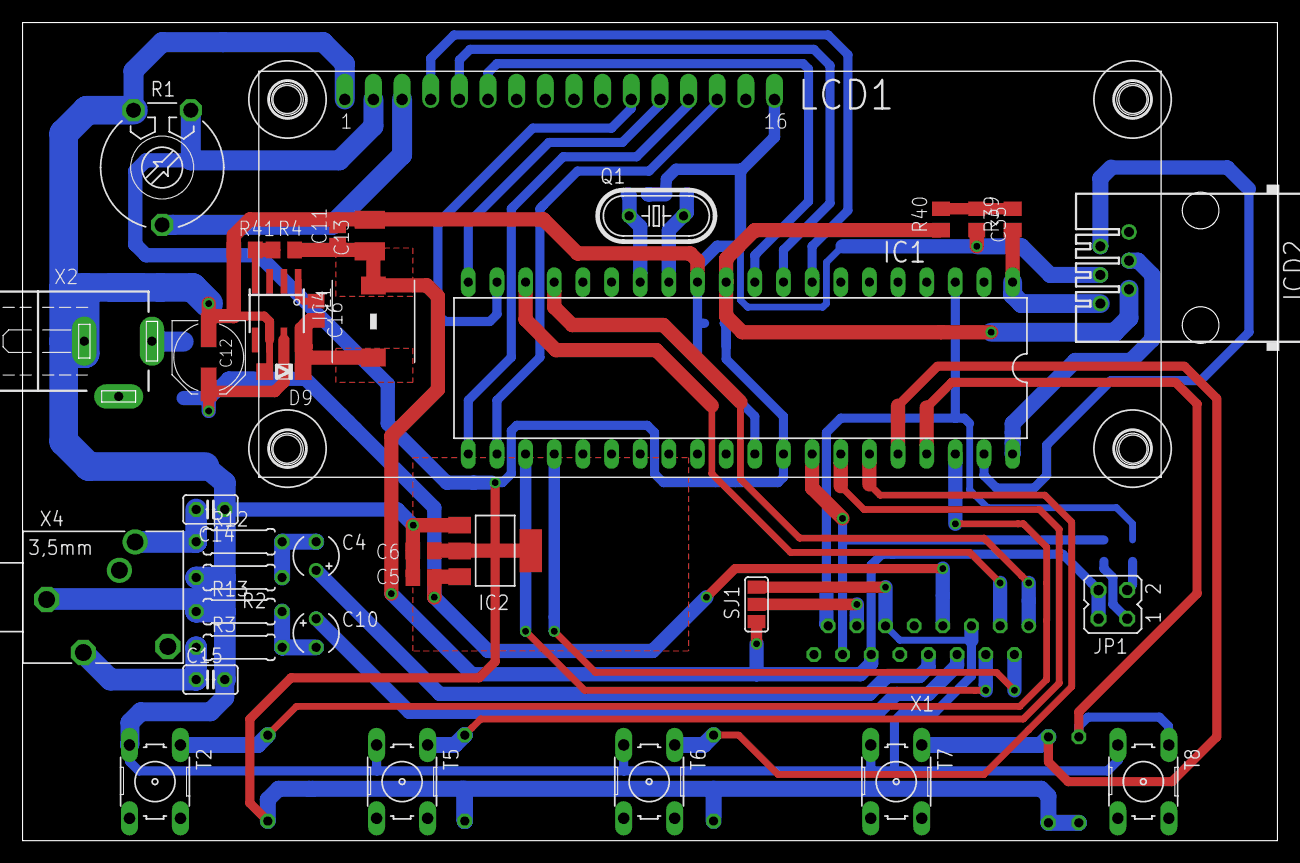
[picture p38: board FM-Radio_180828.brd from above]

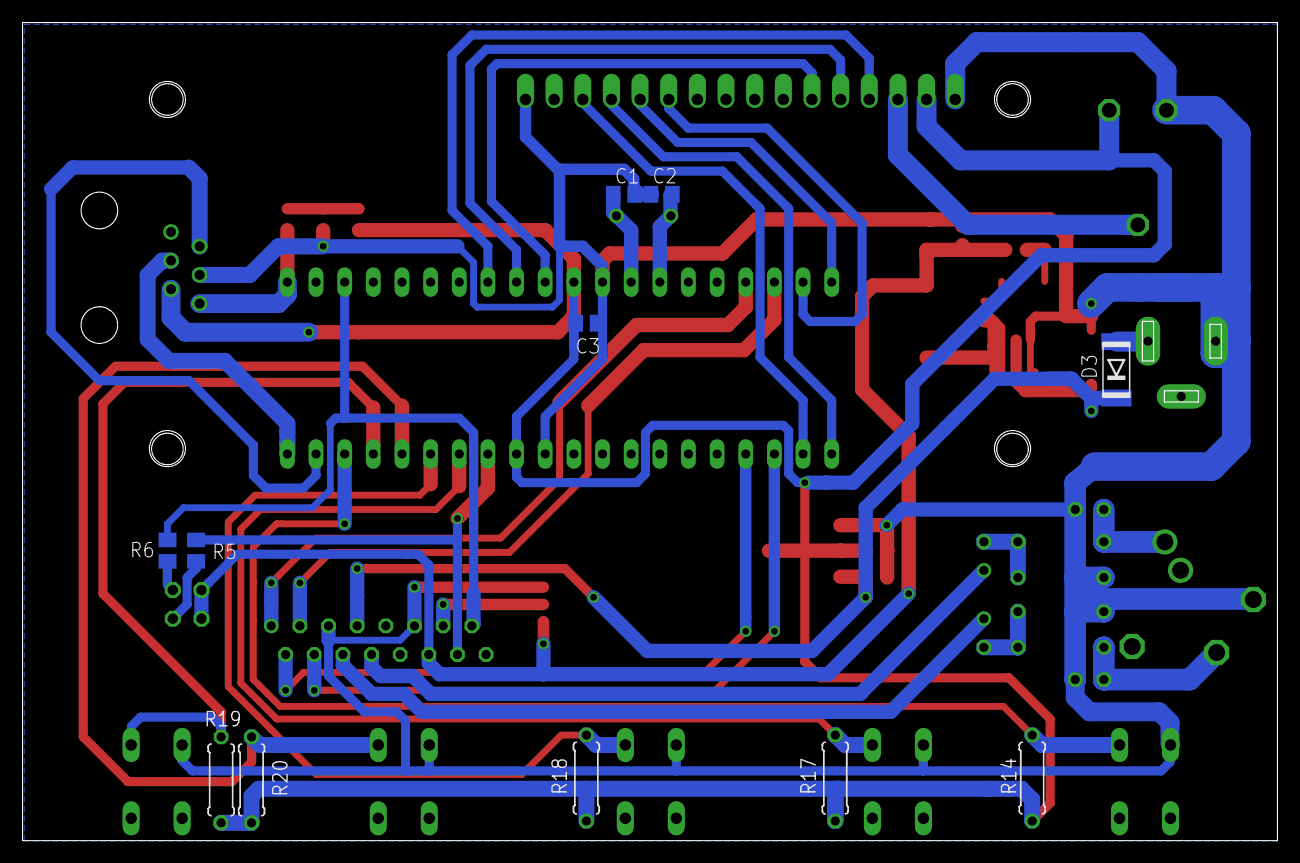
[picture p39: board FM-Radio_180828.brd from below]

Board: 2 copper layers, 111.3 x 72.5 mm, 53 parts (11 on the bottom side), 42 nets.

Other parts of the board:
U$3, U$4, U$5, U$7: 3,2

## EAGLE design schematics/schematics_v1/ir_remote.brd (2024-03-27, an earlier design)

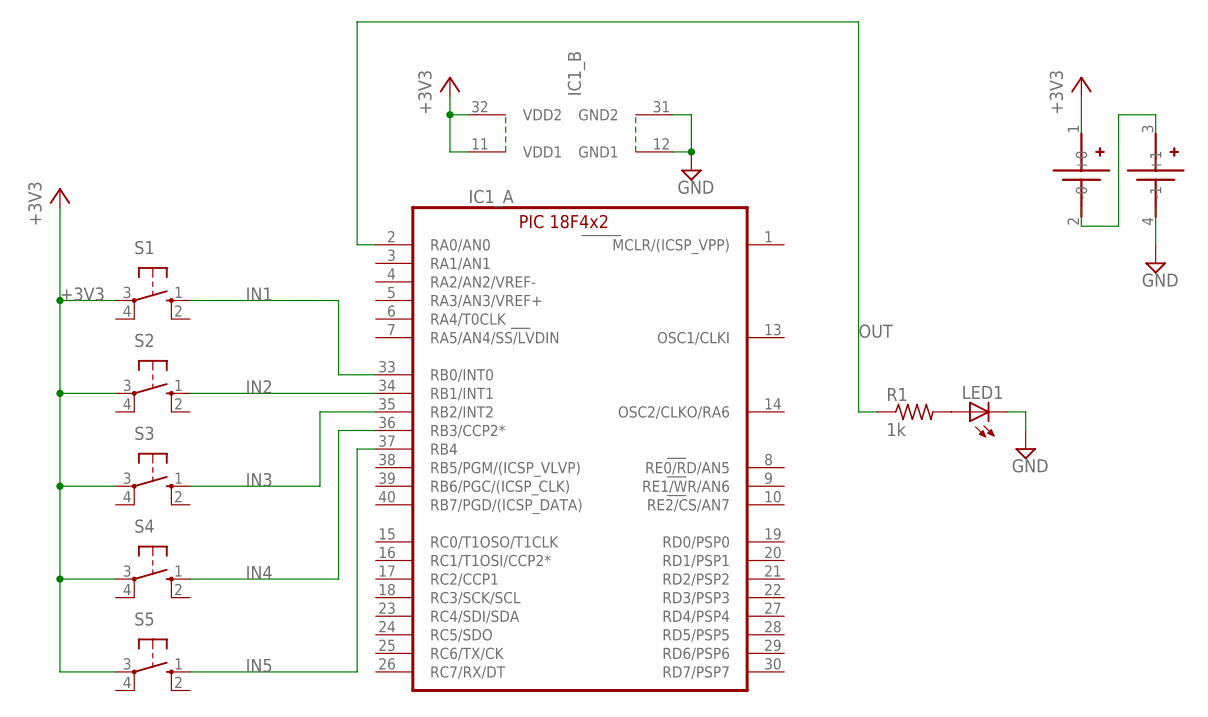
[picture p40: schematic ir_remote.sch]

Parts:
IC1: PIC18F4X2DIL40; DIL40
LED1: LED5MM
R1: 1k; 0207/12
S1, S2, S3, S4, S5: 10-XX; B3F-10XX
U$1: BLOSSOM-BLM-18650-2PCS

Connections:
+3V3: IC1.11 (VDD1), IC1.32 (VDD2), S1.3, S2.3, S3.3, S4.3, S5.3, U$1.1 (+0)
GND: IC1.12 (GND1), IC1.31 (GND2), LED1.K (C)
IN1: IC1.33 (RB0/INT0), S1.1 (S)
IN2: IC1.34 (RB1/INT1), S2.1 (S)
IN3: IC1.35 (RB2/INT2), S3.1 (S)
IN4: IC1.36 (RB3/CCP2*), S4.1 (S)
IN5: IC1.37 (RB4), S5.1 (S)
MCLR/(ICSP_VPP): IC1.1 (MCLR/(ICSP_VPP))
unnamed: LED1.A, R1.2
OSC1/CLKI: IC1.13 (OSC1/CLKI)
OSC2/CLKO/RA6: IC1.14 (OSC2/CLKO/RA6)
OUT: IC1.2 (RA0/AN0), R1.1

Board: 2 copper layers, 9 parts (0 on the bottom side), 9 nets, no tracks yet.

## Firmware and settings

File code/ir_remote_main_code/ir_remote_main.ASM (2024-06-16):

;******************************************************************************
;   This file is a basic template for assembly code for a PIC18F4525. Copy    *
;   this file into your project directory and modify or add to it as needed.  *
;                                                                             *
;   Refer to the MPASM User's Guide for additional information on the         *
;   features of the assembler.                                                *
;                                                                             *
;   Refer to the PIC18FX525/X620 Data Sheet for additional                    *
;   information on the architecture and instruction set.                      *
;                                                                             *
;******************************************************************************
;                                                                             *
;    Filename:                                                                *
;    Date:                                                                    *
;    File Version:                                                            *
;                                                                             *
;    Author:                                                                  *
;    Company:                                                                 *
;                                                                             * 
;******************************************************************************
;                                                                             *
;    Files Required: P18F4525.INC                                             *
;                                                                             *
;******************************************************************************

	LIST P=18F4525	;directive to define processor
	#include "P18F4525.INC"	;processor specific variable definitions

;******************************************************************************
;Configuration bits
;Microchip has changed the format for defining the configuration bits, please 
;see the .inc file for futher details on notation.  Below are a few examples.



;   Oscillator Selection:
    CONFIG	OSC = XT             ;LP

;******************************************************************************
;Variable definitions
; These variables are only needed if low priority interrupts are used. 
; More variables may be needed to store other special function registers used
; in the interrupt routines.

		bit_buffer_h equ 0x00
		bit_buffer_l equ 0x01
		bit_buffer_toggle equ 0x02
		
		bit_ctr equ 0x10

		command_ctr equ 0x11

		tmr_done equ 0x12
		

;******************************************************************************
;EEPROM data
; Data to be programmed into the Data EEPROM is defined here

		ORG	0xf00000

		DE	"Test Data",0,1,2,3,4,5

;******************************************************************************
;Reset vector
; This code will start executing when a reset occurs.

		ORG	0x0000

		goto	Main		;go to start of main code

;******************************************************************************
;High priority interrupt vector
; This code will start executing when a high priority interrupt occurs or
; when any interrupt occurs if interrupt priorities are not enabled.

		ORG	0x0008

		bra	HighInt		;go to high priority interrupt routine

;******************************************************************************
;Low priority interrupt vector and routine
; This code will start executing when a low priority interrupt occurs.
; This code can be removed if low priority interrupts are not used.

		ORG 0x0018
		
		bra LowInt

;******************************************************************************
;High priority interrupt routine
; The high priority interrupt code is placed here to avoid conflicting with
; the low priority interrupt vector.

HighInt:
		; toggle bit
		btg bit_buffer_toggle,0
		; test interrupt flags to identify pressed button
		btfsc INTCON,RBIF	; pin 4/5 pressed
		call send_rb_on_change
		btfsc INTCON,INT0IF	; pin 0 pressed
		call send_rb_0
		btfsc INTCON,INT1IF	; pin 1 pressed
		call send_rb_1
		btfsc INTCON,INT2IF	; pin 2 pressed
		call send_rb_2

		retfie	FAST

send_rb_on_change:
		; check if pin 4 or 5 was pressed
		btfsc PORTB,4
		call send_rb_4
		btfsc PORTB,5
		call send_rb_5
		bcf INTCON,RBIF
		return

send_rb_0:					; send stop command
		movlw b'00110101'
		movwf bit_buffer_h
		btfsc bit_buffer_toggle ; set toggle bit in bit buffer
		bsf bit_buffer_h,3
		movlw b'00110110'
		movwf bit_buffer_l
		bcf INTCON,INT0IF
		return

send_rb_1:					; send forward command
		movlw b'00110101'
		movwf bit_buffer_h
		btfsc bit_buffer_toggle,0 ; set toggle bit in bit buffer
		bsf bit_buffer_h,3
		movlw b'00110100'
		movwf bit_buffer_l
		bcf INTCON,INT1IF
		return

send_rb_2:					; send pause command
		movlw b'00110101'
		movwf bit_buffer_h
		btfsc bit_buffer_toggle ; set toggle bit in bit buffer
		bsf bit_buffer_h,3
		movlw b'00110000'
		movwf bit_buffer_l
		bcf INTCON,INT2IF
		return

send_rb_4:					; send play command
		movlw b'00110101'
		movwf bit_buffer_h
		btfsc bit_buffer_toggle ; set toggle bit in bit buffer
		bsf bit_buffer_h,3
		movlw b'00110101'
		movwf bit_buffer_l
		return

send_rb_5:					; send backward command
		movlw b'00110101'
		movwf bit_buffer_h
		btfsc bit_buffer_toggle ; set toggle bit in bit buffer
		bsf bit_buffer_h,3
		movlw b'00110010'
		movwf bit_buffer_l
		return

;******************************************************************************
;Low priority interrupt routine

LowInt:
		
		; stop timers
		bcf T0CON,TMR0ON
		bcf T2CON,TMR2ON
		
		bcf INTCON,TMR0IF

		; stop flag for delay loop
		bsf tmr_done,0

		retfie


;******************************************************************************
;Interrupt configuration routines
init_portb:
		; Routine f r INT0- INT2 
		clrf	 PORTB      
     
		bcf    ADCON0,ADON ; AD Converter disabled 
      
		movlw	0xFF
		movwf	TRISB  

		movlw	 0xFF
		movwf	 ADCON1
; Clear Interrupt flags 

    	bcf 	INTCON,INT0IF
		bcf		INTCON3,INT1IF
		bcf		INTCON3,INT2IF
    	bcf		INTCON,RBIF
    
    	bcf 	INTCON2,RBPU

; Enable Interrupts       
    	bsf 	INTCON,INT0IE
		bsf		INTCON3,INT1IE
		bsf		INTCON3,INT2IE
    	bsf		INTCON,RBIE

; Set edges in this case on falling edge 
    	bcf 	INTCON2,INTEDG0
    	bcf		INTCON2,INTEDG1
		bcf		INTCON2,INTEDG2

; Interrupt priority of int1 / 2 needs to be configured 

    	bsf 	INTCON,GIEH  
		bsf 	INTCON,GIEL 
      
		bsf 	RCON,IPEN ; Enables Priorities 

; Setting Priority high for INT1, INT2 
		bsf		INTCON3,INT2IP
		bsf		INTCON3,INT1IP
    	bsf		INTCON2,RBIP ; Low Priority for interrupt on change

		return

;******************************************************************************
; Output configuration routines

init_portc:
		; configure port c
		clrf PORTC
		clrf LATC
		clrf TRISC
		return

init_tmr:
		; configure pwm module
		banksel PR2
		movlw 0x44			; configure period time with 0x44
		movwf PR2

		movlw b'00000101' ;b'00000100'	; configure duty cycle with 0x11
		movwf CCPR2L
		movlw b'00101100' ;b'00011100'	; configure pwm mode and 2 lsbs of duty cycle
		movwf CCP2CON

		movlw b'00000000'
		movwf T2CON

		; configure timer 0 for delay
		movlw b'00001000'
		movwf T0CON
	
		bcf INTCON,TMR0IF ;interrupt flag
		bsf INTCON,TMR0IE ;interrupt enable
		bcf INTCON2,TMR0IP ;low priority interrupt
		bsf INTCON,GIE ;general interrupt enable

		;movlw 0x00
		;movwf tmr_done		

		return

init_i_o:
		; configure all remaining ports as inputs for sleep mode
		clrf 	PORTA
		movlw	0xFF
		movwf	TRISA
		clrf 	PORTD
		movlw	0xFF
		movwf	TRISD
		return


;******************************************************************************
; Helper sender routines
tmr_delay:
		;start timer 0 for pausing
		movlw 0xFF ; 0xF7
		movwf TMR0H
		movlw 0x52
		movwf TMR0L
		bsf T0CON,TMR0ON
		call delay_loop
		return

pwm_delay:
		;load timer 0 for half bit
		movlw 0xFF ; 0xF7
		movwf TMR0H
		movlw 0x52
		movwf TMR0L
		;load timer 2 for pwm
		movlw 0x00
		movwf TMR2
		bsf LATC,1 ;set first pulse manually

		bsf T0CON,TMR0ON
		bsf T2CON,TMR2ON

		call delay_loop

		return

;wait for interrupt to end half bit
delay_loop:
		btfss tmr_done,0
		bra delay_loop
		bcf tmr_done,0
		return
		

send_0:
		call tmr_delay
		call pwm_delay
		return

send_1:
		call pwm_delay
		call tmr_delay
		return

;******************************************************************************
; Main sender routine

send_command:
		;skip first two bits
		rlcf bit_buffer_l
		rlcf bit_buffer_h
		rlcf bit_buffer_l
		rlcf bit_buffer_h
		;init bit counter
		movlw d'14'
		movwf bit_ctr
		goto send_bit
		return

send_bit:
		rlcf bit_buffer_l
		rlcf bit_buffer_h
		btfss STATUS,C
		call send_0
		call send_1
		decfsz bit_ctr
		bra send_bit
		return


;******************************************************************************
;Start of main program
; The main program code is placed here.

Main:
		call init_portb
		call init_portc
		call init_tmr
		call init_i_o

		; temp: send command 256 times
		movlw 0xFF
		movwf command_ctr
		movlw 0x00
		movwf bit_buffer_toggle

		bcf OSCCON,IDLEN
go_to_sleep
		sleep
		nop
		call send_command
		decfsz command_ctr
		bra go_to_sleep




;******************************************************************************
;End of program
	goto $
		END

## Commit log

2024-03-27 Add first basic schematic
    [ir_remote.brd, ir_remote.sch]
2024-03-27 Modify directory structure
    [ir_remote.brd, ir_remote.sch]
2024-03-27 Add new schematics
    [FM-Radio_180828.brd, FM-Radio_180828.sch, PIC18F4520.sch]
2024-03-27 Add schematic_v2 including proper pic model, reset circuit, oscillator and power supply
    [FM-Radio_180828.brd, FM-Radio_180828.sch, PIC18F4520.sch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]
2024-03-27 Modify power supply with AP1117E50G replacing LM7805
    [ir_remote_v2.sch]
2024-04-03 Add files via upload
    Exchanging the Quartz on the Microcontroller
    [ir_remote_v2.sch]
2024-04-06 Add files via upload
    First placing of components and first wire
    [ir_remote_v2 (3).brd]
2024-04-07 Add files via upload
    First Layout - 12 DR - Errors
    [ir_remote_v2 (2).brd]
2024-04-08 Add files via upload
    PCB Layout - Fixed Design Rules, no recommendation from Volpe/Wegmann
    [ir_remote_v2 (2).brd]
2024-04-09 Create schematics_v3
2024-04-09 Add version 3 schematics including basic layout and improved circuitry
    [ir_remote_v3.brd, ir_remote_v3.sch]
2024-04-09 Update circuit layout
    [ir_remote_v3.brd]
2024-04-13 Clean up files in schematics v2
    [ir_remote_v2 (2).brd, ir_remote_v2 (3).brd, ir_remote_v2.brd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]
2024-04-14 Add files via upload
    Eagle Seminar with design tips, rules etc. for pcb layout
2024-04-16 Fix project directory structure
    [18F4525TEMP(1).ASM]
2024-04-17 Add files via upload
    IR-Remote Layout
    [ir_remote_v3.brd]
2024-04-21 Add files via upload
    ir_remote v3 cooling area patch of ic3
    [ir_remote_v3 (2).brd]
2024-04-22 Add schematics v4 with layout optimization
    [ir_remote_v4.brd, ir_remote_v4.sch]
2024-04-22 Improve schematics v4
    [ir_remote_v3.brd, ir_remote_v4.brd]
2024-04-23 Add schematics v5 directory structure
2024-04-23 Add schematics and layout for v5 including coupling caps and minor layout changes
    [ir_remote_v3.brd, ir_remote_v3.sch]
2024-04-26 Add schematics v5.2
    [ir_remote_v3.brd, ir_remote_v3.sch]
2024-05-04 Add minor modifications including ground and battery areas
    [ir_remote_v3.brd, ir_remote_v3.sch]
2024-05-04 Add minor changes to layout v5_3
    [ir_remote_v3.brd, ir_remote_v3.sch]
2024-05-07 Add bill of materials
    [bom.xlsx]
2024-05-08 Update config_int.asm
    schaltet aber nur led 1,2 an
2024-05-11 Update config_int.asm
    Add con anpassung und reihen folge int
2024-05-13 Test pwm code
2024-05-15 Update config_int.asm
    Das Programm schaltet leds an und geht in den interrupt nur kann der Pin wert nicht zuverlässig ausgelesen werden
2024-05-16 Add dimensions for schematics v5.3
    [ir_remote_v3.brd]
2024-05-21 Add pwm
    [ir_remote_v3.brd, ir_remote_v3.sch]
2024-05-22 Add final schematics and layout v6
    [ir_remote_v3.brd, ir_remote_v3.sch]
2024-05-23 Add sender for rc5 signal with pwm on timer 2 and half bit with timer 0
2024-06-02 Add files via upload
    Final schematics, correcting some basic errors
    [ir_remote_eagle7.brd]
2024-06-02 Add files via upload
    All Pins on PortB enabled as interrupts, needs to be tested
2024-06-02 Add files via upload
    Int 0 - 2 as high interrupts, interrupts 1&2 need to be tested, no software polling to find out what pin caused interrupt
2024-06-04 Add code to send pic to sleep and wake up again with high priority service interrupt routine
2024-06-05 Update INT-2&RBonChange.txt
    Schnittstelle iengefügt, kann aber kein Taster interrupt beim demoboard auslösen, hardware??
2024-06-06 Add prototype for full asm code in code/ir_remote_main_code directory
2024-06-13 Test algorithm and emulate longer button press
2024-06-16 Add tests for ir remote board.
2024-06-18 Add pwm pulse with correct frequency and 32 single pulses
    [18F4525TEMP(1).ASM]
2024-06-18 Add button interrupt to start pwm pulses
2024-06-18 Add most of the working code so that buttons send command
2024-06-27 Add toggle bit to all commands (not working yet)
    [test_all_commands_toggle.ASM]
2024-06-29 Finish code with comments and prettier form. This code may fail, in this case, the previous commit should be used as checkpoint.
    [test_all_commands.ASM]
2024-06-30 Update test_all_commands.ASM
    high int: deleted unnecessary interrupt flag clearing
2024-07-02 Add final touches to doc
    [ir_remote_eagle7.sch]
